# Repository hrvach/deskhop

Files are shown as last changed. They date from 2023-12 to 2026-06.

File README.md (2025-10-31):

# DeskHop - Fast Desktop Switching

Did you ever notice how, in the crazy world of tech, there's always that one quirky little project trying to solve a problem so niche that its only competitors might be a left-handed screwdriver and a self-hiding alarm clock?

I use two different computers in my daily workflow and share a single keyboard/mouse pair between them. Trying several USB switching boxes found on Amazon made me realize they all suffer from similar issues - it takes a while to switch, the process is quite clumsy when trying to find the button and frankly, it just doesn't get any better with time.

All I wanted was a way to use a keyboard shortcut to quickly switch outputs, paired with the ability to do the same by magically moving the mouse pointer between monitors. This project enables you to do both, even if your computers run different operating systems!

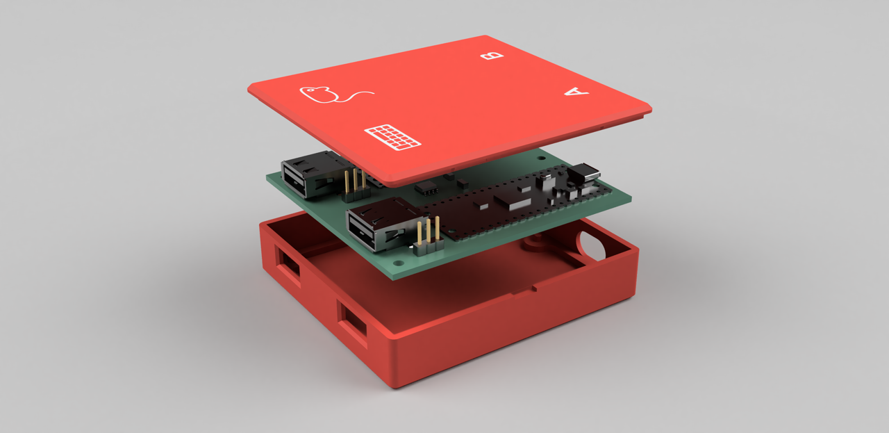
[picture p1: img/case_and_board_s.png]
DeskHop case and board


## Features

- Completely **[free and open source](https://certification.oshwa.org/de000149.html)**
- No noticeable delay when switching
- Simply drag the mouse pointer between computers
- No software installed
- Affordable and obtainable components (<15€)
- 3D printable snap-fit case
- Full Galvanic isolation between your outputs
- Works with Linux, macOS and Windows

[User Manual](misc/user-manual.pdf) is now available

Open Source Hardware Logo

------

## How it works

The device acts as an intermediary between your keyboard/mouse and the computer, establishing and maintaining connections with both computers at once. Then it chooses where to forward your mouse and keystrokes to, depending on your selection. Keyboard follows the mouse and vice versa, so just dragging the mouse to the other desktop will switch both.

## Mouse

To get the mouse cursor to magically jump across, the mouse hid report descriptor was changed to use absolute coordinates and then the mouse reports (that still come in relative movements) accumulate internally, keeping the accurate tally on the position.

When you try to leave the monitor area in the direction of the other monitor, it keeps the Y coordinate and swaps the maximum X for a minimum X, then flips the outputs. This ensures that the cursor seamlessly appears at the same height on the other monitor, enhancing the perception of a smooth transition.

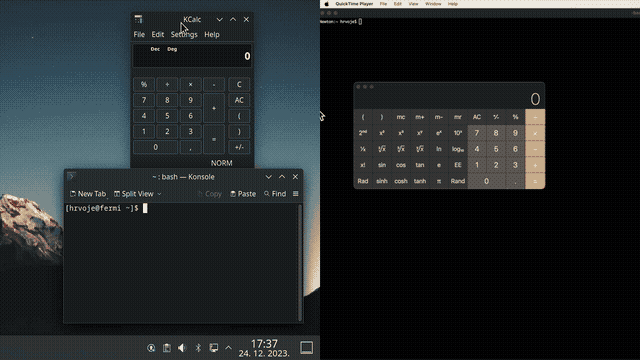
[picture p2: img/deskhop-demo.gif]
DeskHop Mouse Demo


<p align="center"> Dragging the mouse from Mac to Linux automatically switches outputs. </p>

------

The actual switch happens at the very moment when one arrow stops moving and the other one starts.

## Keyboard

Acting as a USB Host and querying your keyboard periodically, it looks for a preconfigured hotkey in the hid report (usually Ctrl + Caps Lock for me). When found, it will forward all subsequent characters to the other output.

To have a visual indication which output you are using at any given moment, you can repurpose keyboard LEDs and have them provide the necessary feedback.

It also remembers the LED state for each computer, so you can pick up exactly how you left it.

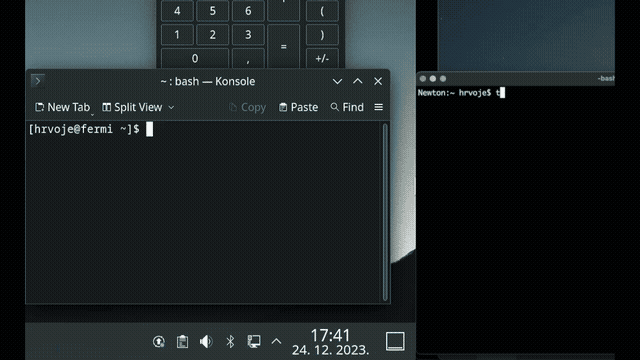
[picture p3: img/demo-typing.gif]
DeskHop Typing Demo


## How to build

To avoid version mismatch and reported path issues when building, as well as to save you from having to download a large SDK, the project now bundles minimal pico sdk and tinyusb.

On a Debian/Ubuntu systems, make sure to install these:

```shell
apt update
apt install \
    build-essential \
    cmake \
    gcc-arm-none-eabi \
    libnewlib-arm-none-eabi \
    python3
```

You should be able to build by running:

```shell
cmake -S . -B build
cmake --build build
```

additionally, to rebuild web UI check webconfig/ and execute ```./render.py```, you'll need jinja2 installed.

An alternative can be to use docker via 'docker compose' or 'docker-compose':
```
docker-compose -f misc/docker.yml run --rm build_container
```
This ensures reproducible builds.

To rebuild the disk, check disk/ folder and run ```./create.sh```, tweak to your system if needed. You'll need **dosfstools** (to provide mkdosfs),

## Using a pre-built image

Alternatively, you can use the [pre-built images](https://github.com/hrvach/deskhop/releases). Since version 0.6 there is only a single universal image. You need the .uf2 file which you simply copy to the device in one of the following ways:

## Upgrading firmware

**Option 1** - (firmware 0.6 and later) Put the device in "config mode" by simultaneously pressing **left ctrl + right shift + c + o**. Device your keyboard is plugged into will reboot and turn into a USB drive called "DESKHOP". All you need to do is copy the .uf2 file to it. Once image is verified, device will flash and reboot, then proceed to upgrade the other board. During this operation the led will blink. Once it's done, it will write flash and reboot, completing the operation.

_Note_ - This is not an actual generic USB drive, you can't use it to copy files to it.

**Option 2** - Using the ROM bootloader - hold the on-board button while connecting each Pico and copy the uf2 to the flash drive that appears. Images later than 0.6 support holding the button without having to fiddle around the power supply, but the "hold button while plugging" should always work, regardless of device state.

**Option 3** - CDC Flash Command (Debug builds only) - If the firmware was built with `DH_DEBUG_CDC_FLASH=ON`, you can trigger bootloader mode via CDC serial command:
```shell
echo -n 'flash' > /dev/tty.usbmodem11104
```
This immediately resets the device into bootloader mode where it appears as "RPI-RP2" drive. This feature is intended for development workflows.

## Misc features

### Mouse slowdown

Ever tried to move that YT video slider to a specific position but your mouse moves too jumpy and suddenly you are moving your hand super-carefully like you're 5 and playing "Operation" all over again?

**Press right CTRL + right ALT** to toggle a slow-mouse mode. The mouse pointer will slow down considerably, enabling you to get the finer precision work done and still have your mouse moving normally by quickly pressing the same keys again.

### Switch Lock

If you want to lock yourself to one screen, use ```RIGHT CTRL + K```.
This will make sure you won't accidentally leave your current screen. To turn off, press the same key combo again.

### Lock Both Screens

You can lock both computers at once by using ```RIGHT CTRL + L```.
To make use of this feature, first set up the OS for each output in config (since the shortcuts are different).

### Gaming Mode

If you're gaming, there is a chance your game might not work properly with absolute mouse mode. To address that issue, a **gaming mode** is introduced, toggled by ```LEFT CTRL + RIGHT SHIFT + G```. When in gaming mode, you are locked to the current screen and your mouse behaves like a standard relative mouse. This should also fix various virtual machine issues, currently unsupported operating systems etc.

### Screensaver

Supposedly built in to prevent computer from entering standby, but truth be told - it is just fun to watch. **Off by default**, will make your mouse pointer bounce around the screen like a Pong ball. When enabled, it activates after a period of inactivity defined in user config header and automatically switches off as soon as you send any output towards that screen.

Potential usage example - I have a buggy USB dock that won't resume video from standby, so not allowing it to sleep can be a handy workaround.

## Hardware

[The circuit](schematics/DeskHop_v1.1.pdf) is based on two Raspberry Pi Pico boards, chosen because they are cheap (4.10 € / pc), can be hand soldered and most suppliers have them in stock.

The Picos are connected using UART and separated by an Analog Devices ADuM1201 dual-channel digital isolator (~3€) or a much cheaper, faster and pin-compatible TI ISO7721DR (~1.5€) which is the preferred choice.

While they normally don't have support for dual USB, thanks to an [amazing project](https://github.com/sekigon-gonnoc/Pico-PIO-USB) where USB is implemented using the programmable IO wizardry found in RP2040, there is support for it to act both as an USB host and device.

## PCB [updated]

To keep things as simple as possible for DIY builds, the traces were kept on one side and the number of parts kept to a minimum.

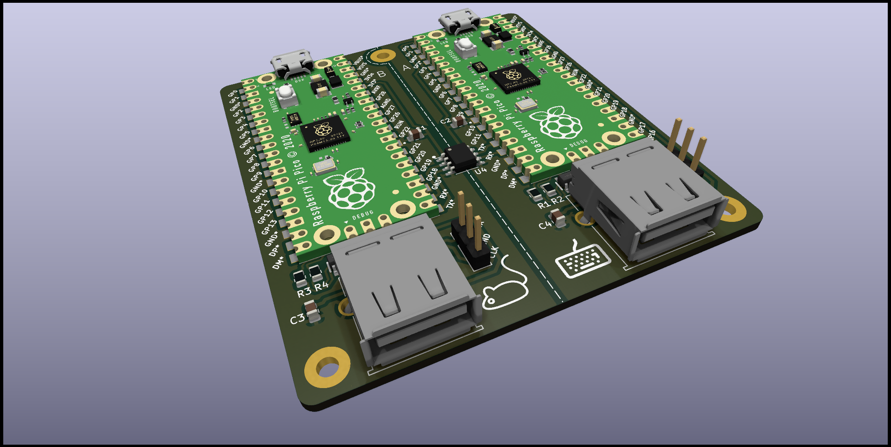
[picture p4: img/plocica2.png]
PCB Image


USB D+/D- differential lines should be identical in length, but they are slightly asymmetrical on purpose to counter the length difference on the corresponding GPIO traces PICO PCB itself, so the overall lengths should match.

Zd (differential impedance) is aimed as 90 ohm (managed to get ~107, close enough :)).

The thickness is designed to be 1.6 mm for snap-fit to work as expected.

There are 2 versions of the PCB (no major differences for the user). Original (v1.0) is easier to solder and assemble, while v1.1 offers some upgrades like:

- added ESD protection (TPD4E1U06DBVR)
- added VBUS capacitor for the keyboard/mouse connectors
- silkscreen orientation markings
- holes for clone boards with headers pre-soldered and easier alignment
- USB 27 ohm resistors

  This version is slightly more difficult to hand solder due to the small transient voltage suppressor IC and 0805 resistors, but it's totally doable. TVS can in theory be omitted (not advised) and it will still work.

Upcoming - board with bare rp2040s that doesn't need Picos, is smaller and more convenient.

## Case

Since I'm not very good with 3d, the case is [simple and basic](case/) but does the job. It should be easy to print, uses ~33g of filament and takes a couple of hours.

Horizontal PCB movements are countered by pegs sliding through holes and vertical movements by snap-fit lugs on the sides - no screws required. The case was given a slight redesign to feature the logo and two additional snap-fit lugs, so it provides a better seal.

Micro USB connectors on both boards are offset from the side of the case, so slightly larger holes should allow for cables to reach in.

The lid is of a snap-fit design, with a screwdriver slot for opening. The markings on top are recessed and can be finished with e.g. crayons to give better contrast (or simply left as-is).

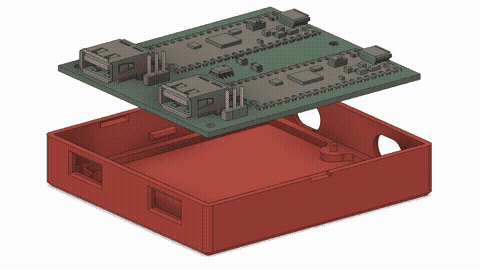
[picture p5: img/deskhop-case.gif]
DeskHop with 3D Printed Case


## Bill of materials

<details closed>
  <summary>Click here to view original PCB v1.0 BOM</summary>

| Component | Qty | Unit Price / € | Price / €|
|---|-----|---|---|
| Raspberry Pi Pico  | 2 | 4.10 | 8.20 |
| ADuM1201BRZ | 1 | 2.59 | 2.59 |
| Cap 1206 SMD 100nF | 2 | 0.09 | 0.18 |
| USB-A PCB conn. | 2 | 0.20 | 0.40 |
| Headers 2.54 1x03  | 2 | 0.08 | 0.16 |
| | | | |
| | | Total | 11.53 |

TI ISO7721DR can be used instead of the ADuM - it's pin-compatible, much cheaper and with better specs.

</details>

### PCB v1.1

| Component | Part | Qty | Unit Price / € | Price / €|
|---|---|-----|---|---|
| U1, U2 | Raspberry Pi Pico | 2 | 4.10 | 8.20 |
| J1, J4 | USB-A PCB conn. | 2 | 0.20 | 0.40 |
| U4 | TI ISO7721DR | 1 | 1.40 | 1.40 |
| | (**OR** ADuM1201BRZ)| | | |
| C1, C2 | Cap 0805 SMD 100nF  | 2 | 0.09 | 0.18 |
| R1, R2, R3, R4 | Res 0805 SMD 27ohm  | 4 | 0.03 | 0.12 |
| U3, U5 | TPD4E1U06DBVR | 2 | 0.31 | 0.62 |
| C3, C4 | Cap 4.7uF SMD 0805  | 2 | 0.07 | 0.14 |
| J2, J3 | Headers 2.54 1x03 | 2 | 0.08 | 0.16 |
| | | | | |
| | | | Total | 11.22 |

USB-A connector can be Molex MX-67643-0910 or a cheaper/budget one that shares the same dimensions.

Additional steps:

- making the PCB ([Gerber provided](pcb/), choose 1.6 mm thickness)
- 3d printing the case ([stl files provided](case/), ~33g filament)

## Assembly guide

If you have some experience with electronics, you don't need this. However, some of you might not, and in that case this video might help guide you through the process. Please note, after soldering you should clean the flux from the PCB to prevent corrosion.

The standard process to do that is using isopropyl alcohol and an old toothbrush. But guess what? I'm not putting my old toothbrush online, so you'll just have to improvise that part :)

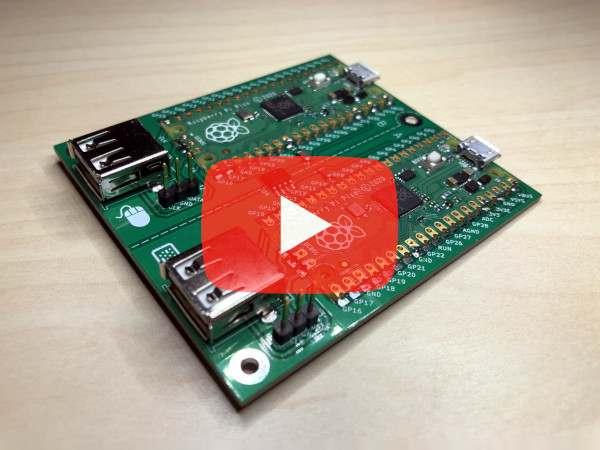
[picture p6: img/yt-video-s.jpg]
PCB Assembly Guide (https://www.youtube.com/watch?v=LxI9NYi_oOU)


[NOTE] The video assembly guide covers pcb v1.0. The revised version is very similar and the procedure is basically the same.

## Usage guide

### Keyboard shortcuts - (fw versions 0.68+)

_Config_:

- ~~```Left Shift```~~ ```Left Ctrl + Right Shift + C + O``` - enter config mode
- ```Right Shift + F12 + D``` - remove flash config
- ```Right Shift + F12 + Y``` - save screen switch offset

_Usage_:

- ```Right CTRL + Right ALT``` - Toggle slower mouse mode
- ```Right CTRL + K``` - Lock/Unlock mouse desktop switching
- ```Right CTRL + L``` - Lock both outputs at once (set output OS before, see shortcuts below)
- ~~```Left Shift```~~ ```Left CTRL + Right Shift + G``` - Toggle gaming mode (lock to screen, act as standard mouse)
- ```Left CTRL + Right Shift + S``` - Enable screensaver
- ```Left CTRL + Right Shift + X``` - Disable screensaver
- ```Left CTRL + Caps Lock``` - Switch between outputs

Note: some keyboards don't send both shifts at the same time properly, that's why the shortcut was changed - to work for everyone. Apologies for the confusion.

### Switch cursor height calibration

This step is not required, but it can be handy if your screens are not perfectly aligned or differ in size. The objective is to have the mouse pointer come out at exactly the same height.

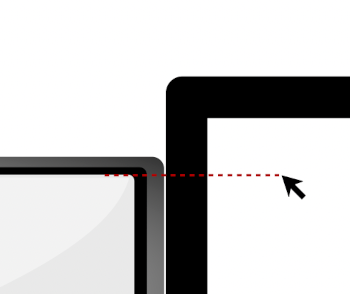
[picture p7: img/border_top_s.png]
Border height difference


Just park your mouse on the LARGER screen at the height of the smaller/lower screen (illustrated) and press ```Right Shift + F12 + Y```. Your LED (and caps lock) should flash in confirmation.

Repeat for the bottom border (if it's above the larger screen's border). This will get saved to flash and it should keep this calibration value from now on.

### Multiple screens per output

Windows and Mac have issues with multiple screens and absolute positioning, so workarounds are needed (still experimental). There is a better workaround under construction, but for now you have to set the operating system for each output and number of screens.

Your main screens need to be in the middle, and secondary screen(s) on the edges. To configure the actual options, open the web configuration page for your device.

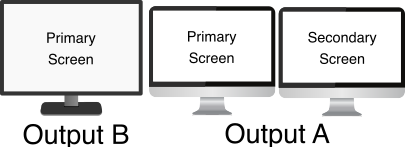
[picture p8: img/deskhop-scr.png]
Multiple screens per output


### Web configuration mode

Starting with fw 0.6, an improved configuration mode is introduced. To configure your device, follow these instructions:

1. Press Left Ctrl + Right Shift + C + O - your device will reboot and enter configuration mode (on the side your keyboard is plugged into). LED will keep blinking during the configuration session.

1. A new USB drive will appear named "DESKHOP" with a single file, config.htm

1. Open that file with Chromium / Chrome. Unfortunately FF is not supported right now, since they avoid implementing WebHID.

1. Click connect and allow deskhop device to pair.

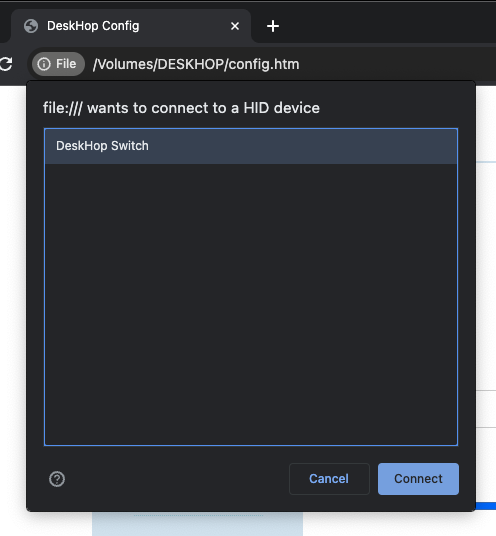
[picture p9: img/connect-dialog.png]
Web Browser with URL
   

1. Configure the options as you wish and click save to write to device.

1. Click "exit" in the menu to leave configuration mode for added safety.

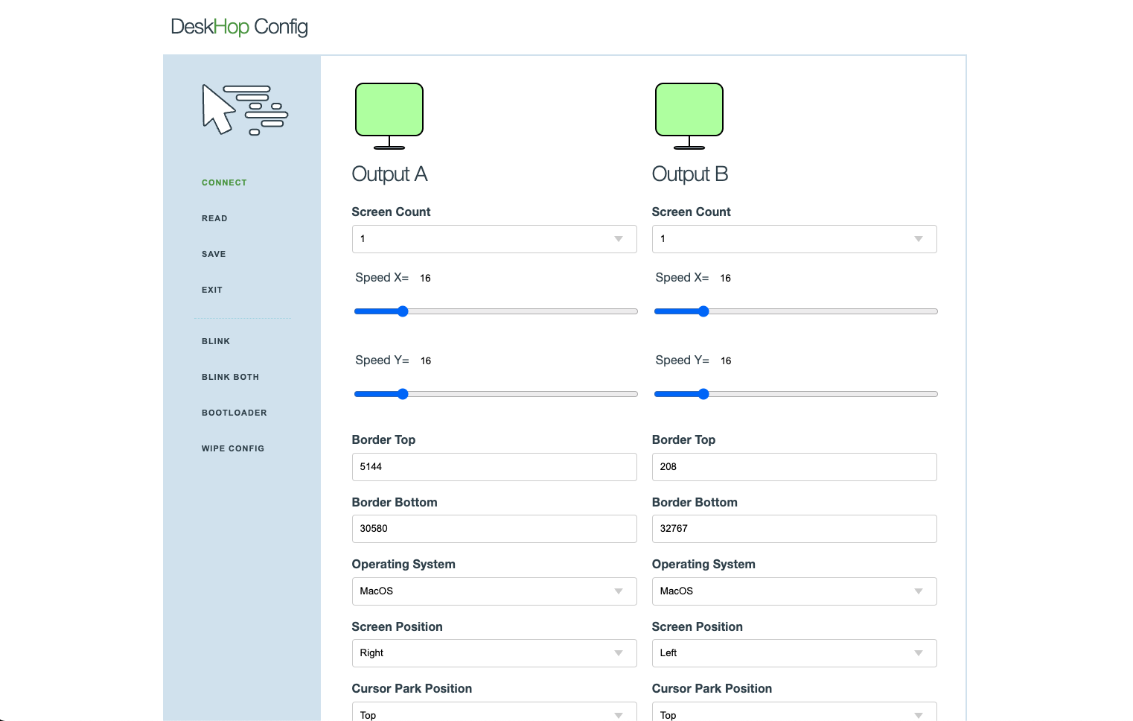
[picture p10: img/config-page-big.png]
Web Config
   

<details closed>
  <summary>Linux doesn't see device? Click here.</summary>

**Q**: Chromium on Linux doesn't work.

**A**: You probably need to tweak /dev permissions or create a corresponding udev rules file and make sure your user is in the right group, like so:

/etc/udev/rules.d/99-deskhop.rules

```plain
KERNEL=="hidraw*", SUBSYSTEM=="hidraw", ATTRS{idVendor}=="1209", ATTRS{idProduct}=="c000", GROUP="plugdev", MODE="0660"
```

</details><br />

**Q**: Why not simply create a nice online web page like Via instead of dealing with this weird USB drive thing?

**A**: Loading javascript from a random online location that interacts with your input devices is a potential security risk. The configuration web page is local only and nothing is ever loaded externally.

Please note the config web page is not "weird" because of deliberate obfuscation - it's self-decompressing due to very limited storage. Entire source is 100% open and a part of this repo. You are encouraged to rebuild everything yourself.

### Functional verification

When you connect a new USB peripheral, the board will flash the led twice, and instruct the other board to do the same. This way you can test if USB and outgoing communication works for each board.

Do this test by first plugging the keyboard on one side and then on the other. If everything is OK, leds will flash quickly back and forth in both cases.

## Security and Safety

Some features are missing on purpose, despite the fact it would make the device easier to use or simpler to configure. Here is a quick breakdown of these decisions:

- There is no copy-paste or _any_ information sharing between systems. This prevents information leakage.
- No webhid device management without explicit user consent. No inbound connectivity from the output computers, with the only exception of standard keyboard LED on/off messages and hard limited to 1 byte of data.
- No FW upgrade triggering from the outputs. Only explicit and deliberate user action through a special keyboard shortcut may do that.
- No plugged-in keyboard/mouse custom endpoints are exposed or information forwarded towards these devices. Their potential vulnerabilities are effectively firewalled from the computer.
- No input history is allowed to be retained.
- No device-initiated keystrokes, for any reason. Only thing that comes out is what you type/trigger.
- Outputs are physically separated and galvanically isolated with a minimal isolation voltage of 2kV.
- All packets exchanged between devices are of fixed length, config options transferred are limited to a short list. Most options are read-only. Cross-device firmware upgrades can be disabled.
- There is no bluetooth or wifi, networking, Internet access, etc.
- No connected computer is considered trusted under any circumstances.
- Configuration mode is automatically disabled after a period of inactivity.
- Entirety of the code is open source, without any binary blobs and thoroughly commented to explain its purpose. I encourage you to never trust anyone and always make sure you know what you are running by doing a manual audit.

This still doesn't guarantee anything, but I believe it makes a reasonable set of ground rules to keep you safe and protected.

## FAQ

1. I just have two Picos, can I do without a PCB and isolator?

   _Sure. Having an isolator is recommended but it should work without it._

1. What happens if I have two different resolutions on my monitors?

   _The mouse movement is done in abstract coordinate space and your computer figures out how that corresponds with the physical screen, so it should just work._

1. Where can I buy it?

   _I'm not selling anything, this is just a personal, non-commercial hobby project._

   _**UPDATE 1**: It seems you can order it in QTY of 1 (for either PCB, assembled PCB or a fully assembled device) from [Elecrow if you follow this link](https://www.elecrow.com/deskhop-fast-desktop-switching.html)_
   _As reported by users, your **board will arrive blank** and you have to write the firmware yourself._

   _**UPDATE 2**: I never asked Elecrow for anything, but a couple of days ago they offered to sponsor the project with a small budget that will be used for future board prototyping. Since my goal is to create a better board with more than 2 outputs etc, I believe prototyping services might be beneficial to the project._

1. When the active screen is changed via the mouse, does the keyboard follow (and vice versa)?

   _Yes, the idea was to make it behave like it was one single computer._

1. Will this work with keyboard/mouse combo dongles, like the Logitech Unifying receiver?

   _It should work. After a recent FW update, support for combo receivers should be much better._

1. Will this work with wireless mice and keyboards that have separate wireless receivers (one for the mouse, another for the keyboard)?

   _It should work - tried an Anker wireless mouse with a separate receiver and that worked just fine._

1. I have issues with build or compilation

   _Check out the [Troubleshooting Wiki](https://github.com/hrvach/deskhop/wiki/Troubleshooting) that might have some answers._

## Software Alternatives

There are several software alternatives you can use if that works in your particular situation.

1. [Barrier](https://github.com/debauchee/barrier) - Free, Open Source
1. [Input Leap](https://github.com/input-leap/input-leap) - Free, Open Source
1. [Synergy](https://symless.com/synergy) - Commercial
1. [Mouse Without Borders](https://www.microsoft.com/en-us/garage/wall-of-fame/mouse-without-borders/) - Free, Windows only
1. [Universal Control](https://support.apple.com/en-my/HT212757) - Free, Apple thing

## Shortcomings

- Windows 10 broke HID absolute coordinates behavior in KB5003637, so you can't use more than 1 screen on Windows (mouse will stay on the main screen). There is an experimental workaround with a better one on the way.
- Code needs cleanup, some refactoring etc.
- Not tested with a wide variety of devices, I don't know how it will work with your hardware. There is a reasonable chance things might not work out-of-the-box.
- Advanced keyboards (with knobs, extra buttons or sliders) will probably face issues where this additional hardware doesn't work.
- Super-modern mice with 300 buttons might see some buttons not work as expected.
- NOTE: **Both computers need to be connected and provide power to the USB for this to work** (as each board gets powered by the computer it plugs into). Many desktops and laptops will provide power even when shut down nowadays. If you need to run with one board fully disconnected, you should be able to use a USB hub to plug both keyboard and mouse to a single port.
- MacOS has issues with more than one screens, latest firmware offers an experimental workaround that fixes it.

## Progress

So, what's the deal with all the enthusiasm? I can't believe it - please allow me to thank you all! I've never expected this kind of interest in a simple personal project, so the initial features are pretty basic (just like my cooking skills) and mostly cover my own usecase. Stay tuned for firmware updates that should bring wider device compatibility, more features and less bugs. As this is a hobby project, I appreciate your understanding for being time-constrained and promise to do the best I can.

Planned features:

- Better workarounds for multiscreen windows and macos
- Transparent / Gaming mode
- Support for more than 2 outputs
- Improvements on the configuration UI
- ... and more!

Working on a _lite_ version which provides basic functionality with just a single Pico W board, lowering the cost even further and enabling you to try it out even with no added hardware or PCB.

Mouse polling should now work at 1000 Hz (the dips in the graph is my arm hurting from all the movement :-)):

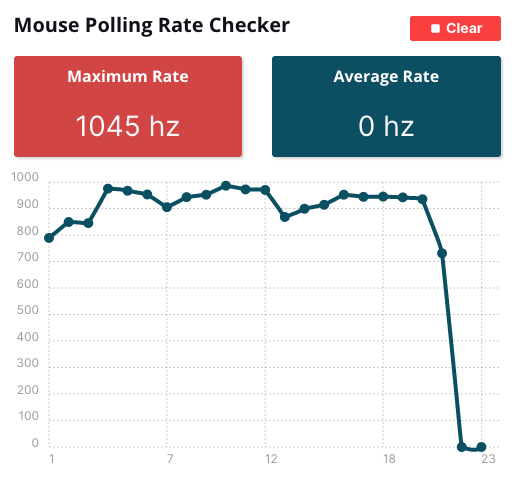
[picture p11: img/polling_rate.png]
Mouse polling rate


## Sponsor / donate

I'm NOT doing this for profit or any other reason except to try and help people by creating a better working environment for everyone.
If you want to support the project further, please consider making a small donation towards a charity like **Doctors Without Borders**.



Please allow me to thank everyone who helped or considering it!

## Disclaimer

I kindly request that anyone attempting to build this project understands and acknowledges that I am not liable for any injuries, damages, or other consequences. Your safety is important, and I encourage you to approach this project carefully, taking necessary precautions and assuming personal responsibility for your well-being throughout the process. Please don't get electrocuted, burned, stressed or angry. Have fun and enjoy!

Happy switchin'!

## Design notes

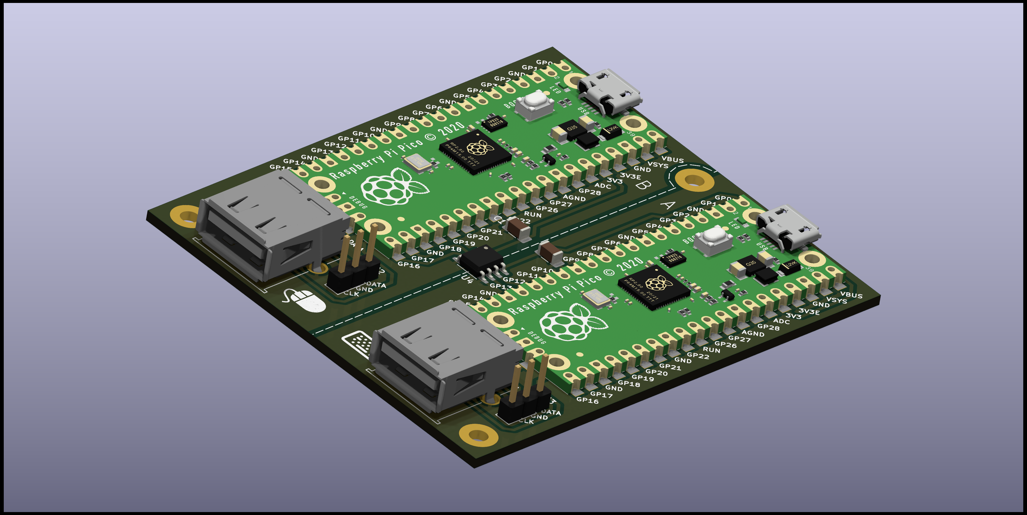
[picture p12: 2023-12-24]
img/pcb_render.png

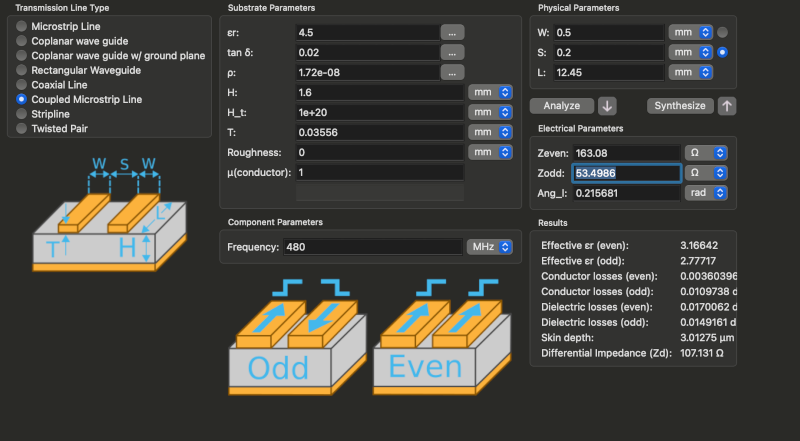
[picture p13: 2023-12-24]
img/impedance-calculation.png

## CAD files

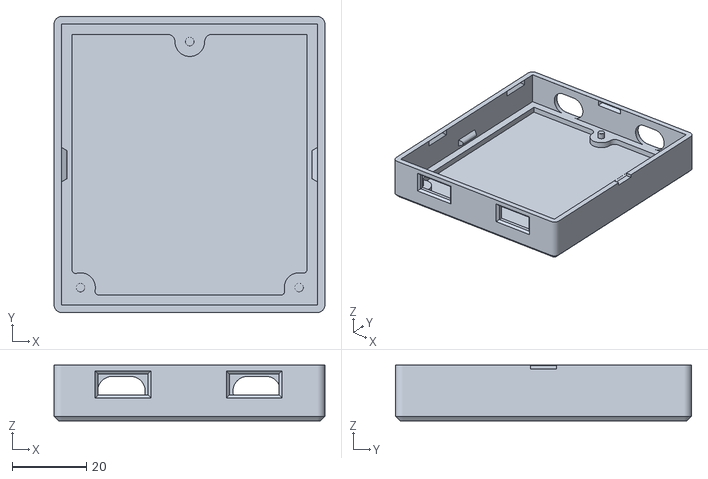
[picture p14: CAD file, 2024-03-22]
case/bottom.stl
73.0 x 79.8 x 15.0

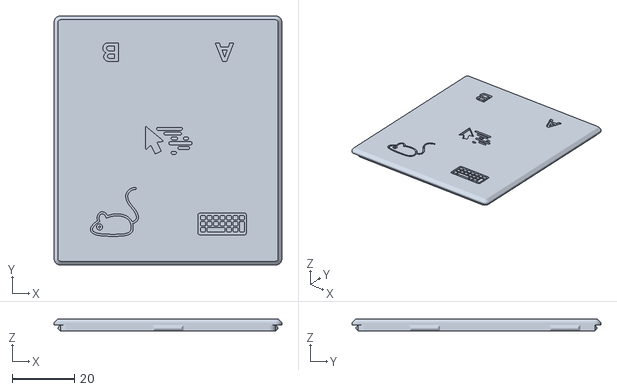
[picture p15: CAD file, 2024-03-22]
case/top.stl
73.0 x 79.8 x 4.00

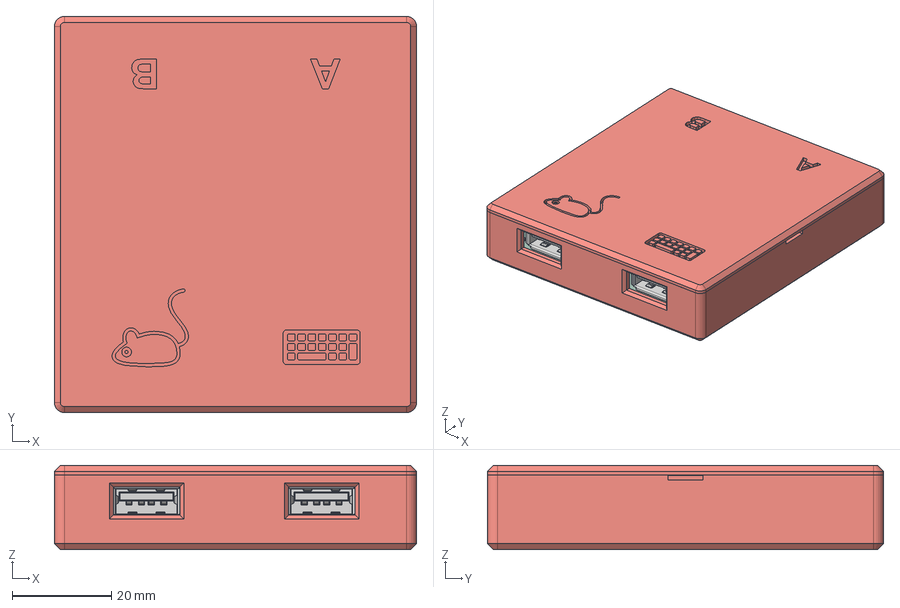
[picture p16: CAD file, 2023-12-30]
case/deskhop_case.step
73.0 x 79.8 x 17.0 mm
PCB
Box Top
Box Bottom

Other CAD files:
case/deskhop_case.f3d

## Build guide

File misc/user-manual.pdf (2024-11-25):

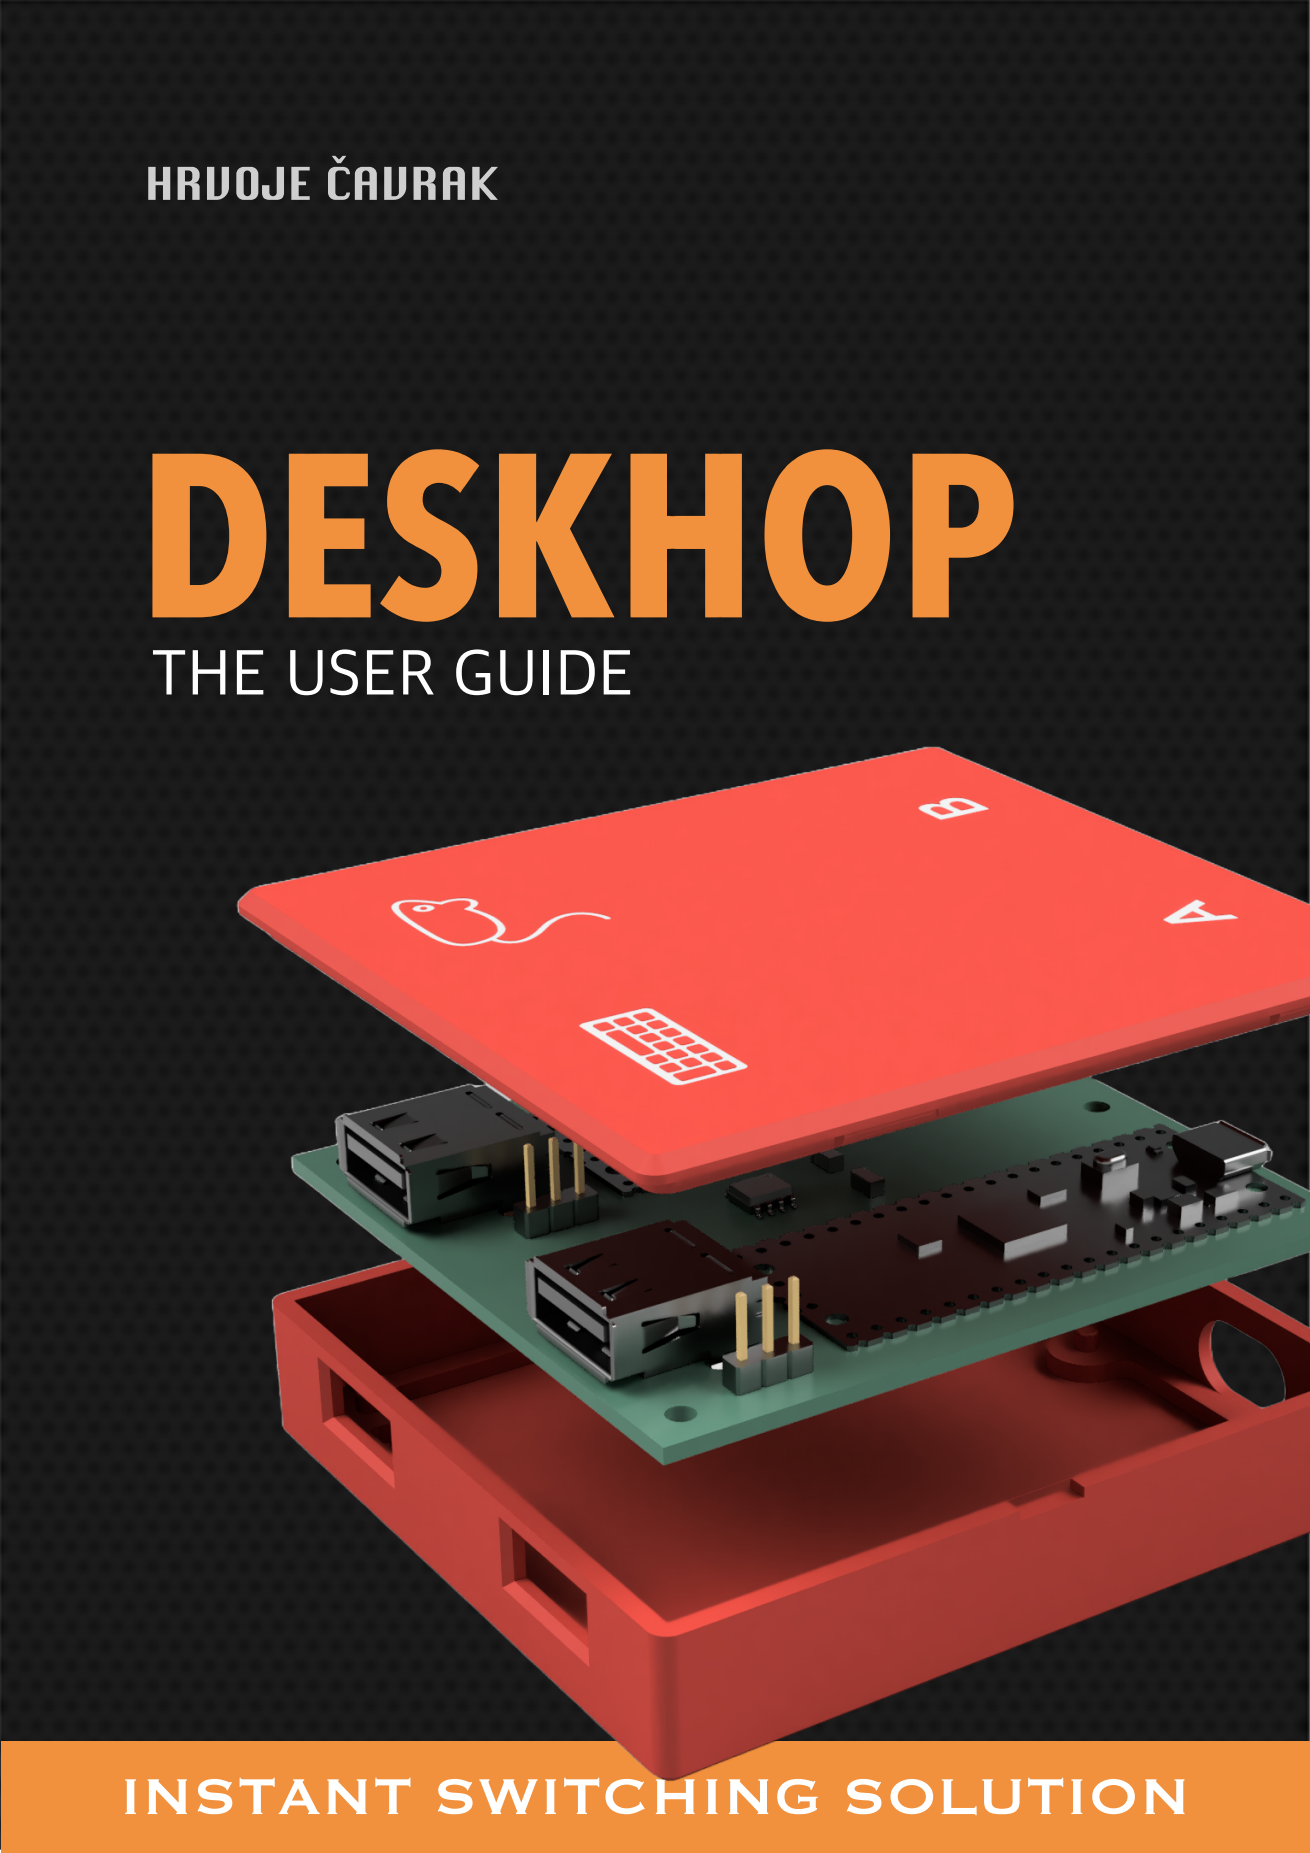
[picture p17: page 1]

DeskHop User Manual

## Contents

Foreword | 4
Chapter 1 - Installation | 5
Chapter 2 - Use | 6
Chapter 3 - Configuration | 7
Chapter 4 - Firmware Upgrade | 9
Chapter 5 - Assembly Guide | 10
Chapter 6 - Security and Safety | 14
Chapter 7 - Troubleshooting | 15
Appendix 1 - Schematics and Drawings | 16
Documentation Release History | 19
Hrvoje Čavrak | 2

DeskHop User Manual

DeskHop User Manual, First Edition by Hrvoje Čavrak, copyright (c) 2024

This manual covers DeskHop project (https://github.com/hrvach/deskhop) and is licensed under Creative Commons Attribution NoDerivatives (CC BY-ND 2.0). Project is certified by the Open Source Hardware Association as being fully open.

License Terms

You are free to copy and redistribute the material in any medium or format for any purpose, even commercially. The licensor cannot revoke these freedoms as long as you follow the license terms. You must give appropriate credit, provide a link to the license, and indicate if changes were made. You may do so in any reasonable manner, but not in any way that suggests the licensor endorses you or your use. If you remix, transform, or build upon the material, you may not distribute the modified material. You may not apply legal terms or technological measures that legally restrict others from doing anything the license permits.

Full license text can be found here: https://creativecommons.org/licenses/by-nd/2.0

Disclaimer Notice

This technical manual is provided as part of the DeskHop open source project. By utilizing, modifying, or distributing any part of this project or this manual, you agree to the following terms:

DeskHop - open source project, including all associated documentation and software, is distributed in the hope that it will be useful, but WITHOUT ANY WARRANTY; without even the implied warranty of MERCHANTABILITY or FITNESS FOR A PARTICULAR PURPOSE. In no event shall the contributors be liable for any claim, damages, or other liability, whether in an action of contract, tort, or otherwise, arising from, out of, or in connection with the software, blueprints, schematics or any other dealings.

You acknowledge that the use of the DeskHop software and the information contained in this manual is at your own risk. The authors and contributors do not assume any responsibility for errors, omissions, or damages resulting from the use of the device or this manual. By proceeding with the assembly, installation, use, or distribution of DeskHop, you signify your agreement to these terms and conditions. If you do not agree with these terms, please do not use the project or this manual.

Your safety is important, and I encourage you to approach this project carefully, taking necessary precautions and assuming personal responsibility for your well-being throughout the process. Please don’t get electrocuted, burned, stressed or angry. Have fun and enjoy!

Hrvoje Čavrak | 3

DeskHop User Manual

## Foreword

Many of us work across multiple computers on a daily basis - perhaps switching between a work laptop and a personal desktop, or managing multiple systems for development and testing. While this approach offers flexibility, it often makes us frustrated with using multiple keyboards or existing USB switches having poor performance.

This device was created as an intermediary between your keyboard/mouse and the computer, estab-lishing and maintaining connections with both computers at once. It then chooses where to forward your mouse and keystrokes to, depending on your selection. Keyboard follows the mouse and vice versa, so just dragging the mouse to the other desktop will instantly switch both.

In this manual, you’ll find some guidance covering everything from basic setup, firmware upgrade and advanced configuration options. I’ve structured the content primarily aimed at newcomers, as experienced users need little guidance. This being an open source project, you are encouraged to contribute – whether through sending patches, bug reports, or feature suggestions. Please allow me to thank you for considering to use this device and I hope it will help your daily work environment remain useful and serve you well in your future endeavours.

Special Thanks to:

- Jan Almeroth
- Mirko Šesto
- Łukasz Siudut
- Kevin P. Fleming
- Ellie Tomkins
- Alexey Korobko
- GitHub users OrpheeGT, chris-010, ak666666, chri2
- Everyone else who contributed in any way
Hrvoje Čavrak | 4

DeskHop User Manual

## Chapter 1 - Installation

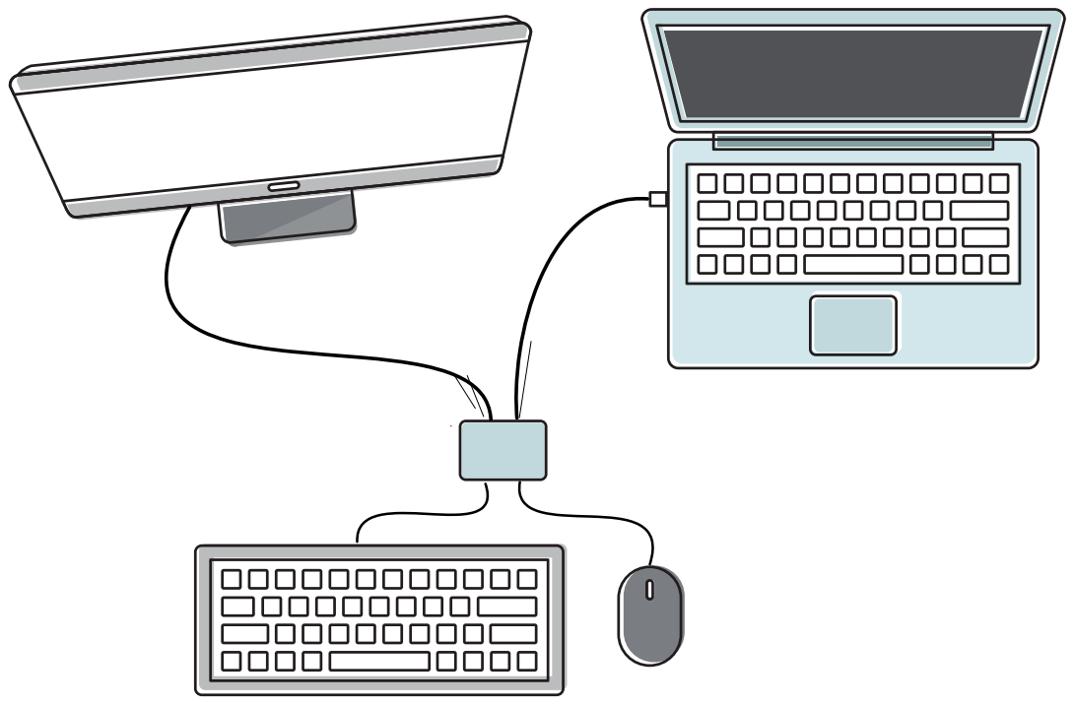
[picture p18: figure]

Figure 1: Connection Diagram

- If this is your first bring-up, flash firmware to each board (see chapter 4)
- Connect your mouse to the input USB port with a mouse icon
- Connect your keyboard to the input USB port with a keyboard icon
- Connect outputs to both computers with a micro-USB to USB cable
- Turn both computers on
ò

If everything is connected correctly, device LEDs will flash after you plug in your keyboard/mouse to indicate they are detected. Both computers need to be providing power to the device in order to properly function.

Hrvoje Čavrak | 5

DeskHop User Manual

## Chapter 2 - Use

Keyboard Shortcuts

During normal operation, these are the keyboard shortcuts you can use to trigger actions,

Action | Shortcut
Enter config mode | Left Ctrl + Right Shift + C + O
Enable screensaver | Left Ctrl + Right Shift + S
Disable screensaver | Left Ctrl + Right Shift + X
Gaming mode - lock to screen, act as standard mouse | Left Ctrl + Right Shift + G
Switch between outputs | Left Ctrl + Caps Lock
Wipe flash config | Right Shift + F12 + D
Save screen height offset | Right Shift + F12 + Y
Toggle slow mouse mode | Right Ctrl + Right Alt
Lock / Unlock mouse to current screen | Right Ctrl + K
Lock both computers at once (needs OS set in config) | Right Ctrl + L

Make sure you’re running the latest firmware, otherwise shortcuts might have changed or not imple-mented in your version.

Toggle slow mouse mode makes your mouse cursor move much slower, helping with precision work. Same shortcut turns the mode on and off again.

Gaming mode locks cursor to the current screen and converts the mouse to relative mode. This means it will work for games, virtual machines, multiple desktops etc. but you have to use the keyboard shortcut to switch.

Hrvoje Čavrak | 6

DeskHop User Manual

## Chapter 3 - Configuration

Set switching height offset

First thing to configure is the switching height offset. Unless you have two identical screens, chances are their heights don’t match. To make the mouse pointer come out at the same height on the other screen and improve user experience, it is necessary to tell the system what’s the height difference to

your screens.

To do this:

1. Leave your mouse cursor on the LARGER screen at the height of the smaller/lower screen (illustrated) and then press Right Shift + F12 +
Y. Your LED (and caps lock) should flash in confirmation.
2. Repeat for the bottom border (if needed). This will get saved to flash and it should keep this calibration value from now on.

Multi-monitor workarounds

Windows and Mac have issues with multiple screens and absolute positioning, so workarounds are needed (still experimental). There is a better workaround under construction, but for now you have to set the operating system for each output and number of screens.

Your main screens need to be in the middle, and secondary screen(s) on the edges. To configure the actual options, open the web configuration page for your device.

Starting config mode

Starting with fw 0.6, an improved configuration mode is introduced. To configure your device, follow these instructions:

1. Press Left Ctrl + Right Shift + C + O - your device will reboot and enter configuration mode (on the side your keyboard is plugged into). On-board LED and caps lock led will keep blinking during the configuration session.
2. A new USB drive will appear named “DESKHOP” with a single file, config.htm
3. Open that file with Chromium / Chrome. Unfortunately FF is not supported right now, since they avoid implementing WebHID.
4. Click connect and allow deskhop device to pair.
Hrvoje Čavrak | 7

DeskHop User Manual

The reason this is served locally instead of a more convenient webpage somewhere online and webhid always available is for security reasons.


Figure 2: If everything went well, you should be seeing this config page

Any changes you made should be signalled to the device immediately after e.g. moving the slider or losing focus on an input field. To finish configuration, click save and exit.

Explaining the options:

- Screen count means how many desktops you have connected.
- Speed X and Y allow you to tweak mouse speed on each output
- Border top and bottom are weird-looking numbers which represent switching height offsets. Recommendation is to configure this using the method described above for simplicity. Values go from 0 (top) to 32767 (bottom).
- Cursor park position defines where the cursor will be moved on the computer which is not currently active
- Screensaver prevents your computer from sleeping, you can choose pong (cursor bounces around), jitter (cursor moves 1 pixel) or none (off).
- Idle time is how soon screensaver kicks in and max time is how long is it allowed to run. Both values are in microseconds.
Hrvoje Čavrak | 8

DeskHop User Manual

- Force mouse boot mode initializes the mouse in a simple mode that might make it work in case you’re having issues.
- Enforce ports is another fix for misbehaving devices.
- Keyboard led as indicator allows using caps lock for signalling.
ò

Flashing caps lock LED is there to remind you that the device is in configuration mode. If there is no config activity for a while, your device will reboot back to normal mode for security reasons.

## Chapter 4 - Firmware Upgrade

If you just finished soldering your board or got it somewhere pre-assembled, it likely doesn’t have any software programmed yet. To make it operational, it is essential to first copy the software you either built yourself or got as the official binary released on GitHub.

Initial Firmware Deployment

1. Go to https://github.com/hrvach/deskhop/releases and pick the latest stable release
2. Download the deskhop.uf2 file
3. For EACH of the two Pico boards, hold the BOOTSEL button while plugging in the microusb cable (the other end needs to already be plugged into your computer).

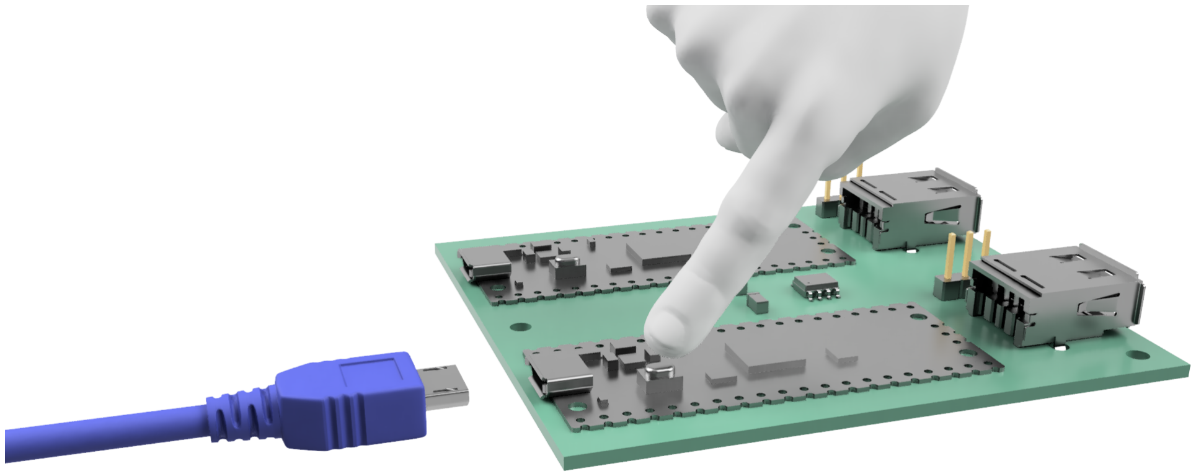
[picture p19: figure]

Figure 3: Hold the button while plugging the cable in

4. A new USB storage drive will appear, copy deskhop.uf2 there and unplug the cable
5. Repeat the procedure for the other Pico board
Hrvoje Čavrak | 9

DeskHop User Manual

This procedure is your means of recovery in case anything goes wrong at any point. Loader being in ROM, you can always use this procedure to recover from a bad flash or any other issue you might

encounter.

Existing Firmware Upgrade

If you’re running an existing deskhop firmware already and want to upgrade to a newer release, you need to:

1. Download the deskhop.uf2 file from https://github.com/hrvach/deskhop/releases
2. Press LEFT CTRL + RIGHT SHIFT + “c” + “o” to enter config mode
3. USB storage drive will appear (on the output where the keyboard is plugged in), copy deskhop.uf2 to it but don’t unplug.
4. First one board will flash, then another. Wait until nothing is flashing anymore and you’re done.

When upgrading, it’s sufficient to only do one side, the other side will upgrade automatically.

## Chapter 5 - Assembly Guide

Video guide

To make assembly easier, there is a video guide to lead you through the process:

https://www.youtube.com/watch?v=LxI9NYi_oOU

It is based on the older board revision v1.0 which is easier to hand-assemble but should provide enough guidance for the newer version as well.

The firmware has been unified in the meantime, so instead of board_A.uf2 and board_B.uf2 mentioned in the video, there is just one file now and the procedure is identical for both Picos.

Hrvoje Čavrak | 10

DeskHop User Manual

PCB v1.1 Step-by-Step Assembly

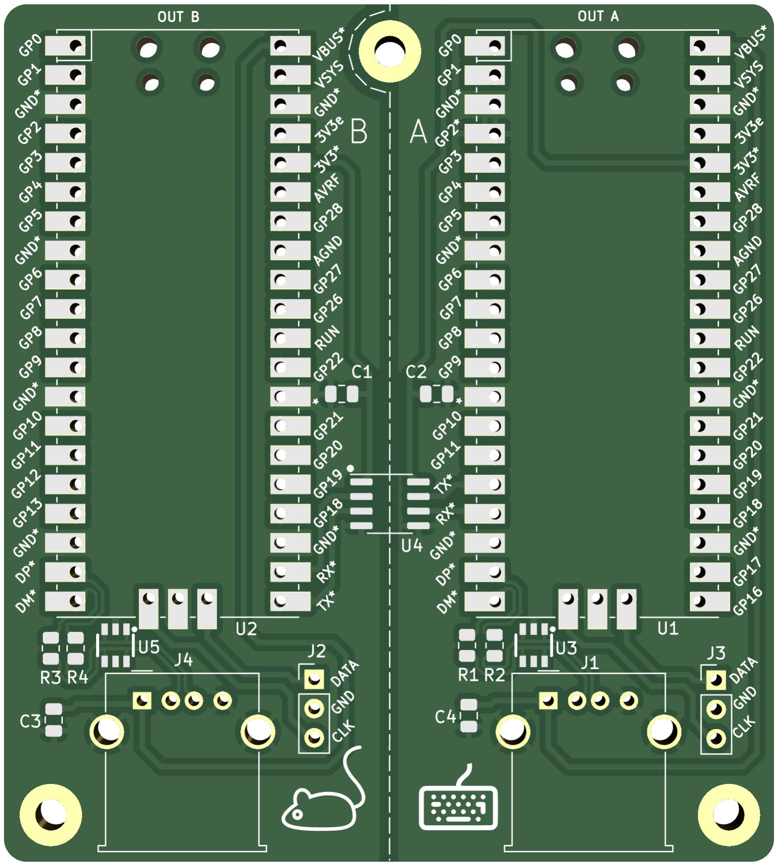
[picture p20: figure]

Figure 4: Start with a blank PCB

1. Solder the U3 and U5 ICs first. These are TPD4E1U06 TVS diode arrays here to protect against static electricity discharge that could ruin your board.

They are the hardest to do - the board would still work without them, but it is highly recommended to have them in there. Careful with positioning, solder bridges you’ll fix with some flux and solder wick.

Figure 5: Make sure the dots match (pin 1 is oriented towards the Pico boards)

2. Solder the U4 second, this is the TI ISO7721DR (or ADuM1201) Digital Isolator in SOIC-8, its role is to make sure your computers are isolated from each other.
Hrvoje Čavrak | 11

DeskHop User Manual

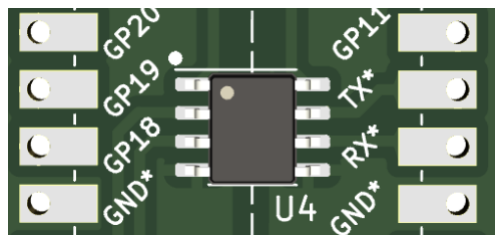
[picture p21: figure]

Figure 6: Make sure the dots match (pin 1 is oriented towards out B)

3. Now do R1 - R4, these are 27 ohm, 0805 resistors. Orientation doesn’t matter. While at it, also do C3 and C4 - these are 4.7uF capacitors in 0805 size.

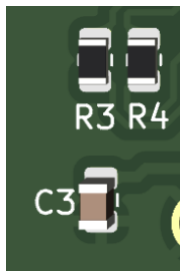
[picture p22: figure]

Figure 7: 27 ohm resistors, 4.7uF capacitor

4. Solder C1 and C2, these are 100nF capacitors in 0805, just above U4. Orientation doesn’t matter.

Figure 8: 100 nF Capacitors

5. Solder the USB connectors marked J1/J4 and SWD debugging header marked J2/J3, check the video for guidance. J2 and J3 can be omitted if you don’t plan to do any debugging.

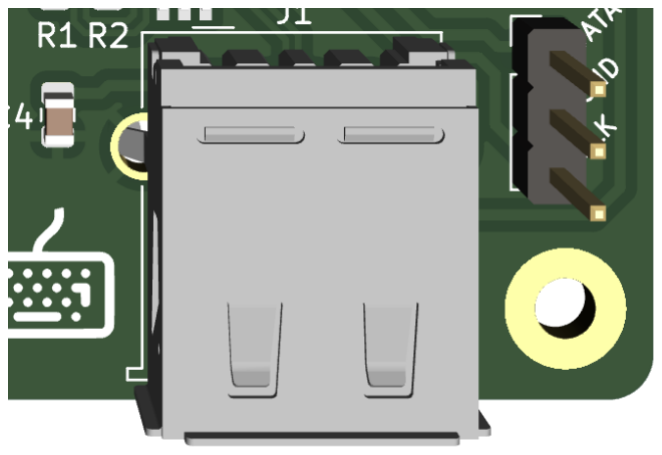
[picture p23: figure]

Figure 9: USB connector

Hrvoje Čavrak | 12

DeskHop User Manual

6. Solder the Picos. Only pins marked with a little asterisk are required but it’s ok to solder everything.

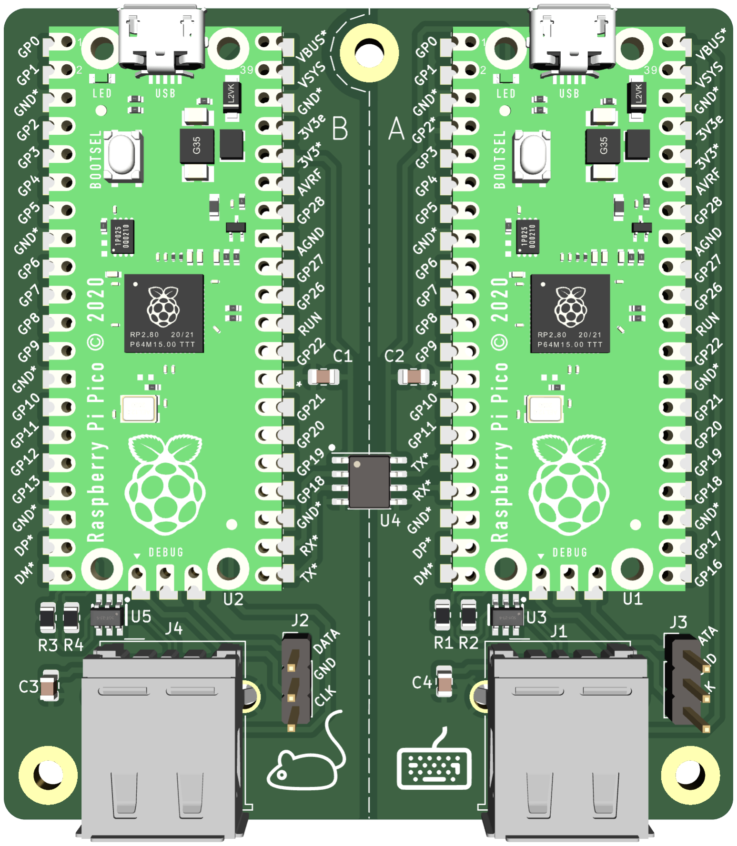
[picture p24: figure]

Figure 10: Finished board

First tack one end, make sure it’s centered perfectly. If not, reheat and retry. Never solder more than one pin until it is positioned exactly right. Check video for guidance.

Buying the Right Components

This is what you’ll need in order to complete the board.

Component | Part | Qty
U1, U2 | Raspberry Pi Pico | 2
J1, J4 | USB-A PCB conn. | 2
Hrvoje Čavrak | 13

DeskHop User Manual

Component | Part | Qty
U4 | TI ISO7721DR | 1
| (OR ADuM1201BRZ)
C1, C2 | Cap 0805 SMD 100nF | 2
R1, R2, R3, R4 | Res 0805 SMD 27ohm | 4
U3, U5 | TPD4E1U06DBVR | 2
C3, C4 | Cap 4.7uF SMD 0805 | 2
J2, J3 | Headers 2.54 1x03 | 2

None of these can be considered rare or hard to obtain, so most online stores (Mouser, DigiKey, Farnell, Reichelt) should have them in stock in sufficient quantities.

## Chapter 6 - Security and Safety

Some features are missing on purpose, despite the fact it would make the device easier to use or simpler to configure. Here is a quick breakdown of these decisions:

Data Security

- There is no copy-paste or any information sharing between systems. This prevents information leakage.
- No input history is allowed to be retained.
- No device-initiated keystrokes, for any reason. Only thing that comes out is what you type/trigger.

Hardware Security

- Outputs are physically separated and galvanically isolated with a minimal isolation voltage of 2kV.
- There is no bluetooth or wifi, networking, Internet access, etc.
Hrvoje Čavrak | 14

DeskHop User Manual

Access Control

- No webhid device management without explicit user consent. No inbound connectivity from the output computers, with the only exception of standard keyboard LED on/off messages and hard limited to 1 byte of data.
- All packets exchanged between devices are of fixed length, config options transferred are limited to a short list. Most options are read-only. Cross-device firmware upgrades can be disabled.

Device Protection

- No connected computer is considered trusted under any circumstances.
- Configuration mode is automatically disabled after a period of inactivity.
- No plugged-in keyboard/mouse custom endpoints are exposed or information forwarded towards these devices. Their potential vulnerabilities are effectively firewalled from the computer.
- No FW upgrade triggering from the outputs. Only explicit and deliberate user action through a special keyboard shortcut may do that.

Transparency

- Entirety of the code is open source, without any binary blobs and thoroughly commented to explain its purpose. I encourage you to never trust anyone and always make sure you know what you are running by doing a manual audit.

This still doesn’t guarantee anything, but I believe it makes a reasonable set of ground rules to keep you safe and protected.

## Chapter 7 - Troubleshooting

Hopefully, you’re just skipping this chapter. If not, here are some hints that might help you with diagnostics and debugging:

Connect both outputs, then plug in the keyboard to board A. LEDs should flash quickly back and forth. This means board A recognises the keyboard as USB device, and is able to talk to board B and vice-versa.

If both LEDs flash in both cases, all is good!

If only one LED blinks, the board talks to your USB device correctly but cannot send messages to the other board. Check #1 or #2 in Wiring and Assembly section depending on the board.

Hrvoje Čavrak | 15

DeskHop User Manual

If no LEDs flash after plugging in, this means board A can’t talk to your USB device. Check #4 in Wiring and Assembly section.

Wiring and Assembly

1. Pressing caps-lock toggles leds correctly but mouse only works on output B
- Check U4 pin 3 connected to pico B pin 21 (GPIO 16)
- Check U4 pin 6 connected to pico A pin 17 (GPIO 13)
2. Moving the mouse toggles leds correctly but keyboard only works on output A
- Check U4 pin 2 connected to pico B pin 22 (GPIO 17)
- Check U4 pin 7 connected to pico A pin 16 (GPIO 12)
3. Keyboard only works on A, mouse only works on B
- Check both 1 and 2
- If none of this worked, check the remaining pins on the U4 (3.3v, GND) on both sides.
4. Keyboard/mouse don’t work on one or both boards
- Make sure you have the latest release and plug in the keyboard to board A. If no LEDs flash:

– Check if Pico pads marked GP14, GP15, VBUS have been soldered.
– Check if all 4 USB-A pins are soldered correctly.
- Repeat for board B.

Mouse moves weirdly

Right Shift + F12 + D resets saved settings which might end in resolving your problem if it’s due to the wrong config being saved in flash.

If nothing else works

Try reporting your issue on GitHub, we’ll do our best to help you out.

## Appendix 1 - Schematics and Drawings

Hrvoje Čavrak | 16

# 1 GPIO7

# 1 GPIO7

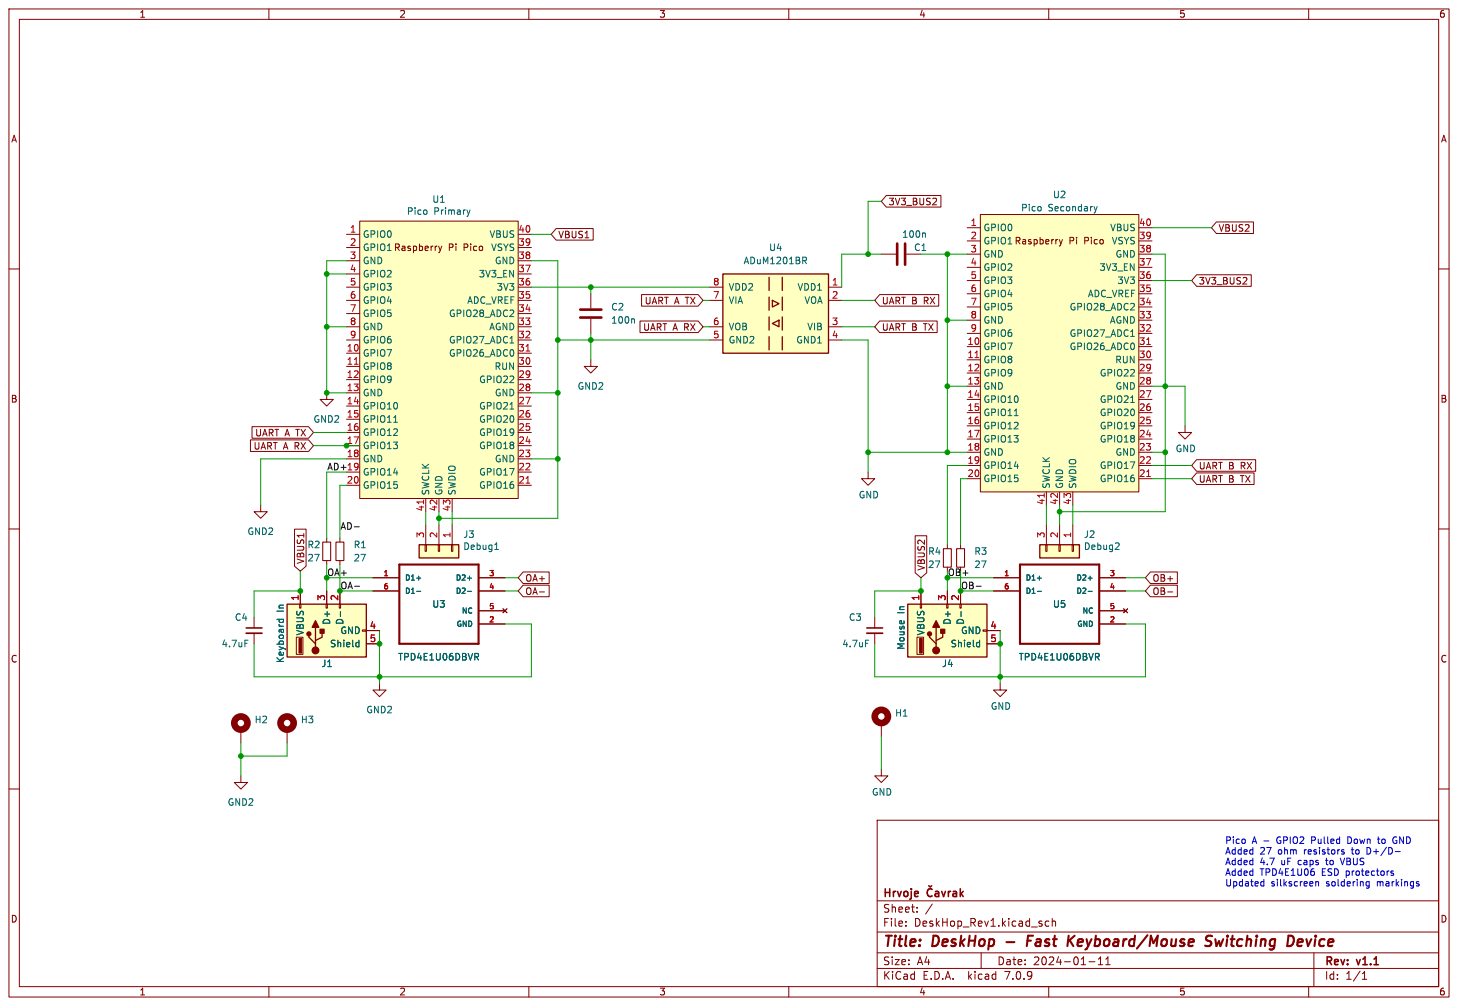
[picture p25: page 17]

1 VOA
2 VIB
File: DeskHop_Rev1.kicad_sch Sheet: / Hrvoje þÿavrak R3

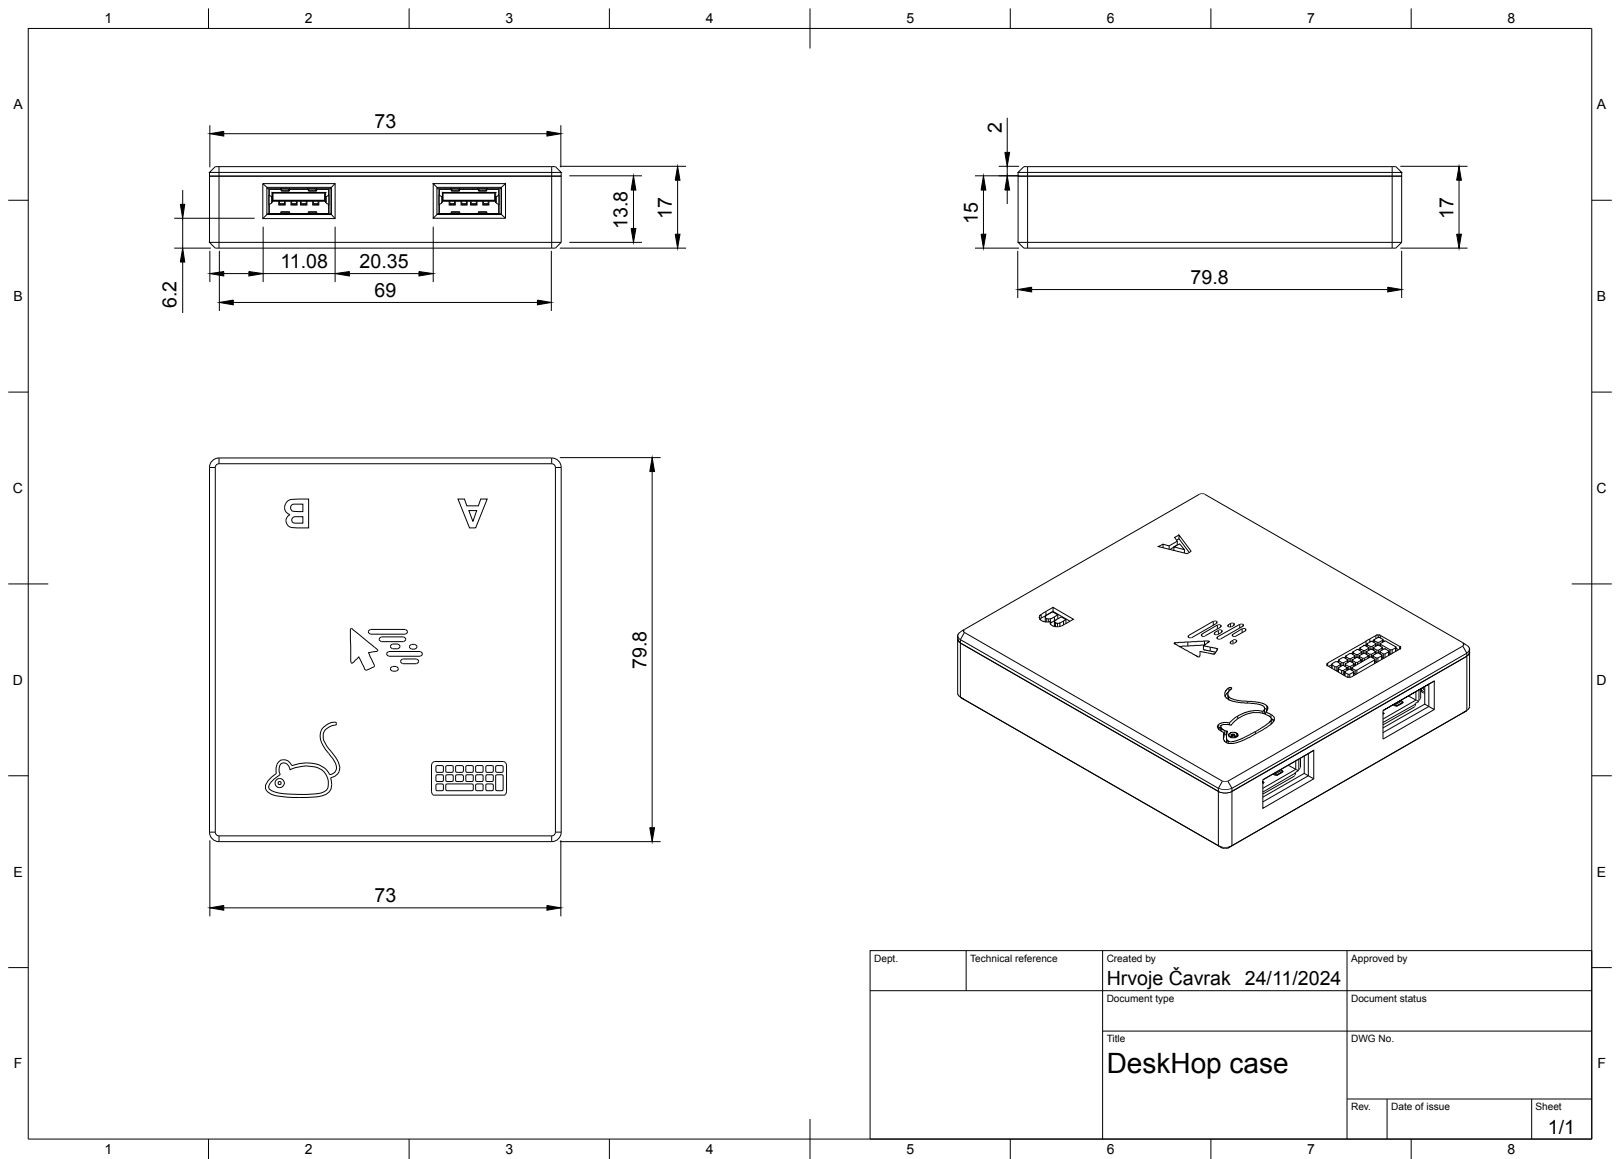
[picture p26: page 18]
Dept.; Technical reference; Created by; Approved by; Document type; Document status; Title; DWG No.; Rev.; Date of issue; Sheet; DeskHop case; Hrvoje Čavrak

DeskHop User Manual

## Documentation Release History

24 Nov 2024

- Initial release
Hrvoje Čavrak | 19

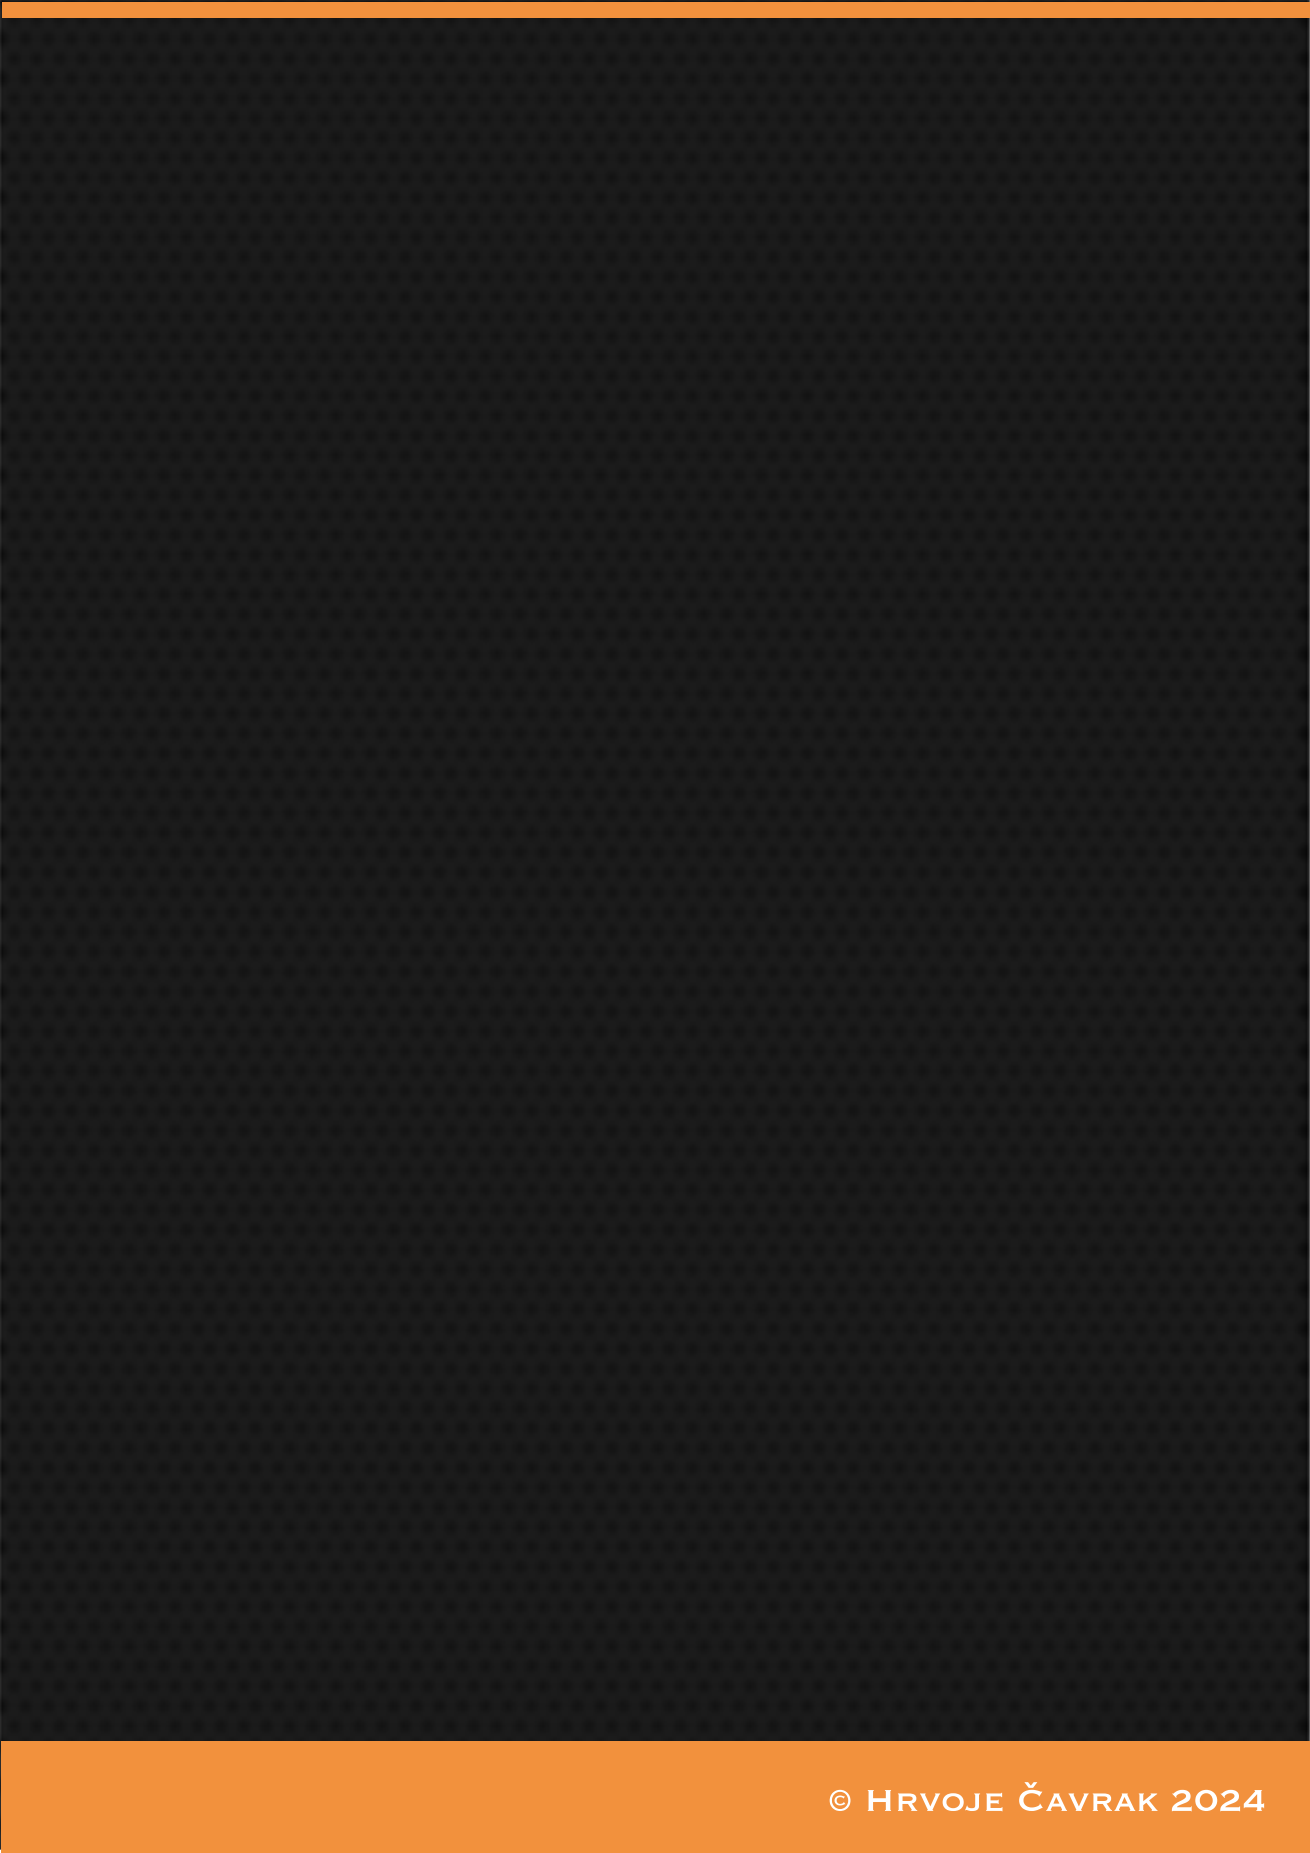
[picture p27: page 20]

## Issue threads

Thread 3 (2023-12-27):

Multiple monitors on each PC

shantur, 2023-12-27:
Hi,

Excellent idea and implementation.
As of now, does it support multiple monitors with different resolutions connected on each PC ?

Thanks

hrvach, 2023-12-27:
Resolutions should not be a problem, but I never tried it on a multi-monitor setup. I'll try and report back :)

fayfay78, 2024-01-08:
hi there, any news about multiple screens?

hrvach, 2024-01-08:
> hi there, any news about multiple screens?

I believe it should work, provided that the orientation/layout is correct, but I'm traveling and have no way to test yet.

My assumption is that if you have 2 machines with 2 FHD screens each, let's call them A and B, setting them up like:
```
-------------------------------
B left | B right | A left | A right |
-------------------------------
```
would be identical as having e.g. 3840 x 1080 screen on the left and a similar one on the right. However, there are 3 major OSes to try on, as well as mismatched resolution scenario (one "left" monitor UHD and "right" monitor FHD). Unless somebody beats me to it, I'll try to see what happens in a couple of days :)

jcassan, 2024-01-09:
Hi,
Thank you for providing such an amazing project.
I just tried what you mentionned :
---------------------------------------
| B left | B right | A left | A right |
---------------------------------------
My mouse is swapping well from B right to A left but other screens do not work.

I have a "logical barrier" at borders of the main screen on both pc. I also tried a setup with vertical stack resulting in the same behavior. If I use my trackpad to get out of the barrier and then re-use the mouse connected to the pico, cursor is being teleported to the main screen.

All screens are FHD and pcs are running windows 10.

My soldering skills are pretty bad so let me know if any bad solder could make the picos behave like this.
I also should mention the keyboard does not work on pc connected to board B but this might be a soldering issue somewhere.

hrvach, 2024-01-10:
I've tested the multiple screen scenario and it works for me with no issues [tm] (as suggested above).

I don't know what a logical barrier is in this context, please be so kind to explain (I have nothing similar configured, just a plain ubuntu with two monitor output on one side and the mouse just skips screens as expected).

if your mouse works on PC connected to A but keyboard doesn't work on board connected to B, check solder/contacts on pins 7 and 2 of the ADuM1201 chip. Also check if you soldered pin 16 on pico A (marked GP12 on solder mask) and pin 22 on pico B (marked GP17 on solder mask).

jcassan, 2024-01-10:
Sorry for not being precise on my explanation, I will try again.

From B right to A Left, everything works just fine.
When I try to move the mouse from B right to B left, the mouse is blocked at the left border of B right. I am not able to move the cursor to B left. (Same behavior for A device)

I am using two laptops for my tests. I can use my trackpad to move the mouse to my second screen (eg B right to B left). When I do so and use the mouse back, cursor is being teleported back to B right.

Anyway, I think solders are not clean enough to learn much from my tests. I will try to assemble a second unit this week end as I bought enough component to do so. I will let you know how it turns out.

hrvach, 2024-01-10:
Now I understand, sorry for being slow :) It seems Microsoft KB5003637 update to Win 10 [brok^H^H^H^H changed the HID system behavior](https://answers.microsoft.com/en-us/windows/forum/all/kb5003637-ms-usb-hid-driver-absolute-positioning/90be17fd-45f3-4de4-8e5b-cc1c465324b5). I have no idea if it's going to be reverted at some point. In theory this could be worked around with a horrible hack by having a relative mode mouse just for screen hopping, or perhaps easier - activate accessibility mode to control mouse with numpad and then patch the firmware to send a numpad right/left when you reach internal screen border.

Thank you for finding this and sharing,, I had no idea Windows behaved this way!

jcassan, 2024-01-11:
Wow, well spotted ! Let me know if you want to build a new custom firmware someday to correct this. I would be happy to test it if needed.

hrvach, 2024-01-11:
> Wow, well spotted ! Let me know if you want to build a new custom firmware someday to correct this. I would be happy to test it if needed.

I'm focusing on basic functionality first, to cover most users and most hardware. Then we tackle the edge cases, like specific OS multi-desktop handling. I think it should be doable :)

hrvach, 2024-01-13:
As of now, it works on Linux, Windows 10 might have issues after KB5003637 and so might macOS.

Added to the list of feature requests/ideas, as this requires some workarounds to support.

https://github.com/hrvach/deskhop/discussions/27

hrvach, 2024-01-18:
@Trekky12 this is a great find, thank you. There is very little actual info on this anywhere.

I have some ideas how to address that potentially, and avoiding any software would be great (because very often you can't install drivers, and for good reason).

This brings up the complexity, as you have to model multiple screens on multiple outputs, but it's doable. Definitely in the roadmap :)

Trekky12, 2024-01-19:
I totally agree with you that it's best done without needing to install any software (especially on work devices where this is often not possible).

Great to hear that this is on the roadmap 👍

forrestguest, 2024-01-23:
Would it be possible to have a mode where the mouse isn't used for hopping?  I am mostly interested in the fast switching and removing the need to restart an electrical connection with each USB device when switching desktops.  I don't really need the cursor based hopping.  Happy to open another issue if needed.

hrvach, 2024-01-23:
> Would it be possible to have a mode where the mouse isn't used for hopping? I am mostly interested in the fast switching and removing the need to restart an electrical connection with each USB device when switching desktops. I don't really need the cursor based hopping. Happy to open another issue if needed.

You can do this by hitting Right CTRL + L to "lock" the mouse to the current screen and not have it hop. Would this be something along the lines of what you're after?

forrestguest, 2024-01-24:
That may work, I meant more along the lines of suppressing the absolute positioning and just passing along the mouse inputs.  But thinking it through, you'd still have to be able to pass something through the pico, so I probably just need to be patient and wait for MS to roll back that KB

infosecconsultant, 2024-02-16:
I've got what's probably an odd setup with multiple monitors/displays.

Currently I've got | Windows-1 | MacOS-1 | Windows-2 |
And underneath MacOS-1 is | MacOS-2 |

Currently, I can't seem to 'reach' MacOS-2 (the inbuilt MacOS display) from MacOS-1 or any other display.

I use a custom mechanical keyboard and I don't actually have a Right CTRL key, I went to https://usevia.app/ to modify that, but the keyboard isn't detected (Which makes sense and I can plug it in and do that, but just thought I'd point that out as well)

Is there anything I can configure to allow this or is the solution gonna be Win1|Win2|Mac1|Mac2?

(Great project btw, and if anyone needs a spare board, I got a couple dozen made to gift to friends and I've still got spares)

infosecconsultant, 2024-02-17:
> I feel almost embarrassed how basic my two-monitor setup is compared to some of you folks! :) I'm sorry but I simply have to ask out of curiosity - can you can share a picture of your setup? :)))

Sure, I've kinda redacted a bit of stuff out of it though. The mount is custom built from aluminium extrusions for my 3x 27" monitors.

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

> work was super-busy lately and left zero energy to work on personal stuff.
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
hrvach, 2024-12-05:
I have a *highly experimental* Windows multi-monitor test, for now mouse wheel isn't supported but clicking and dragging should work. Can anyone help and test?

[deskhop-win-experiment.zip](https://github.com/user-attachments/files/18024328/deskhop-win-experiment.zip)

Instructions: Only one side should be upgraded manually (the output where windows has multiple monitors). Should be configured as OS = Windows and 1 screen only and mouse plugged directly into that board. Not ideal, but might be usable?

ak66666, 2024-12-05:
I tried this (as I understood the instructions):
Connected the side where the mouse is to a computer, left other side disconnected. Flashed this firmware to that one side only. Connected both sides to Windows computers: side A with 2 displays, side B with 3. Launched the configuration page, set side B as having 1 display.

It appears that the side to which mouse is connected to is always treated as single-display.  When mouse reaches the end of that screen, the pointer appears at the edge of the next one, but does not move farther.
When I swap mouse and keyboard - the side with the mouse works with a single monitor, and the side with keyboard - with all of them on that side computer.

Also on side A the cursor goes through the primary screen twice. I.e. I try to move cursor left to right, from side B to A, it switches to the first monitor on side A, when reaches right side of that display it jumps back to the eft side of it, and when still moved to the right, only then it goes to the second monitor's left edge, and could not be moved to the right side any further.

On the multi-monitor side the windows could be dragged between the monitors ok.

Other observations:
- mouse speed has changed, got faster.

hrvach, 2024-12-05:
Some of this behavior is still super-unfinished and needs to be patched around the code, the focus is merely on the multi-monitor and windows behavior, i.e. can you drag windows across desktops and can you use all mouse buttons ok.

This is the digitizer hybrid mode attempt which might even actually work for Windows...

jalmeroth, 2024-12-05:
This is just a minor thing (and I'm currently on a train so I can't verify this), but I noticed one thing:

```cpp
void update_mouse_position(device_t *state, mouse_values_t *values) {
	// snip…

  /* Calculate movement */
  int offset_x = accelerate(values->move_x) * (current->speed_x >> reduce_speed);
  int offset_y = accelerate(values->move_y) * (current->speed_y >> reduce_speed);

  /* Update movement */
  state->pointer_x = move_and_keep_on_screen(state->pointer_x, offset_x);
  state->pointer_y = move_and_keep_on_screen(state->pointer_y, offset_y);

	// snip…
}
```

In `update_mouse_position` we already set the new value for `state->pointer_x`.

```cpp
void check_screen_switch(const mouse_values_t *values, device_t *state) {
  int new_x        = state->pointer_x + values->move_x;
	// snip…
}
```

And then in `check_screen_switch` we add `values->move_x` to `state->pointer_x` again. Isn't `values->move_x` added twice now?

ak66666, 2024-12-05:
Forgot to mention - all mouse keys do work: left/center/right, plus I have two extra to navigate back and forward.

infosecconsultant, 2025-01-24:
I've got 5 plugged into my PC currently (using 4090gpus) and thats running 3x 4k and 2x 2k monitors. With a laptop in the middle or off to the side which I'd like to use with this. But the wide and stacked setup is definitely confusing deskhop.

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

hrvach, 2025-01-24:
> I've got 5 plugged into my PC currently (using 4090gpus) and thats running 3x 4k and 2x 2k monitors. With a laptop in the middle or off to the side which I'd like to use with this. But the wide and stacked setup is definitely confusing deskhop.

Vertical switching is something I'll probably start working on soon, if the work doesn't kill me first :) Just wanted to comment I'm impressed with your setup ... it's like you're air traffic control 👍

infosecconsultant, 2025-01-27:
Haha, thanks. Different devices for different bits of work/clients. 😅

kkourin, 2025-03-07:
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

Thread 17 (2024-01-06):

Slow mouse: Logitech G502

unxmaal, 2024-01-06:
On MacOS 14.2.1, Logitech G502. Very slow mouse.

Used https://github.com/todbot/mac-hid-dump to fetch the descriptors.

```
# note the Logitech reports 2 descriptors

046D C332: Logitech - Gaming Mouse G502
DESCRIPTOR:
  05  01  09  06  a1  01  85  01  05  07  19  e0  29  e7  15  00
  25  01  75  01  95  08  81  02  81  03  95  06  75  08  15  00
  26  a4  00  19  00  2a  a4  00  81  00  c0  05  0c  09  01  a1
  01  85  03  75  10  95  02  15  01  26  8c  02  19  01  2a  8c
  02  81  00  c0  05  01  09  80  a1  01  85  04  75  02  95  01
  15  01  25  03  09  82  09  81  09  83  81  60  75  06  81  03
  c0  06  00  ff  09  01  a1  01  85  10  75  08  95  06  15  00
  26  ff  00  09  01  81  00  09  01  91  00  c0  06  00  ff  09
  02  a1  01  85  11  75  08  95  13  15  00  26  ff  00  09  02
  81  00  09  02  91  00  c0
  (151 bytes)
046D C332: Logitech - Gaming Mouse G502
DESCRIPTOR:
  05  01  09  02  a1  01  09  01  a1  00  05  09  19  01  29  10
  15  00  25  01  95  10  75  01  81  02  05  01  16  01  80  26
  ff  7f  75  10  95  02  09  30  09  31  81  06  15  81  25  7f
  75  08  95  01  09  38  81  06  05  0c  0a  38  02  95  01  81
  06  c0  c0
  (67 bytes)
```

hrvach, 2024-01-06:
Thanks for the report! It suggests this might affect higher-end mice with 16-bit x/y. I'm going to get one of these to test properly. In the meantime, can you check if
[test_16bit.zip](https://github.com/hrvach/deskhop/files/13851548/test_16bit.zip) makes any difference and how much? Just a warning, this build is *completely* untested since I don't have anything to test on here.

hrvach, 2024-01-06:
Also, please try [test_boot.zip](https://github.com/hrvach/deskhop/files/13851565/test_boot.zip) and I'd appreciate some info if your mouse wheel scroll works. Thanks!

unxmaal, 2024-01-07:
test_16bit didn't work at all.

The Logitech mouse worked with test_boot, but it was a little laggy and slow. The mouse wheel worked fine. However, the keyboard didn't work.

If you want to push changes to a branch, I can build firmware locally.

hrvach, 2024-01-07:
Thank you for the feedback! Which keyboard model are you using? test_boot behaved the same keyboard-wise even after a hard power cycle?

It's hard to make changes in the blind, I'll try to recreate the issue when I'm back. Just out of curiosity, with the release fw that has the slow mouse symptom, does holding right alt make it even slower or has no effect? Thanks for your patience and understanding, it's not easy to make it work universally :)

chris17453, 2024-01-07:
I've done some debugging with my logitech mouse.

I could not get the SCALE by size to work at all. for example 8 or 12 or 16.

But this worked for me for my logitech MX. I just removed the switch and set it to a default.

Strangly enough, I can compile and load the project. But the kb does not work on my build. even with 0 changes in the repo.

```c
void extract_values_report_protocol(uint8_t* report,
                                    device_state_t* state,
                                    mouse_values_t* values) {
    /* If Report ID is used, the report is prefixed by the report ID so we have to move by 1 byte */
    if (state->mouse_dev.uses_report_id) {
        /* Move past the ID to parse the report */
        report++;
    }

    values->move_x = get_report_value(report, &state->mouse_dev.move_x);
    values->move_y = get_report_value(report, &state->mouse_dev.move_y);
    values->wheel = get_report_value(report, &state->mouse_dev.wheel);
    values->buttons = get_report_value(report, &state->mouse_dev.buttons);
    values->move_x <<= 4;
    values->move_y <<= 6;
}
```

hrvach, 2024-01-07:
> Debugged Logitech mouse issues.

Thanks for the help, it's awesome to see someone else poking around this!

> I am able to compile, load project, but keyboard fails work on build, despite no repo changes. Temporary fix: keep Board A with default image, modify Board B accordingly.

This is something totally unexpected I yet have to figure out when I get back from my trip. What versions are you using for gcc, pico-sdk? What is the exact keyboard model?

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

This is a very useful piece of information, thanks! So, your mouse being slow issue goes away if you shift LEFT by 4? That would mean it was likely flipped to HID report mode OK. When my Logitech mouse arrives I will knew more, but I assumed a 16 bit mouse would basically output a Q8.8 number, and 12-bit mouse Q8.4 ... maybe my assumption was wrong or some other step is missing.

Please share your mouse model and hid descriptor if possible.

> I'm trying to figure out how to get debugging to work, but one thing I noticed with the scale loop in this function, is it scales to the X size. The Y size might be different, it should have seperate scale switch's If thats the case.

You are right, the most proper thing would be to treat these independently, but I will be really surprised if there exists a mouse that has different resolutions for X and Y.

chris17453, 2024-01-08:
Bus 003 Device 011: ID 046d:c52b Logitech, Inc. Unifying Receiver
Bus 003 Device 013: ID 3434:0160 Keychron Keychron Q6

HID DESCRIPTORS for Logitech Unifying Receiver
003:011:002:DESCRIPTOR         1704713201.483199
 06 00 FF 09 01 A1 01 85 10 75 08 95 06 15 00 26
 FF 00 09 01 81 00 09 01 91 00 C0 06 00 FF 09 02
 A1 01 85 11 75 08 95 13 15 00 26 FF 00 09 02 81
 00 09 02 91 00 C0 06 00 FF 09 04 A1 01 85 20 75
 08 95 0E 15 00 26 FF 00 09 41 81 00 09 41 91 00
 85 21 95 1F 15 00 26 FF 00 09 42 81 00 09 42 91
 00 C0

003:011:001:DESCRIPTOR         1704713201.487198
 05 01 09 02 A1 01 85 02 09 01 A1 00 05 09 19 01
 29 10 15 00 25 01 95 10 75 01 81 02 05 01 16 01
 F8 26 FF 07 75 0C 95 02 09 30 09 31 81 06 15 81
 25 7F 75 08 95 01 09 38 81 06 05 0C 0A 38 02 95
 01 81 06 C0 C0 05 0C 09 01 A1 01 85 03 75 10 95
 02 15 01 26 FF 02 19 01 2A FF 02 81 00 C0 05 01
 09 80 A1 01 85 04 75 02 95 01 15 01 25 03 09 82
 09 81 09 83 81 60 75 06 81 03 C0 06 BC FF 09 88
 A1 01 85 08 19 01 29 FF 15 01 26 FF 00 75 08 95
 01 81 00 C0

003:011:000:DESCRIPTOR         1704713201.490202
 05 01 09 06 A1 01 05 07 19 E0 29 E7 15 00 25 01
 75 01 95 08 81 02 81 03 95 05 05 08 19 01 29 05
 91 02 95 01 75 03 91 01 95 06 75 08 15 00 26 A4
 00 05 07 19 00 2A A4 00 81 00 C0

HID DESCRIPTORS for KeyChron
003:013:002:DESCRIPTOR         1704713201.492201
 05 01 09 02 A1 01 85 02 09 01 A1 00 05 09 19 01
 29 08 15 00 25 01 95 08 75 01 81 02 05 01 09 30
 09 31 15 81 25 7F 95 02 75 08 81 06 09 38 15 81
 25 7F 95 01 75 08 81 06 05 0C 0A 38 02 15 81 25
 7F 95 01 75 08 81 06 C0 C0 05 01 09 80 A1 01 85
 03 19 01 2A B7 00 15 01 26 B7 00 95 01 75 10 81
 00 C0 05 0C 09 01 A1 01 85 04 19 01 2A A0 02 15
 01 26 A0 02 95 01 75 10 81 00 C0 05 01 09 06 A1
 01 85 06 05 07 19 E0 29 E7 15 00 25 01 95 08 75
 01 81 02 05 07 19 00 29 EF 15 00 25 01 95 F0 75
 01 81 02 05 08 19 01 29 05 95 05 75 01 91 02 95
 01 75 03 91 01 C0

003:013:001:DESCRIPTOR         1704713201.495197
 06 60 FF 09 61 A1 01 09 62 15 00 26 FF 00 95 20
 75 08 81 02 09 63 15 00 26 FF 00 95 20 75 08 91
 02 C0

003:013:000:DESCRIPTOR         1704713201.498204
 05 01 09 06 A1 01 05 07 19 E0 29 E7 15 00 25 01
 95 08 75 01 81 02 95 01 75 08 81 01 05 07 19 00
 29 FF 15 00 26 FF 00 95 06 75 08 81 00 05 08 19
 01 29 05 95 05 75 01 91 02 95 01 75 03 91 01 C0

Software Versions
```
annobin-plugin-gcc-12.28-1
arm-image-installer-3.8-1
arm-none-eabi-binutils-cs-2.41-1
arm-none-eabi-gcc-cs-13.2.0-1
arm-none-eabi-gcc-cs-c++-13.2.0-1
arm-none-eabi-newlib-4.1.0-6
gcc-12.3.1-1
gcc-gdb-plugin-12.3.1-1
gcc-plugin-annobin-12.3.1-1
gcc-c++-12.3.1-1
```

BUILD OUTPUT
```
[root@nd-box-watkinslabs-com deskhop]# make build
PICO_SDK_PATH is /home/nd/repos/github/pico-sdk
PICO platform is rp2040.
-- The C compiler identification is GNU 13.2.0
-- The CXX compiler identification is GNU 13.2.0
-- The ASM compiler identification is GNU
-- Found assembler: /usr/bin/arm-none-eabi-gcc
-- Detecting C compiler ABI info
-- Detecting C compiler ABI info - done
-- Check for working C compiler: /usr/bin/arm-none-eabi-gcc - skipped
-- Detecting C compile features
-- Detecting C compile features - done
-- Detecting CXX compiler ABI info
-- Detecting CXX compiler ABI info - done
-- Check for working CXX compiler: /usr/bin/arm-none-eabi-g++ - skipped
-- Detecting CXX compile features
-- Detecting CXX compile features - done
Build type is Debug
Using regular optimized debug build (set PICO_DEOPTIMIZED_DEBUG=1 to de-optimize)
PICO target board is pico.
Using board configuration from /home/nd/repos/github/pico-sdk/src/boards/include/boards/pico.h
TinyUSB available at /home/nd/repos/github/pico-sdk/lib/tinyusb/src/portable/raspberrypi/rp2040; enabling build support for USB.
Compiling TinyUSB with CFG_TUSB_DEBUG=1
BTstack available at /home/nd/repos/github/pico-sdk/lib/btstack
cyw43-driver available at /home/nd/repos/github/pico-sdk/lib/cyw43-driver
Pico W Bluetooth build support available.
lwIP available at /home/nd/repos/github/pico-sdk/lib/lwip
mbedtls available at /home/nd/repos/github/pico-sdk/lib/mbedtls
-- Configuring done (0.8s)
-- Generating done (0.0s)
-- Build files have been written to: /home/nd/repos/github/deskhop/build
[9/209] Performing configure step for 'PioasmBuild'
loading initial cache file /home/nd/repos/github/deskhop/build/pico-sdk/src/rp2_common/pico_cyw43_driver/pioasm/tmp/PioasmBuild-cache-Debug.cmake
CMake Deprecation Warning at CMakeLists.txt:1 (cmake_minimum_required):
  Compatibility with CMake < 3.5 will be removed from a future version of
  CMake.

  Update the VERSION argument <min> value or use a ...<max> suffix to tell
  CMake that the project does not need compatibility with older versions.
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
hrvach, 2024-01-10:
@chris17453 great idea to use the python code to get the mouse position, very cool!

These reports above seem Logitech-specific somehow, it's in vendor-defined page ff00, ones that start with 20 should be report id 32:

Collection (Application),
    Report ID (32),
    Report Size (8),
    Report Count (14),
    Logical Minimum (0),
    Logical Maximum (255),
    Usage (41h),
    Input,

... which matches the output - report id (20 hex) and 14 x 1 byte after, but I have no idea what's it supposed to be, need to check some Logitech drivers.

For mouse, I'd expect report ID 2, then 2 bytes for the buttons, 3 for the coords and 2 for wheel/pan.

Perhaps try usbhid-dump --entity=all --address  your:addr and aim for the one that has report ID 2 in the descriptor?

hrvach, 2024-01-11:
Finally got my hand on a Logitech mouse, can anyone please try [test_highres.zip](https://github.com/hrvach/deskhop/files/13905647/test_highres.zip)? I've also upped the polling rate for these modern mice.

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

chris17453, 2024-01-11:
I tried it.

On Computer A:
- A orange Pi 5 - Armbian
- The x and y are much faster, but still seem a bit slow
- x and y movement are smooth in their operation
- keyboard works

On Computer B:
- Threadrippper - Fedora 37
- X is much faster, y is significantly slower than it needs to be, possibly still @ 1x
- Keyboard works

hrvach, 2024-01-17:
Slow mouse issue should be fixed by now, individual speeds can be tweaked per users preference.

Closed 2024-01-17.

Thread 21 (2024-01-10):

Development/debug tips

mparrett, 2024-01-10:
Hello,

Thank you for sharing your project! I'm building a deskhop this week and I'm curious to see if it solves some of the pain I've been putting up with for years.

I'd love to support and have a handful of Logitech and other devices I can test with. Do you have any suggestions for development setup? Specifically any guidance around debugging would be greatly appreciated! So far I'm able to build and flash the devices but end up with flashing LEDs. I'm guessing this is due to some MacOS idiosyncrasy or the fact that it's all roughly cobbled together on a breadboard until Friday when the PCB arrives, but I am eager to debug. I have a FTDI device, and other pis I could use as serial debuggers... but somewhat uncharted territory at the moment.

Thanks again!

hrvach, 2024-01-10:
Try checking if you pico-sdk has a recent tinyusb in the lib folder.

For debugging, SWD works great (you can use another pico as ["picoprobe"](https://github.com/raspberrypi/picoprobe/releases/tag/picoprobe-cmsis-v1.0.3) and that works great!)

USB stdio is tricky when you already have tinyusb doing a device, but you can add a CDC with #define CFG_TUD_CDC 1 in tusb_config.h, you'd need to add a descriptor, something like:
```
    TUD_CDC_DESCRIPTOR(ITF_NUM_CDC,
                       STRID_CDC_INTERFACE,
                       EPNUM_CDC_NOTIF,
                       8,
                       EPNUM_CDC_OUT,
                       EPNUM_CDC_IN,
                       CFG_TUD_CDC_EP_BUFSIZE),
```
... check some of the CDC examples for tinyusb, then you can tud_cdc_n_write() to output strings and use a serial device created to receive them... of course, uart1 is available if that's the preferred route (and it's way easier than CDC).

Do binaries in the "release" section work on your breadboard? Don't worry, I'll try to help and we'll get it working for you somehow :)

mparrett, 2024-01-13:
Thanks for the quick and helpful response. I'll have some time this weekend to hopefully make progress.

> Do binaries in the "release" section work on your breadboard?

I can load the binaries and device A LED is illuminated. Device B LED is not illuminated.
When I flash with a .uf2 that I built myself, I get a flashing LED.

mparrett, 2024-01-13:
Update: Investigating a possible root cause with `gcc-arm-embedded` vs `gcc-arm-none-eabi` (had issues with the latter on macos initially and followed some instructions to use the -embedded package. But I see now that could be causing issues with my builds.

mparrett, 2024-01-13:
Progress - solid LEDs after flashing with my own build! Uninstalled all *eabi* packages in homebrew, and reinstalled arm toolchain with `brew install --cask gcc-arm-embedded`

hrvach, 2024-01-13:
Yep, for mac os it seems you need to take the gcc-arm-embedded route, also you need to git pull latest tinyusb in pico-sdk/lib/tinyusb). Fingers crossed! :)

mparrett, 2024-01-14:
I appear to have a viable debug setup using a pi zero! For a "hello world" program I'm able to connect to gdb and also read stdio using minicom. Next I'll see if I can do the same with Deskhop!

mparrett, 2024-01-15:
Happy to report I've got a foothold on debugging. Thanks for the help! Relevant snippets below:

Relevant snippets:

**build.sh**
```
cmake -DCMAKE_BUILD_TYPE=Debug
```

**CMakeLists.txt**
```
# debug setup: enable stdio via uart on board A
pico_enable_stdio_uart(board_A 1)
```

**main.h**
```
#define SERIAL_DEBUG_TX_PIN 4 // GPIO 4 -> pin 6
#define SERIAL_DEBUG_RX_PIN 5 // GPIO 5 -> pin 8
```

**setup.c**
```
stdio_uart_init_full(uart1, 115200, SERIAL_DEBUG_TX_PIN, SERIAL_DEBUG_RX_PIN);
printf("hello from pico\n");
```

jalmeroth, 2024-04-06:
Hi there :wave: ,

I tried to follow along your discussion. I see the CDC part has been somewhat implemented and is hidden behind an ifdef. I tried to set `#define DH_DEBUG 1` in `user_config.h`. Unfortunately, I can't build it with the latest version as it looks to me like e.g. this [whole block](https://github.com/hrvach/deskhop/blob/8df007ac135ef2f6b0c47d135d2fb8316a0d1c47/src/tusb_config.h#L90-L104) is ignored.

Errors I get:
```
[ 32%] Building C object CMakeFiles/board_A.dir/src/usb_descriptors.c.obj
In file included from /home/jan/workspace/deskhop/pico-sdk/lib/tinyusb/src/tusb.h:75,
                 from /home/jan/workspace/deskhop/src/main.h:29,
                 from /home/jan/workspace/deskhop/src/usb_descriptors.c:27:
/home/jan/workspace/deskhop/pico-sdk/lib/tinyusb/src/device/usbd.h:214:67: error: 'CDC_COMM_SUBCLASS_ABSTRACT_CONTROL_MODEL' undeclared here (not in a function)
  214 |   8, TUSB_DESC_INTERFACE_ASSOCIATION, _itfnum, 2, TUSB_CLASS_CDC, CDC_COMM_SUBCLASS_ABSTRACT_CONTROL_MODEL, CDC_COMM_PROTOCOL_NONE, 0,\
      |                                                                   ^~~~~~~~~~~~~~~~~~~~~~~~~~~~~~~~~~~~~~~~
/home/jan/workspace/deskhop/src/usb_descriptors.c:209:5: note: in expansion of macro 'TUD_CDC_DESCRIPTOR'
  209 |     TUD_CDC_DESCRIPTOR(
      |     ^~~~~~~~~~~~~~~~~~
/home/jan/workspace/deskhop/pico-sdk/lib/tinyusb/src/device/usbd.h:214:109: error: 'CDC_COMM_PROTOCOL_NONE' undeclared here (not in a function); did you mean 'HID_ITF_PROTOCOL_NONE'?
  214 |   8, TUSB_DESC_INTERFACE_ASSOCIATION, _itfnum, 2, TUSB_CLASS_CDC, CDC_COMM_SUBCLASS_ABSTRACT_CONTROL_MODEL, CDC_COMM_PROTOCOL_NONE, 0,\
      |                                                                                                             ^~~~~~~~~~~~~~~~~~~~~~
/home/jan/workspace/deskhop/src/usb_descriptors.c:209:5: note: in expansion of macro 'TUD_CDC_DESCRIPTOR'
  209 |     TUD_CDC_DESCRIPTOR(
      |     ^~~~~~~~~~~~~~~~~~
/home/jan/workspace/deskhop/pico-sdk/lib/tinyusb/src/device/usbd.h:218:30: error: 'CDC_FUNC_DESC_HEADER' undeclared here (not in a function)
  218 |   5, TUSB_DESC_CS_INTERFACE, CDC_FUNC_DESC_HEADER, U16_TO_U8S_LE(0x0120),\
      |                              ^~~~~~~~~~~~~~~~~~~~
/home/jan/workspace/deskhop/src/usb_descriptors.c:209:5: note: in expansion of macro 'TUD_CDC_DESCRIPTOR'
  209 |     TUD_CDC_DESCRIPTOR(
      |     ^~~~~~~~~~~~~~~~~~
/home/jan/workspace/deskhop/pico-sdk/lib/tinyusb/src/device/usbd.h:220:30: error: 'CDC_FUNC_DESC_CALL_MANAGEMENT' undeclared here (not in a function)
  220 |   5, TUSB_DESC_CS_INTERFACE, CDC_FUNC_DESC_CALL_MANAGEMENT, 0, (uint8_t)((_itfnum) + 1),\
      |                              ^~~~~~~~~~~~~~~~~~~~~~~~~~~~~
/home/jan/workspace/deskhop/src/usb_descriptors.c:209:5: note: in expansion of macro 'TUD_CDC_DESCRIPTOR'
  209 |     TUD_CDC_DESCRIPTOR(
      |     ^~~~~~~~~~~~~~~~~~
/home/jan/workspace/deskhop/pico-sdk/lib/tinyusb/src/device/usbd.h:222:30: error: 'CDC_FUNC_DESC_ABSTRACT_CONTROL_MANAGEMENT' undeclared here (not in a function)
  222 |   4, TUSB_DESC_CS_INTERFACE, CDC_FUNC_DESC_ABSTRACT_CONTROL_MANAGEMENT, 2,\
      |                              ^~~~~~~~~~~~~~~~~~~~~~~~~~~~~~~~~~~~~~~~~
/home/jan/workspace/deskhop/src/usb_descriptors.c:209:5: note: in expansion of macro 'TUD_CDC_DESCRIPTOR'
  209 |     TUD_CDC_DESCRIPTOR(
      |     ^~~~~~~~~~~~~~~~~~
/home/jan/workspace/deskhop/pico-sdk/lib/tinyusb/src/device/usbd.h:224:30: error: 'CDC_FUNC_DESC_UNION' undeclared here (not in a function)
  224 |   5, TUSB_DESC_CS_INTERFACE, CDC_FUNC_DESC_UNION, _itfnum, (uint8_t)((_itfnum) + 1),\
      |                              ^~~~~~~~~~~~~~~~~~~
/home/jan/workspace/deskhop/src/usb_descriptors.c:209:5: note: in expansion of macro 'TUD_CDC_DESCRIPTOR'
  209 |     TUD_CDC_DESCRIPTOR(
      |     ^~~~~~~~~~~~~~~~~~
In file included from /home/jan/workspace/deskhop/pico-sdk/lib/tinyusb/src/tusb.h:37:
/home/jan/workspace/deskhop/src/usb_descriptors.c:210:84: error: 'CFG_TUD_CDC_EP_BUFSIZE' undeclared here (not in a function); did you mean 'CFG_TUD_HID_EP_BUFSIZE'?
  210 |         ITF_NUM_CDC, STRID_DEBUG, EPNUM_CDC_NOTIF, 8, EPNUM_CDC_OUT, EPNUM_CDC_IN, CFG_TUD_CDC_EP_BUFSIZE),
      |                                                                                    ^~~~~~~~~~~~~~~~~~~~~~
/home/jan/workspace/deskhop/pico-sdk/lib/tinyusb/src/common/tusb_common.h:43:44: note: in definition of macro 'TU_U16_LOW'
   43 | #define TU_U16_LOW(_u16)      ((uint8_t) ((_u16)       & 0x00ff))
      |                                            ^~~~
/home/jan/workspace/deskhop/pico-sdk/lib/tinyusb/src/device/usbd.h:230:50: note: in expansion of macro 'U16_TO_U8S_LE'
  230 |   7, TUSB_DESC_ENDPOINT, _epout, TUSB_XFER_BULK, U16_TO_U8S_LE(_epsize), 0,\
      |                                                  ^~~~~~~~~~~~~
/home/jan/workspace/deskhop/src/usb_descriptors.c:209:5: note: in expansion of macro 'TUD_CDC_DESCRIPTOR'
  209 |     TUD_CDC_DESCRIPTOR(
      |     ^~~~~~~~~~~~~~~~~~
make[2]: *** [CMakeFiles/board_A.dir/build.make:76: CMakeFiles/board_A.dir/src/usb_descriptors.c.obj] Error 1
make[1]: *** [CMakeFiles/Makefile2:1588: CMakeFiles/board_A.dir/all] Error 2
make: *** [Makefile:91: all] Error 2
```

Am I holding it wrong? :upside_down_face:

What can I expect to see on the serial device? I would be interested to see the output of PIO-USB like in https://github.com/sekigon-gonnoc/Pico-PIO-USB/tree/main/examples/capture_hid_report Would that be feasible?

jalmeroth, 2024-11-19:
Can this be closed in favour of the [wiki](https://github.com/hrvach/deskhop/wiki/Build---Debug-hints)?

Closed 2024-11-19.

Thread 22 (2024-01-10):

Different screen dimensions and mouse switching

raldnor, 2024-01-10:
Wow, what a great project this is!

I have tried to use the deskhop on one system with three monitors attached where the monitor in the middle has different dimensions than the outer two, and the other system is a laptop with its own screen. This seems not to work so well. I don't know if it's a soldering mistake, windows (laptop) vs Linux (three monitor system) or the discrepancy between the monitor resolutions, but on the three monitor system the mouse does not move at all, and on the laptop (when switched to 'B') the mouse can only move horizontally at the top of the screen.

Would it be possible to change the firmware in such a way that the mouse just switches as is between two systems? I realise that the seamless experience won't work as well, but the ability to change  between the two methods might give more flexibility in complex scenarios.

Please keep up the good work :)

hrvach, 2024-01-10:
It might be actually due to the mouse sending something device can't parse properly or not moving to the report mode despite being told to. Which mouse? Can you try this firmware
[test_fw.zip](https://github.com/hrvach/deskhop/files/13894137/test_fw.zip)
 and let me know? Cheers!

raldnor, 2024-01-10:
That's a fast response! Thanks!

Your firmware seems to have fixed the not working y-movement on the laptop screen.

When I try to move the mouse cursor off-screen (to the right edge of the laptop) I expect the deskhop to switch and that the mouse appears on the 3-monitor system, but both events do not happen.

3-monitor system = A
Laptop = B

Mouse works only on B, the open edge on B seems to be on the right side of the monitor.
When moving beyond the right edge of B (on the laptop) the led of the B-pico turns off, but the led of the A-pico does not turn on. Only when using caps-lock the led of A turns on and then the keyboard works, but not the mouse.

Hope this makes sense.

raldnor, 2024-01-10:
Oh, the mouse is a Microsoft Compact Optical Mouse 500, a very tiny wired laptop mouse. I also tried a Logitech wireless MX master mouse and that results in the same behavior.

raldnor, 2024-01-10:
You're very welcome, I love what you made and it was to be expected that MS would once again be the culprit. Somehow it seems to be part of their business model to break beautiful working things /rant mode off.
Would it be possible to create a key combination to switch between  absolute and relative mouse mode?

hrvach, 2024-01-10:
> You're very welcome, I love what you made and it was to be expected that MS would once again be the culprit. Somehow it seems to be part of their business model to break beautiful working things /rant mode off. Would it be possible to create a key combination to switch between absolute and relative mouse mode?

@raldnor  I'm sorry, I have pasted my reply in the wrong thread because I'm a dumbass. Your issue seems different, and would suggest your devices are not communicating. You are aiming for "keep pressing caps lock to toggle between leds" behavior.

Check:

1. ADuM1201 chip has +3.3V on pin8 with respect to pin 5 and has +3.3V on pin 1 with respect to pin 4
2. -||- pin 5 is connected to Pico A GND, pin 4 is connected to Pico B GND
3. -||- Pin 7 is connected to pico A pin 16 and that's soldered down, pin 2 is connected to pico B pin 22, same thing
4. -||- Pin 6 is connected to Pico A pin 17, same thing, pin 3 is connected to pico B pin 21, same thing

Let me know how your debugging goes.

raldnor, 2024-01-10:
Ehrm, I don't follow :). The caps lock key works like a charm and the keyboard is switching. Also the leds switch between A and B when using the caps lock key.

hrvach, 2024-01-10:
> Mouse works only on B, the open edge on B seems to be on the right side of the monitor. When moving beyond the right edge of B (on the laptop) the led of the B-pico turns off, but the led of the A-pico does not turn on. Only when using caps-lock the led of A turns on and then the keyboard works, but not the mouse.

I was basing my recommendation on this but wrongly assumed your caps lock only turns off A and not B, thanks for clarifying!

So, my diagnosis would be - UART B->A not working correctly, based on: mouse only works on B, moving it away from screen turns off led B but doesn't light up led A, and keyboard can work on both.

That reduces the number of things to check to:

1. ADuM1201  pin 3 connected to pico B pin 21 (GPIO 16)
2. ADuM1201  pin 6 connected to pico A pin 17 (GPIO 13)

When it starts working correctly, moving the mouse will turn on the other LED too!

raldnor, 2024-01-11:
You were right! Re-soldering the 8-pin chip did the trick. It works like a charm now, thanks a lot!

Closed 2024-01-11.

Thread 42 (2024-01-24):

deskhop - active usb hub not working

GiT-BeDa, 2024-01-24:
First off all. Thanks for your great work! I followed your project for the last month. Because of your great documentary i got my deskhop board assembled and it is a pleasure to watch the software evolve.

My setup is a cherry G80-3000N RGB keyboard (0.79W) and a Corsair M65 RGB Ultra Gaming mouse (~0.54W). If i connect these periperals to my deskhop board it seems not one of these work out of the box. So i got the idea in my mind that the problem is the power consumption of these devices, i ordered a active powered USB-Hub (CSL - USB 3.0 Hub Aktiv - 10 GBit/s from Primewire) and connect my mouse and keyboard via these powered HUB but none of my periperals even light up nor do anything.

If i try it with a standard keyboard and mouse direct connected to Board A and B it works like charme. If i try to connect these working keyboard and mouse via the HUB it stops working. If i connect the HUB directly to the PC everything works. Is there a way to debug or solve these behavior for me? Do you have any suggestions, what i can do to make it work?

I have seen that it is possible to switch beetween desktops using a configurable key, are there any plans to make it possible to switch via lets say middle mouse double click? I would love to only switch beetween outputs on keypress or double middle mouse click, because of fullscreen applications and games.

hrvach, 2024-01-24:
Perhaps the easy way to test is to try connecting board A to a PC and wait for the LED to come on, then plug in the keyboard and check if the LED goes down (along with the port) and if your USB device disappears from your PC.

Hubs are tricky to support and I have just one that works; I have to get 2-3 more that have issues and try to debug.

Try checking what kind of power requirements your peripherals seem to report (Linux, Google around for other OS-es):

bash# lsusb -v | grep -E "^Bus|[0-9]+mA"

GiT-BeDa, 2024-01-24:
It seems all devices reporting 500mA:
> DeskHop direct connected: Bus 002 Device 004: ID 2e8a:107c Hrvoje Cavrak DeskHop Switch MaxPower 500mA
> Keyboard  direct connected: Bus 002 Device 003: ID 046a:00de Cherry GmbH G80-3000N FL RGB Keyboard MaxPower 500mA
> Mouse  direct connected: Bus 001 Device 002: ID 1b1c:1b9e Corsair CORSAIR M65 RGB ULTRA Gaming Mouse MaxPower 500mA

Ok, i tested a little bit around and removed the HUB from the setup:

I connected only board A to my PC. If i connect the keyboard it lights up and it works. I can turn off the LED via Caps, then i remove the keyboard and connect the mouse to board A. It also works and the LED on the pico turns off if i reach the left side of my screen.

Then i connect my second PC with board B, the keyboard on A works as it should. I can switch beetween the computers via Caps and use it as soon i connect my mouse with board B, the mouse doesn't light up and at the moment i try to swap to board B with Caps it seems like the pico B reboots (the LED on the pico B turns on at Caps an switches back to A).

Then i swaped mouse and keyboard (2 PC connected, mouse at A, keyboard at B) now the mouse works and i can switch with the mouse. The keyboard does not light up, as soon i switch to the other pc the pico B seems to reboot.

Is it possible that board B has a problem to provide enough power? As i said with a standard keyboard and mouse it works flawlessly.

It would a pleasure for me to spend a problematic HUB to you, to give a little bit support back to your project. If you would provide a address to me.

GiT-BeDa, 2024-11-14:
Again, thank you for your great work! I have successfully built a v2 board (with the capacitor in place), and it works like a charm!

Closed 2024-11-14.

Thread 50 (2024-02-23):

Dry Studio Black Diamond 75 keyboard not working

infosecconsultant, 2024-02-23:
I thought I'd try with a few other keyboard I have. Unfortunately the Dry Studio Black Diamond 75 keyboard does not register with the deskhop at all.
I'm _guessing_ it's got issues with the power draw but I'm not sure. I don't currently have a way to measure that but I've ordered a little inline USB power monitor/tester.
I turned off the LEDs etc but still no luck.
If there's any advice on debugging please let me know and I'll give it a shot.

hrvach, 2024-02-23:
Try dumping the usb hid report first, maybe it's also detected as a mouse ... I had to google this keyboard out of curiosity and must admit I have never seen anything like this :) it's pretty interesting...

infosecconsultant, 2024-02-26:
I'll try to do that when I'm back tomorrow.
This output?

```lsusb -v
usbhid-dump
```

The keyboard supports Bluetooth... Is there any chance the raspi could pair a bluetooth keyboard? Or have a bluetooth dongle attached to it?

hrvach, 2024-02-27:
Unless a BT dongle presents as a usb keyboard, I doubt that would work, but I was working on pico W BT support, mostly in the other direction (use BT as client so you need only one pico).

Trying to do support for non-boot keyboards as well, that should sort out most issues with a few stubborn keyboard models.

hrvach, 2024-04-01:
Any change with the latest fw?

infosecconsultant, 2024-04-02:
Hey hrvach, I've got some other firmware issues with that keyboard unfortunately. I'll have to try again once the RMA'd unit comes though in a couple of weeks. Sorry :(

infosecconsultant, 2024-04-19:
Hey @hrvach

Still no luck with the keyboard. Not registering any keypresses at all and I've updated to the most recent release of firmware.

The following output is from a linux machine plugged into the 'A' port of the deskhop.

usbdhid-dump

```
001:005:001:DESCRIPTOR         1713489329.878272
 05 01 09 02 A1 01 85 01 09 01 A1 00 05 09 19 01
 29 05 15 00 25 01 95 05 75 01 81 02 95 01 75 03
 81 01 05 01 09 30 09 31 15 81 25 7F 95 02 75 08
 81 06 09 38 15 81 25 7F 95 01 75 08 81 06 05 0C
 0A 38 02 15 81 25 7F 95 01 75 08 81 06 C0 C0

001:005:000:DESCRIPTOR         1713489329.879163
 05 01 09 06 A1 01 85 01 05 07 19 E0 29 E7 15 00
 25 01 95 08 75 01 81 02 95 01 75 08 81 01 05 08
 19 01 29 05 95 05 75 01 91 02 95 01 75 03 91 01
 05 07 19 00 2A FF 00 15 00 26 FF 00 95 06 75 08
 81 00 C0 05 01 09 02 A1 01 85 02 09 01 A1 00 05
 09 19 01 29 05 15 00 25 01 95 05 75 01 81 02 95
 01 75 03 81 01 05 01 09 30 09 31 15 00 26 FF 7F
 75 10 95 02 81 02 09 38 15 81 25 7F 95 01 75 08
 81 06 95 01 75 08 81 01 C0 C0
```

And lsusb -v output

```

Bus 001 Device 005: ID 2e8a:107c Hrvoje Cavrak DeskHop Switch
Device Descriptor:
  bLength                18
  bDescriptorType         1
  bcdUSB               2.00
  bDeviceClass            0 [unknown]
  bDeviceSubClass         0 [unknown]
  bDeviceProtocol         0
  bMaxPacketSize0        64
  idVendor           0x2e8a Hrvoje Cavrak
  idProduct          0x107c DeskHop Switch
  bcdDevice            1.00
  iManufacturer           1 Hrvoje Cavrak
  iProduct                2 DeskHop Switch
  iSerial                 3 0
  bNumConfigurations      1
  Configuration Descriptor:
    bLength                 9
    bDescriptorType         2
    wTotalLength       0x003b
    bNumInterfaces          2
    bConfigurationValue     1
    iConfiguration          0
    bmAttributes         0xa0
      (Bus Powered)
      Remote Wakeup
    MaxPower              500mA
    Interface Descriptor:
      bLength                 9
      bDescriptorType         4
      bInterfaceNumber        0
      bAlternateSetting       0
      bNumEndpoints           1
      bInterfaceClass         3 Human Interface Device
      bInterfaceSubClass      0 [unknown]
      bInterfaceProtocol      0
      iInterface              2 DeskHop Switch
        HID Device Descriptor:
          bLength                 9
          bDescriptorType        33
          bcdHID               1.11
          bCountryCode            0 Not supported
          bNumDescriptors         1
          bDescriptorType        34 Report
          wDescriptorLength     138
          Report Descriptors:
            ** UNAVAILABLE **
      Endpoint Descriptor:
        bLength                 7
        bDescriptorType         5
        bEndpointAddress     0x81  EP 1 IN
        bmAttributes            3
          Transfer Type            Interrupt
          Synch Type               None
          Usage Type               Data
        wMaxPacketSize     0x0020  1x 32 bytes
        bInterval               1
    Interface Descriptor:
      bLength                 9
      bDescriptorType         4
      bInterfaceNumber        1
      bAlternateSetting       0
      bNumEndpoints           1
      bInterfaceClass         3 Human Interface Device
      bInterfaceSubClass      0 [unknown]
      bInterfaceProtocol      0
      iInterface              4 MouseHelper
        HID Device Descriptor:
          bLength                 9
          bDescriptorType        33
          bcdHID               1.11
          bCountryCode            0 Not supported
          bNumDescriptors         1
          bDescriptorType        34 Report
          wDescriptorLength      79
          Report Descriptors:
            ** UNAVAILABLE **
      Endpoint Descriptor:
        bLength                 7
        bDescriptorType         5
        bEndpointAddress     0x82  EP 2 IN
        bmAttributes            3
          Transfer Type            Interrupt
          Synch Type               None
          Usage Type               Data
        wMaxPacketSize     0x0020  1x 32 bytes
        bInterval               1
Device Status:     0x0000
  (Bus Powered)
```

The following output is from a linux machine plugged into the black diamond keyboard directly:
usbdhid-dump
```
001:007:002:DESCRIPTOR         1713489935.694410
 06 00 FF 09 01 A1 01 09 01 15 00 26 FF 00 75 08
 95 40 81 02 09 02 15 00 26 FF 00 75 08 95 40 91
 02 C0

001:007:001:DESCRIPTOR         1713489935.695966
 05 0C 09 01 A1 01 85 02 15 00 25 01 75 01 95 01
 09 CD 81 06 09 E2 81 06 09 B5 81 06 09 B6 81 06
 09 E9 81 06 09 EA 81 06 09 6F 81 06 09 70 81 06
 C0 05 01 09 80 A1 01 85 03 19 81 29 B8 15 00 25
 01 75 01 95 38 81 02 C0

001:007:000:DESCRIPTOR         1713489935.696796
 05 01 09 06 A1 01 05 07 19 E0 29 E7 15 00 25 01
 75 01 95 08 81 02 95 01 75 08 81 03 95 05 75 01
 05 08 19 01 29 05 91 02 95 01 75 03 91 03 95 E0
 75 01 15 00 25 01 05 07 19 00 29 DF 81 02 C0

001:005:001:DESCRIPTOR         1713489935.697443
 05 01 09 02 A1 01 85 01 09 01 A1 00 05 09 19 01
 29 05 15 00 25 01 95 05 75 01 81 02 95 01 75 03
 81 01 05 01 09 30 09 31 15 81 25 7F 95 02 75 08
 81 06 09 38 15 81 25 7F 95 01 75 08 81 06 05 0C
 0A 38 02 15 81 25 7F 95 01 75 08 81 06 C0 C0

001:005:000:DESCRIPTOR         1713489935.698194
 05 01 09 06 A1 01 85 01 05 07 19 E0 29 E7 15 00
 25 01 95 08 75 01 81 02 95 01 75 08 81 01 05 08
 19 01 29 05 95 05 75 01 91 02 95 01 75 03 91 01
 05 07 19 00 2A FF 00 15 00 26 FF 00 95 06 75 08
 81 00 C0 05 01 09 02 A1 01 85 02 09 01 A1 00 05
 09 19 01 29 05 15 00 25 01 95 05 75 01 81 02 95
 01 75 03 81 01 05 01 09 30 09 31 15 00 26 FF 7F
 75 10 95 02 81 02 09 38 15 81 25 7F 95 01 75 08
 81 06 95 01 75 08 81 01 C0 C0

```

And lsusb -v
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
hrvach, 2024-04-21:
Output (Constant, Variable),
    Report Count (224),
    Report Size (1),

Your keyboard is NKRO, that's not supported yet.. it should work in boot mode though, but I suspect it's also a mouse. Can you try rebuilding with ENFORCE_PORTS set to 1 in user_config.h ?

hrvach, 2024-05-24:
@infosecconsultant is there a change with the latest experimental BETA (https://github.com/hrvach/deskhop/releases/tag/v0.60) ?

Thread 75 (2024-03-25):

使用键盘快捷键动态调整鼠标的移动速度

youxinweizhi, 2024-03-25:
鼠标的移动速度在编译固件前由下面的配置定义好的，但是并不能很好的满足需求，是否可以考虑使用键盘快捷键动态调整鼠标的移动速度？
#define MOUSE_SPEED_A_FACTOR_X 30
#define MOUSE_SPEED_A_FACTOR_Y 30

hrvach, 2024-03-25:
Please be so kind to write in English, my Chinese is not very good :-)

Closed 2024-03-25.

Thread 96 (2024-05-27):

PCB v1.1 - Board A pin 3 additional pad not through-hole

ddragic, 2024-05-27:
First of, awesome project, thanks for making it!

I noticed on PCB rev1 the additional pad for pin 3 (GND) for Board A Pico is not set to Through-hole.
I'm guessing it was just missed and left as SMD pad type?

hrvach, 2024-05-28:
It's amazing how many times you can look at something and still not see it! 😄 thank you for catching this. I'll try to fix as soon as possible.

collinjc, 2024-06-12:
I also missed this. Just had boards made. Will this impact functionality?

hrvach, 2024-06-13:
> I also missed this. Just had boards made. Will this impact functionality?

No, don't worry about it. Will fix soon

Closed 2024-09-14.

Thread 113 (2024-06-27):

Ubuntu  p22.04 : Build error

OrpheeGT, 2024-06-27:
Hello,

I'm not able to build from source on Ubuntu 22.04.

I first had the following error :

```
cmake -S . -B build
PICO_SDK_PATH is /home/orphee/Downloads/PCB/deskhop/pico-sdk
Defaulting PICO_PLATFORM to rp2040 since not specified.
Defaulting PICO platform compiler to pico_arm_gcc since not specified.
-- Defaulting build type to 'Release' since not specified.
PICO compiler is pico_arm_gcc
CMake Error at pico-sdk/cmake/preload/toolchains/find_compiler.cmake:28 (message):
  Compiler 'arm-none-eabi-gcc' not found, you can specify search path with
  "PICO_TOOLCHAIN_PATH".
Call Stack (most recent call first):
  pico-sdk/cmake/preload/toolchains/pico_arm_gcc.cmake:20 (pico_find_compiler)
  /usr/share/cmake-3.22/Modules/CMakeDetermineSystem.cmake:124 (include)
  CMakeLists.txt:12 (project)

CMake Error: CMake was unable to find a build program corresponding to "Unix Makefiles".  CMAKE_MAKE_PROGRAM is not set.  You probably need to select a different build tool.
CMake Error: CMAKE_C_COMPILER not set, after EnableLanguage
CMake Error: CMAKE_CXX_COMPILER not set, after EnableLanguage
CMake Error: CMAKE_ASM_COMPILER not set, after EnableLanguage
-- Configuring incomplete, errors occurred!
```

Fixed by installing `gcc-arm-none-eabi` package

But now i have the following error :

```
$ cmake -S . -B build
PICO_SDK_PATH is /home/orphee/Downloads/PCB/deskhop/pico-sdk
Defaulting PICO_PLATFORM to rp2040 since not specified.
Defaulting PICO platform compiler to pico_arm_gcc since not specified.
-- Defaulting build type to 'Release' since not specified.
PICO compiler is pico_arm_gcc
-- The C compiler identification is GNU 10.3.1
-- The CXX compiler identification is GNU 10.3.1
-- The ASM compiler identification is GNU
-- Found assembler: /usr/bin/arm-none-eabi-gcc
-- Detecting C compiler ABI info
-- Detecting C compiler ABI info - done
-- Check for working C compiler: /usr/bin/arm-none-eabi-gcc - skipped
-- Detecting C compile features
-- Detecting C compile features - done
-- Detecting CXX compiler ABI info
-- Detecting CXX compiler ABI info - done
-- Check for working CXX compiler: /usr/bin/arm-none-eabi-g++ - skipped
-- Detecting CXX compile features
-- Detecting CXX compile features - done
Build type is Release
Defaulting PICO target board to pico since not specified.
Using board configuration from /home/orphee/Downloads/PCB/deskhop/pico-sdk/src/boards/include/boards/pico.h
-- Found Python3: /usr/bin/python3.10 (found version "3.10.12") found components: Interpreter
TinyUSB available at /home/orphee/Downloads/PCB/deskhop/pico-sdk/lib/tinyusb/src/portable/raspberrypi/rp2040; enabling build support for USB.
-- Configuring done
-- Generating done
-- Build files have been written to: /home/orphee/Downloads/PCB/deskhop/build

$ cmake --build build
Scanning dependencies of target bs2_default
[  1%] Building ASM object pico-sdk/src/rp2_common/boot_stage2/CMakeFiles/bs2_default.dir/compile_time_choice.S.obj
[  1%] Linking ASM executable bs2_default.elf
[  1%] Built target bs2_default
[  2%] Generating bs2_default.bin
[  2%] Generating bs2_default_padded_checksummed.S
[  2%] Built target bs2_default_padded_checksummed_asm
[  3%] Creating directories for 'PioasmBuild'
[  4%] No download step for 'PioasmBuild'
[  5%] No update step for 'PioasmBuild'
[  5%] No patch step for 'PioasmBuild'
[  5%] Performing configure step for 'PioasmBuild'
loading initial cache file /home/orphee/Downloads/PCB/deskhop/build/pioasm/tmp/PioasmBuild-cache-Release.cmake
-- The CXX compiler identification is GNU 13.1.0
-- Detecting CXX compiler ABI info
-- Detecting CXX compiler ABI info - done
-- Check for working CXX compiler: /usr/bin/c++ - skipped
-- Detecting CXX compile features
-- Detecting CXX compile features - done
-- Configuring done
-- Generating done
-- Build files have been written to: /home/orphee/Downloads/PCB/deskhop/build/pioasm
[  5%] Performing build step for 'PioasmBuild'
[ 10%] Building CXX object CMakeFiles/pioasm.dir/main.cpp.o
[ 20%] Building CXX object CMakeFiles/pioasm.dir/pio_assembler.cpp.o
[ 30%] Building CXX object CMakeFiles/pioasm.dir/pio_disassembler.cpp.o
[ 40%] Building CXX object CMakeFiles/pioasm.dir/gen/lexer.cpp.o
[ 50%] Building CXX object CMakeFiles/pioasm.dir/gen/parser.cpp.o
[ 60%] Building CXX object CMakeFiles/pioasm.dir/c_sdk_output.cpp.o
[ 70%] Building CXX object CMakeFiles/pioasm.dir/python_output.cpp.o
[ 80%] Building CXX object CMakeFiles/pioasm.dir/hex_output.cpp.o
[ 90%] Building CXX object CMakeFiles/pioasm.dir/ada_output.cpp.o
[100%] Linking CXX executable pioasm
[100%] Built target pioasm
[  5%] No install step for 'PioasmBuild'
[  6%] Completed 'PioasmBuild'
[  6%] Built target PioasmBuild
[  6%] Generating usb_tx.pio.h
[  6%] Built target Pico-PIO-USB_usb_tx_pio_h
[  7%] Generating usb_rx.pio.h
[  7%] Built target Pico-PIO-USB_usb_rx_pio_h
Scanning dependencies of target Pico-PIO-USB
[  7%] Building C object CMakeFiles/Pico-PIO-USB.dir/Pico-PIO-USB/src/pio_usb.c.obj
[  8%] Building C object CMakeFiles/Pico-PIO-USB.dir/Pico-PIO-USB/src/pio_usb_host.c.obj
[  8%] Building C object CMakeFiles/Pico-PIO-USB.dir/Pico-PIO-USB/src/usb_crc.c.obj
[  9%] Building C object CMakeFiles/Pico-PIO-USB.dir/pico-sdk/src/rp2_common/pico_stdlib/stdlib.c.obj
[  9%] Building C object CMakeFiles/Pico-PIO-USB.dir/pico-sdk/src/rp2_common/hardware_gpio/gpio.c.obj
[ 10%] Building C object CMakeFiles/Pico-PIO-USB.dir/pico-sdk/src/rp2_common/pico_platform/platform.c.obj
[ 10%] Building C object CMakeFiles/Pico-PIO-USB.dir/pico-sdk/src/rp2_common/hardware_claim/claim.c.obj
[ 10%] Building C object CMakeFiles/Pico-PIO-USB.dir/pico-sdk/src/rp2_common/hardware_sync/sync.c.obj
[ 11%] Building C object CMakeFiles/Pico-PIO-USB.dir/pico-sdk/src/rp2_common/hardware_irq/irq.c.obj
[ 11%] Building ASM object CMakeFiles/Pico-PIO-USB.dir/pico-sdk/src/rp2_common/hardware_irq/irq_handler_chain.S.obj
[ 12%] Building C object CMakeFiles/Pico-PIO-USB.dir/pico-sdk/src/common/pico_sync/sem.c.obj
[ 12%] Building C object CMakeFiles/Pico-PIO-USB.dir/pico-sdk/src/common/pico_sync/lock_core.c.obj
[ 13%] Building C object CMakeFiles/Pico-PIO-USB.dir/pico-sdk/src/common/pico_sync/mutex.c.obj
[ 13%] Building C object CMakeFiles/Pico-PIO-USB.dir/pico-sdk/src/common/pico_sync/critical_section.c.obj
[ 13%] Building C object CMakeFiles/Pico-PIO-USB.dir/pico-sdk/src/common/pico_time/time.c.obj
[ 14%] Building C object CMakeFiles/Pico-PIO-USB.dir/pico-sdk/src/common/pico_time/timeout_helper.c.obj
[ 14%] Building C object CMakeFiles/Pico-PIO-USB.dir/pico-sdk/src/rp2_common/hardware_timer/timer.c.obj
[ 15%] Building C object CMakeFiles/Pico-PIO-USB.dir/pico-sdk/src/common/pico_util/datetime.c.obj
[ 15%] Building C object CMakeFiles/Pico-PIO-USB.dir/pico-sdk/src/common/pico_util/pheap.c.obj
[ 16%] Building C object CMakeFiles/Pico-PIO-USB.dir/pico-sdk/src/common/pico_util/queue.c.obj
[ 16%] Building C object CMakeFiles/Pico-PIO-USB.dir/pico-sdk/src/rp2_common/hardware_uart/uart.c.obj
[ 16%] Building C object CMakeFiles/Pico-PIO-USB.dir/pico-sdk/src/rp2_common/hardware_clocks/clocks.c.obj
[ 17%] Building C object CMakeFiles/Pico-PIO-USB.dir/pico-sdk/src/rp2_common/hardware_pll/pll.c.obj
[ 17%] Building C object CMakeFiles/Pico-PIO-USB.dir/pico-sdk/src/rp2_common/hardware_vreg/vreg.c.obj
[ 18%] Building C object CMakeFiles/Pico-PIO-USB.dir/pico-sdk/src/rp2_common/hardware_watchdog/watchdog.c.obj
[ 18%] Building C object CMakeFiles/Pico-PIO-USB.dir/pico-sdk/src/rp2_common/hardware_xosc/xosc.c.obj
[ 19%] Building ASM object CMakeFiles/Pico-PIO-USB.dir/pico-sdk/src/rp2_common/hardware_divider/divider.S.obj
[ 19%] Building C object CMakeFiles/Pico-PIO-USB.dir/pico-sdk/src/rp2_common/pico_runtime/runtime.c.obj
[ 19%] Building C object CMakeFiles/Pico-PIO-USB.dir/pico-sdk/src/rp2_common/pico_printf/printf.c.obj
[ 20%] Building ASM object CMakeFiles/Pico-PIO-USB.dir/pico-sdk/src/rp2_common/pico_bit_ops/bit_ops_aeabi.S.obj
[ 20%] Building C object CMakeFiles/Pico-PIO-USB.dir/pico-sdk/src/rp2_common/pico_bootrom/bootrom.c.obj
[ 21%] Building ASM object CMakeFiles/Pico-PIO-USB.dir/pico-sdk/src/rp2_common/pico_divider/divider.S.obj
[ 21%] Building ASM object CMakeFiles/Pico-PIO-USB.dir/pico-sdk/src/rp2_common/pico_double/double_aeabi.S.obj
[ 22%] Building C object CMakeFiles/Pico-PIO-USB.dir/pico-sdk/src/rp2_common/pico_double/double_init_rom.c.obj
[ 22%] Building C object CMakeFiles/Pico-PIO-USB.dir/pico-sdk/src/rp2_common/pico_double/double_math.c.obj
[ 22%] Building ASM object CMakeFiles/Pico-PIO-USB.dir/pico-sdk/src/rp2_common/pico_double/double_v1_rom_shim.S.obj
[ 23%] Building ASM object CMakeFiles/Pico-PIO-USB.dir/pico-sdk/src/rp2_common/pico_int64_ops/pico_int64_ops_aeabi.S.obj
[ 23%] Building ASM object CMakeFiles/Pico-PIO-USB.dir/pico-sdk/src/rp2_common/pico_float/float_aeabi.S.obj
[ 24%] Building C object CMakeFiles/Pico-PIO-USB.dir/pico-sdk/src/rp2_common/pico_float/float_init_rom.c.obj
[ 24%] Building C object CMakeFiles/Pico-PIO-USB.dir/pico-sdk/src/rp2_common/pico_float/float_math.c.obj
[ 25%] Building ASM object CMakeFiles/Pico-PIO-USB.dir/pico-sdk/src/rp2_common/pico_float/float_v1_rom_shim.S.obj
[ 25%] Building C object CMakeFiles/Pico-PIO-USB.dir/pico-sdk/src/rp2_common/pico_malloc/pico_malloc.c.obj
[ 25%] Building ASM object CMakeFiles/Pico-PIO-USB.dir/pico-sdk/src/rp2_common/pico_mem_ops/mem_ops_aeabi.S.obj
[ 26%] Building ASM object CMakeFiles/Pico-PIO-USB.dir/pico-sdk/src/rp2_common/pico_standard_link/crt0.S.obj
[ 26%] Building CXX object CMakeFiles/Pico-PIO-USB.dir/pico-sdk/src/rp2_common/pico_standard_link/new_delete.cpp.obj
[ 27%] Building C object CMakeFiles/Pico-PIO-USB.dir/pico-sdk/src/rp2_common/pico_standard_link/binary_info.c.obj
[ 27%] Building C object CMakeFiles/Pico-PIO-USB.dir/pico-sdk/src/rp2_common/pico_stdio/stdio.c.obj
[ 28%] Building C object CMakeFiles/Pico-PIO-USB.dir/pico-sdk/src/rp2_common/pico_stdio_uart/stdio_uart.c.obj
[ 28%] Building C object CMakeFiles/Pico-PIO-USB.dir/pico-sdk/src/rp2_common/pico_multicore/multicore.c.obj
[ 28%] Building C object CMakeFiles/Pico-PIO-USB.dir/pico-sdk/src/rp2_common/hardware_pio/pio.c.obj
[ 29%] Building C object CMakeFiles/Pico-PIO-USB.dir/pico-sdk/src/rp2_common/hardware_dma/dma.c.obj
[ 29%] Linking CXX static library libPico-PIO-USB.a
[ 29%] Built target Pico-PIO-USB
[ 29%] Creating directories for 'ELF2UF2Build'
[ 29%] No download step for 'ELF2UF2Build'
[ 29%] No update step for 'ELF2UF2Build'
[ 30%] No patch step for 'ELF2UF2Build'
[ 31%] Performing configure step for 'ELF2UF2Build'
-- The C compiler identification is GNU 13.1.0
-- The CXX compiler identification is GNU 13.1.0
-- Detecting C compiler ABI info
-- Detecting C compiler ABI info - done
-- Check for working C compiler: /usr/bin/cc - skipped
-- Detecting C compile features
-- Detecting C compile features - done
-- Detecting CXX compiler ABI info
-- Detecting CXX compiler ABI info - done
-- Check for working CXX compiler: /usr/bin/c++ - skipped
-- Detecting CXX compile features
-- Detecting CXX compile features - done
-- Configuring done
-- Generating done
-- Build files have been written to: /home/orphee/Downloads/PCB/deskhop/build/elf2uf2
[ 31%] Performing build step for 'ELF2UF2Build'
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
hrvach, 2024-06-27:
Try git pulling again and rebuilding, moved that variable out of the case block... it's funny, doesn't complain for me.

OrpheeGT, 2024-06-27:
Thanks I will try just now.

another question :
https://github.com/hrvach/deskhop/blob/main/src/user_config.h#L35

How to set combined key ? like SHIFT + CAPS ?

hrvach, 2024-06-27:
Check keyboard.c, there is a hotkey_combo_t struct at the beginning. It's hopefully well documented.

OrpheeGT, 2024-06-27:
Ok,

Replacing https://github.com/hrvach/deskhop/blob/main/src/keyboard.c#L26

by `    {.modifier       = KEYBOARD_MODIFIER_LEFTSHIFT,`

Should do the job if I understood the other combos correctly :)

OrpheeGT, 2024-06-27:
Thanks, it works now ;)

Closed 2024-06-27.

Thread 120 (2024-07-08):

v1 PCB from elecrow

jnichols35, 2024-07-08:
I ordered the PCB from elecrow and didn't see an option to select which version of the PCB and assumed it was the v1.1 based on the pictures. I ordered the BOM for v1.1, so now I'm not sure what to do.

Has this happened to anyone else?

hrvach, 2024-07-08:
Don't worry - I believe they don't even do v1.0. You should be fine! If you get stuck during assembly, let me know and I'll try helping out.

jnichols35, 2024-07-08:
Sorry, I already received the PCB, and it's for v1.
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

hrvach, 2024-07-08:
Oh man, I had no idea ... I'll try asking them why the pcb 1.0 is even sold - this should not be the case. 0805 caps will be a bit smaller but I've fit them into 1206 many times when I didn't have 1206 (and vice versa, but that's embarassing to admit)

OrpheeGT, 2024-07-09:
Does it means even if you order the whole package, it comes disassembled ? I expected it to be all soldered / ready to use... ?

hrvach, 2024-07-09:
I believe it comes assembled if you order the whole package, or just the assembled board. The only way you'd need to solder if you order just the bare PCB (that's my understanding). I asked Elecrow and they agreed to switch to v1.1, my assumption is after they clear out existing stock.

jnichols35, 2024-07-09:
@hrvach Thanks for looking into this, I also emailed Elecrow about it. I think having the option to choose which version of the board would be enough. Was confusing since their pictures were pretty much all for the updated PCB.

Regardless, I'm good here, going to see about getting the BOM for v1 and just make both versions for fun.

hrvach, 2024-07-09:
> @hrvach Thanks for looking into this, I also emailed Elecrow about it. I think having the option to choose which version of the board would be enough. Was confusing since their pictures were pretty much all for the updated PCB.
>
> Regardless, I'm good here, going to see about getting the BOM for v1 and just make both versions for fun.

I'm really sorry about the confusion, some things get lost in translation and it's very hard to know what's actually shipped when you have no insight into it...

Best of luck with assembling it and hope it works on the first try! :)

Closed 2024-07-09.

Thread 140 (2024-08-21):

no power?

Omgmydogisdead, 2024-08-21:
when the keyboard and mouse were plugged in, their LEDs flashed on for a second before going away again. I have already flashed the code onto the Raspberry Pi and everything should be correctly placed on the PCB(Look image below, currently powered off). I have plugged the device into a MacBook Pro (2018) and a framework 13.
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

Omgmydogisdead, 2024-08-22:
nevermind, the capacitor was soldered opposite but there is another issue

Closed 2024-08-22.

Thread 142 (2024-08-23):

TMK keyboard not relaying input to the connected computers

dsemi, 2024-08-23:
I have a Leopold FC660C running [TMK](https://github.com/tmk/tmk_keyboard) that doesn't appear to be working with the deskhop.
When plugging in I see the LED flash twice, but no keyboard output ever appears to reach the host computer. Hotkeys for opening up configuration, etc. don't appear to work either.

I can verify that the deskhop itself is working; a different keyboard I tried is working as expected. I also tried compiling the firmware with ENFORCE_PORTS, that didn't make a difference.

I'm assuming the issue is related to the keyboard firmware, would it be possible to add support? Please let me know if there's information I can dump from the board, usb events, etc. that would be helpful in diagnosing the issue.
Somewhat related, is there a more detailed guide on debugging? I'm not familiar with how one would attach a debugger, see log messages, etc. for the pico firmware. If that's easy enough to do then I could be more active in diagnosing why the keyboard isn't functional.

hrvach, 2024-08-23:
Sure, can you please dump the descriptor using usbhid-dump -e descriptor  on Linux? I'm interested in extending support for various keyboards and learning what case I'm not handling properly is essential to that effort. Thanks!

dsemi, 2024-08-23:
Sure, here you go:

```
$ sudo usbhid-dump -e descriptor
001:012:004:DESCRIPTOR         1724451626.060660
 05 01 09 06 A1 01 05 07 19 E0 29 E7 15 00 25 01
 95 08 75 01 81 02 05 08 19 01 29 05 95 05 75 01
 91 02 95 01 75 03 91 01 05 07 19 00 29 F7 15 00
 25 01 95 F8 75 01 81 02 C0

001:012:003:DESCRIPTOR         1724451626.068659
 06 31 FF 09 74 A1 01 09 75 15 00 26 FF 00 95 20
 75 08 81 02 09 76 15 00 26 FF 00 95 20 75 08 91
 02 C0

001:012:002:DESCRIPTOR         1724451626.078663
 05 01 09 80 A1 01 85 02 16 01 00 26 37 00 1A 81
 00 2A B7 00 75 10 95 01 81 00 C0 05 0C 09 01 A1
 01 85 03 16 01 00 26 9C 02 1A 01 00 2A 9C 02 75
 10 95 01 81 00 C0

001:012:001:DESCRIPTOR         1724451626.091655
 05 01 09 02 A1 01 09 01 A1 00 05 09 19 01 29 05
 15 00 25 01 95 05 75 01 81 02 95 01 75 03 81 01
 05 01 09 30 09 31 15 81 25 7F 95 02 75 08 81 06
 09 38 15 81 25 7F 95 01 75 08 81 06 05 0C 0A 38
 02 15 81 25 7F 95 01 75 08 81 06 C0 C0

001:012:000:DESCRIPTOR         1724451626.102658
 05 01 09 06 A1 01 05 07 19 E0 29 E7 15 00 25 01
 95 08 75 01 81 02 95 01 75 08 81 01 05 08 19 01
 29 05 95 05 75 01 91 02 95 01 75 03 91 01 05 07
 19 00 29 FF 15 00 26 FF 00 95 06 75 08 81 00 C0

```

hrvach, 2024-08-23:
I think I know what it is, there was another report with the same root cause - NKRO with no report ID. That is an unsupported case I need to fix, somehow strangely assumed NKRO would always come with report ID.

The fix shouldn't be super complicated, maybe removing:

```
     if (report_id > 0
        && report_id == iface->keyboard.nkro.report_id
```
and leaving just if (iface->keyboard.is_nkro) in hid_report.c might work here.

dsemi, 2024-08-23:
Unfortunately that doesn't seem to have helped.

Should there be that many descriptors in the output? I unplugged everything except the keyboard before running `usbhid-dump` and there were still 5 descriptors.
Could it be something like what you mentioned [here](https://github.com/hrvach/deskhop/issues/71#issuecomment-2016583247)?

hrvach, 2024-08-24:
You could try checking how to disable nkro on tmk but I would prefer to actually fix it, give me a bit to look into the code and try a few things first

hrvach, 2024-08-24:
Any chance you might be able to try [this one](https://github.com/user-attachments/files/16737175/deskhop.zip) for me? Don't have a similar keyboard so it's hard for me to recreate, so I'm just guessing what's happening but curious if this would fix the issue you're experiencing. Thanks!

dsemi, 2024-08-24:
That works! I had a couple times where I started typing and after a few keys it seemed to get stuck again, but unplugging and re-plugging the keyboard seems to have at least fixed it for now; I can't reproduce anymore.

Thanks! What was the change that did it?

hrvach, 2024-08-24:
Hopefully no keyboard replugging should be needed, please test a bit more and let me know. The case with no report ID and ITF protocol NONE was not covered for some reason, I'll be releasing a fix soon...

dsemi, 2024-08-24:
Yeah, something is still a bit off. It was working well for a bit connected only to one computer, but once I connected the other and added the mouse, I could consistently get to a state where the keyboard input stops working.

I noticed that when I stopped moving the mouse, the deskhop would regularly trigger the LEDs back and forth between A and B, like it wasn't sure which computer to output to? It didn't seem to affect the behavior of the mouse, but it lags keyboard input to B during that alternation. And eventually it would hit a state where the keyboard stops working altogether and I have to reset. Haven't found a consistent repro for that fully non-working state, but I'll play around with it some more.

A couple other things I noticed:
- The shortcut for opening the web configuration is not working (left shift + right shift + c + o). Not sure if that's an issue with the firmware or if the keyboard just doesn't like sending both shifts. I'd try remapping it, but I'm not sure what changes you made, so I can't try recompiling with a different shortcut, and I can't get the web config to open to remap it
- Other keyboard shortcuts appear to be working. I tried right ctrl + k and the mouse locks to the current screen as expected. Is it intentional for the keyboard shortcuts to pass through keys to the computer? When I press ctrl + k it locks to output, but still sends a 'k' that I can see if I have a text field focused when I do it. Not sure if this is specific to this keyboard or just a general bug

hrvach, 2024-08-24:
With latest rev 0.63 it was changed to left ctrl + right shift + c + o because a few people complained their keyboards can't send both shifts - that was a bad choice to begin with.

Passthrough for shortcuts can be explicitly specified, for ctrl + K it should be disabled, I'll check. If your LEDs regularly go back and forth, device is probably rebooting. Maybe excessive current, or hitting some weird bug. Does it happen with a different keyboard as well?

dsemi, 2024-08-24:
> With latest rev 0.63 it was changed to left ctrl + right shift + c + o because a few people complained their keyboards can't send both shifts - that was a bad choice to begin with.

Ah, I missed that. Ok can confirm that is working fine then.

>  If your LEDs regularly go back and forth, device is probably rebooting. Maybe excessive current, or hitting some weird bug. Does it happen with a different keyboard as well?

Yes it does happen with a different keyboard. I don't think it's excessive current, it actually only happens when the mouse is plugged in. Even if no keyboard is connected and just the mouse it's doing that. This is also present in 0.63, so maybe a separate issue with my mouse.

hrvach, 2024-08-24:
Changing shortcuts is super bad, I apologise for the confusion, all my keyboards can send both shifts so only later I realised some can't. Pre-release 0.64 is published with a few fixes, thank you for reporting this kbd issue, I somehow missed covering this case.

dsemi, 2024-08-24:
Thanks for the quick fixes! I'll mark this as fixed and file a separate issue for the mouse as that seems to be unrelated to the keyboard.

Closed 2024-08-24.

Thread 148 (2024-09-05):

Mouse movement duplicated on second monitor

github-k8n, 2024-09-05:
With my current settings (see below) it seems that sometimes my mouse movement on the right monitor (Linux, Output A) is duplicated on the left one (Windows, 2 monitors, one builtin and one connected, the connected monitor is exactly the same as the one from the Linux system.
Only mouse movement is duplicated not any clicks or keyboard entries. I can fix it by moving the mouse all way to the left (over the connected monitor of the Windows system and on to the builtin monitor) and then back again to the Linux system then everything is ok again for a while.
I have a suspicion that it could be related to either the Cursor park position or the Screensaver mode.

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

hrvach, 2024-09-07:
Thank you for a good problem description! If you reconfigure the cursor park position to something else, does that seem to change the behaviour?

github-k8n, 2024-09-07:
Cursor park position does not affect it (set to Top), it still mirrors the movement. However when I set the Screensaver mode from Jitter to Pong, it does no longer cause the same "mirrored mouse" behavior (obviously the mouse will now move in the "pong" zigzag movement on the left (B, Windows) screen which is expected.

=====

I also noticed another behavior, maybe I should open another case for that (let me know and I'll copy/paste it) but wanted to mention it here as well.
(Again, the physical screen layout from left to right:   (B: Builtin Windows, B: External Windows, A: External Linux)

When moving the mouse cursor to the left until it reaches the Builtin Windows screen, it seems the acceleration is suddenly no longer working. Cursor becomes slow (non-accelerated) even when back on the External Windows screen. It only goes back to normal once it reaches the A: External Linux screen. As long as I keep the mouse on the External screens (B: External Windows, A: External Linux) the mouse acceleration will work fine. (maybe some issue with the dual screen stuff on Windows)?

github-k8n, 2024-09-07:
Oh and just because I didn't mention it earlier: it seems to start (the mirrored mouse movement) reproducibly after the screensaver timeout (when using "Jitter").

hrvach, 2024-09-10:
I am struggling to reproduce this, but I'm convinced you get sort of a "split brain" scenario. Next release should have a fix for that, but I'm still unsure of the scenario how it might happen.

github-k8n, 2024-11-19:
Issue still persists with latest release. While luckily only the movement is duplicated, not the clicks, it is highly distracting to have that movement on the other screen, possibly causing confusion as to which screen is actually being controlled.
Again, this only happens with "jitter" screensaver mode, "pong" is not affected.

I'd be happy to test any test firmware you can provide me with, i also have the debug pins populated.
If you tell me what exactly is being outputted (protocol etc) maybe I can get some output there.
I have an FTDI232 usb to TTL adapter, an rs485 to ttl adapter and a bunch of ESPs, or let me know what exactly I would need... (not really sure how to connect to the GND/DATA/CLK connector)

github-k8n, 2024-11-20:
I think there might be some issue with the code?  (the || seems to be part of something else that was cut off... )
Did you maybe mean the following?

```
    case JITTER:

            if (report.x + jitter < MIN_SCREEN_COORD) {
                report.x ++;
            } else if ( report.x + jitter > MAX_SCREEN_COORD) {
                report.x --;
            }

            report.x += jitter;
            jitter = -jitter;
            break;
```

github-k8n, 2024-11-20:
Is jitter always  +1 or -1 ?
Otherwise maybe you can just return report.x instead of first reducing it and adding jitter agin.
```
report.x = (report.x + jitter < MIN_SCREEN_COORD) ? report.x : report.x + jitter;
report.x = (report.x + jitter > MAX_SCREEN_COORD) ? report.x : report.x + jitter;
jitter = -jitter;
break;
```

github-k8n, 2024-11-20:
And the issue still happens ... :(

hrvach, 2024-11-27:
Can you remove all code in the jitter section, just leave the break. Still happens? I'm struggling to recreate. Both boxes think they are masters, but not sure how that would happen using a screensaver.

eltariel, 2024-11-29:
I'm also seeing this behaviour today. Not sure if I've seen it before.

I'm running the same physical layout but both hosts are on MacOS. I'm not sure what the screen saver mode is on this particular device but will look into it some more when I'm done at $work for the day.

hrvach, 2024-12-03:
Any new findings @eltariel ? I have never noticed this yet, but would really like to squash that bug if possible because it seems quite annoying for the user.

eltariel, 2024-12-04:
Haven't had a chance to dig any deeper, but some additional details:

- turning jitter off made the issue stop
- doesn't happen in pong screensaver mode but that's too distracting for me to use
- mouse movements when B is active never get duplicated on A
- unplugging A when B is duplicating breaks it even more: it still follows mouse movements but it won't switch screen and the buttons do nothing. I only tried this once 🤣

eltariel, 2024-12-04:
Think I've figured it out...

When a mouse report is received, we update `state->position_x/y` from the report values. This goes into global state *on the receiving device* - in most cases that's B - before it gets output either directly to a report or via the UART. [link](https://github.com/hrvach/deskhop/blob/cbb98e4a88e8123004405bc3f0fc6b5be7f2cc3b/src/mouse.c#L79)

The jitter screensaver works by alternately adding or subtracting 1 from `state->position_x/y` - *which is set on every incoming mouse report!*

I was going to suggest we might want to just swap the jitter implementation for a relative report instead of the absolute one, but now I'm pretty sure it'll fix it. I'll take a stab at it tonight if I find a moment.

hrvach, 2024-12-04:
@github-k8n I finally managed to recreate it, it's clear what's happening now. And yes - I can see how super annoying it is. :)

@eltariel tough one, but you figured it out! Even while being an inactive output, pointer_x keeps getting updated locally if the output is idle and screensaver active resulting in a sort of bias to base position the jitter moves around, and the bias value is derived form current mouse position. Fun :)

Relative indeed fixes it but now I've spotted another issue - mouse seems to have a non-zero net movement (to the left in my case), slowly progressing towards the other side. It also wiggles a lot, let me pull in your pr and provide some additional tweaks. Once again, thank you!

Closed 2024-12-04.

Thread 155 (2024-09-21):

El Capitan mouse wont work

tgrrr, 2024-09-21:
Hi,

Big fan, love the project.

It works great with a wired mouse and keyboard. Everything works as expected.

When I try with El Capitan, the mouse wont move between monitors. It gets stuck on the non-El Capitan monitor.
- Keyboard works
- Mouse doesn't. It disappears from the first device as expected. It just doesn't appear on the second device

I've tested:

- Two devices with El Capitan installed (combined with a Mac or Windows machine)
- Multiple Mice, keyboards, etc.
- Everything in the FAQ
- The mouse works great when connected directly to the computer (without the deskhop)
- El Capitan can see the DeskHop Switch as a USB device

Both devices load El Capitan via SSD, is the only thing that's unique about the setup, and in common between the two devices both running El Capitan

El Capitan (10.11.6)
Deskhop (0.65)

Other devices include:
- Mac M1
- Windows 10

hrvach, 2024-09-21:
If you move the mouse towards the El Capitan box, other board led lights up and nothing happens? Can you try entering the "gaming mode" when the pico led is on on the El Capitan output to see if you can get mouse to work at all?

tgrrr, 2024-09-22:
> If you move the mouse towards the El Capitan box, other board led lights up and nothing happens?

Yes, that's spot on.

> Can you try entering the "gaming mode" when the pico led is on on the El Capitan output to see if you can get mouse to work at all?

Gaming mode fixes the problem, thanks. Happy to close this as resolved.

Out of interest:

One strange side-effect is _sometimes_ the mouse stops 3/4 of the way across the M1, when I connect to an external (wide) monitor. This only seems to happen while in gaming mode where the other computer is the El Capitan machine.

Wide monitor:
LG 34WL500
2560 x 1080 resolution

Unplugging the computer's USB connections and plugging them in again generally resolves the problem.

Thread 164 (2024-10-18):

There is a better idea, Implementing HID KM with ESP32C3 BLE.

qq8322302, 2024-10-18:
Hello,hrvach:
    I am an electronics enthusiast from China and came across your project by chance. It is a fantastic project that can solve many operational problems with multiple hosts.
    I have an idea now, to use ESP32C3 BLE to simulate keyboard, mouse, and communication with multiple devices, and to add lithium batteries to get rid of wiring harnesses.

My thoughts:
    ESP32C3 serves as the main controller, and after turning on BLE, it broadcasts four names: KM1, KM2, KM3, and KM4. Four PCs are connected to each of these four BLE names.
    The IO of ESP32C3 can use software to simulate USB-HOST mode for connecting keyboards and mice.
(ESP32C3's ble_hid_device_demo: esp-idf-v5.2.1/examples/bluetooth/bluedroid/ble/ble_hid_device_demo)
(ESP32C3 software simulation USB-HOST: https://github.com/sdima1357/esp32_usb_soft_host )
    ESP32C3-FH4， In China, it only costs RMB 5 yuan, and materials such as batteries and casings are also very cheap. I can design and produce PCB hardware, but my software level is not very good. I wonder if you are interested in researching together?We look forward to your reply.

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

chri2, 2024-10-20:
Sounds nice - I couldn't use it.

It will be a different device for end users without security needs.

My use case includes that I'm forbidden by rules at my work to use any keyboard that is connected wireless.

Making your project secure includes having a secure bluetooth stack which until now proved many times to be a wrong assumption.

Another point for me would be the needless use of batteries. That is not sustainable. There is no reason I can see that your idea couldn't work with one computer being connected through usb providing the power needed to drive your board (or just use an external usb power adaptor which in on most desks anyway.

I'd build or buy one for testing if it would work without a battery just for the fun of it and maybe to give it to my son to switch between his mobile and his desktop. On my desktop I couldn't use it for security reasons.

qq8322302, 2024-10-21:
@chri2    If for absolute safety, then wireless and lithium batteries are indeed not a good idea. Both will have certain security risks.
If it's for convenience and a clean desktop, then wireless and lithium batteries will definitely be more convenient.
This involves different usage scenarios.

tegger2000, 2024-10-23:
Maybe this project could be a base for your idea: https://github.com/Noskcaj19/hardware-kvm

hrvach, 2024-10-23:
This is a cool idea - I've investigated ESP32 initially but it didn't have usb. My plan is to expand the nunmber of devices one can control, my initial thoughts were most people who would use this need 2, a small number might need 3 and very  few people need 4 or more. I agree this would be a desirable feature for sure, I occasionally needed a third output, maybe something happens later this year :)

Some of the technical limitations mentioned were actually chosen on purpose, like omitting Bluetooth - I simply don't believe there is a vendor who could implement this in a way that stands the test of time (https://github.com/engn33r/awesome-bluetooth-security for reference). Bluetooth stacks are often written by coders faced with unrealistic timelines and then never ever patched after vulnerabilities are discovered. The protocol itself is a bit too complicated for a secure implementation.

If you're still interested in helping out, I'd be curious how cheap this board could be made, i.e. what the ultimate price point is for small(er) batches. I'll be working on a new PCB variant when time permits...

qq8322302, 2024-10-26:
Firstly, let me share the desktop shop I created using RP2040 * 2. The PCB was redesigned and streamlined, matched with a metal casing, and the effect was very good.

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

----------------------------------------------------------

I found a similar project for ESP32C3 BLE: USB-HID-BLER, URL: https://github.com/dnstzzx/usb-hid-bler
This project is to convert wired keyboard and mouse to BLE. I built a simple circuit and tested it. The mouse can be used normally, but the keyboard cannot be used.

I have already drawn the PCB according to my idea, and it will take about a week to produce it. I will test it first when the time comes.
There are the following software issues that need to be addressed:
1. I don't know how ESP32C3 can emit KM1, KM2, KM3, KM4, multiple BLE names.
2. The compatibility of USB-HID-BLER is not perfect and needs to be addressed.
3. Need to merge the functions of deshop into it.

Regarding small batch costs:
PCB+materials+shell+production, about RMB 55 yuan.  ($8)

I don't know if you're interested in helping write software? I can provide you with hardware.

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

qq8322302, 2024-10-26:
Additionally, for users who prioritize safety and do not want to use BLE, we can use wired USB. I also have a better idea that can be extended to hardware solutions with 4 or even 8 hosts.
It can be expanded using RP2040 * 1+analog switch+CH9329 * N, and the price is also not expensive.
RP2040 is connected to a keyboard and mouse, and at the same time, it is connected to 4 analog switches through UART * 1. By selecting which CH9329 to communicate with through GPIO, it can easily communicate with 1 out of N PCs. The disadvantage is that it can only communicate with one CH9329 at a time and cannot communicate simultaneously.
If interested, I can also create this form of hardware, but I also need your software support.

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

hrvach, 2024-11-06:
I really like your board and box! Unfortunately I don't have the time resources to rework it with ESP32, but if you want to work towards redesigning some of the existing hardware please let me know :)

qq8322302, 2024-11-06:
I have done some research on the ESP32C3 and wanted to implement desktop functionality, but it turned out to be quite difficult and challenging. Additionally, the security of BLE is not very high, so I decided to abandon the ESP32C3-BLE.
I have redesigned a new board as described above, using 1*RP2040 + 4*CH9329, which can control up to 4 devices. The hardware is already in production and should be available around the 8th.
This hardware architecture can easily control 4 devices or even more, with theoretical support for up to 254 devices. Additionally, the software code modifications for desktop functionality are minimal; it only requires replacing the USB devices section with UART.
Currently, I am trying to modify your software, but it's somewhat challenging for me. Would it be possible to invite you to collaborate on the software development?

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
The circuit board is already in production and should arrive in my hands around November 8th.

teuchezh, 2024-11-08:
In general, seamless switching of a Bluetooth keyboard and mouse between devices sounds cool

qq8322302, 2024-11-11:
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
I am trying to modify the deskhop software, but it will take some time.
PCB size: 94mm * 49mm

hrvach, 2024-11-11:
That's pretty cool, I like the board! Maybe consider adding digital isolators to the outputs?

What's the availability of those WCH9329 and what's the chip next to the left USB-A connector?

qq8322302, 2024-11-12:
1、 The CH9329 is currently in mass production and can be easily purchased, with a price of about $0.3-0.4$ (RMB: 2-3).
2、 The chip next to the left USB-A connector is a USB-HUB chip, which is used to expand the USB-HOST port of the RP2040.
In the Pico-PIO-USB project, I was unable to make it support two USB-HOST ports, so I used a USB-HUB chip for expansion.
3、 The two USB-A ports do not require an additional ESD chip, as ESD protection is already integrated into the USB-HUB chip.
4、 4*CH9329 USB buses might require an additional ESD chip, but I don’t think this is very important.
5、 I do not plan to add digital isolators because, after adding them, the four CH9329 Type-C ports would no longer be able to power the RP2040, which would require an additional power supply for the device. Once the software for the RP2040 Type-C port is debugged, I intend to remove it and not use it for power.
  If digital isolators must be added, then four would be required to isolate all four CH9329 chips. Additionally, the RP2040’s Type-C port would need to be retained for power supply purposes.

frostworx, 2024-11-13:
I found this [bluetooth-usb-peripheral-relay project](https://github.com/bahaaador/bluetooth-usb-peripheral-relay) _(Bluetooth to USB HID relay using a Raspberry Pi Zero )_ earlier today on [ycombinator](https://news.ycombinator.com/item?id=42125863),

which reminded me that I recently wanted to check for a new deskhop firmware.

So here we are - maybe interesting for you :)

qq8322302, 2024-11-16:
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
Here’s the English translation:

I have modified some of the software functions on the original board, and now it is able to support the communication between 4 PCs. Due to issues with the USB hub chip and other factors, I redesigned the PCB, adding digital isolation chips to isolate the 4 PCs from the board. The board is powered via TYPE-C from the RP2040. The CH9329 has a maximum UART baud rate of 115200, so the theoretical maximum mouse report rate is around 400Hz. During testing, I found that when a 1kHz mouse was connected, the movement became sluggish. Optimization will be needed in the software for this in the future.The new PCB is expected to arrive in about 7 days, and I will conduct testing once it arrives.

hrvach, 2024-11-18:
Yeah 115200 is pretty sluggish, but I've ordered one sample chip to play around with it and test how feasible it would be. Interesting concept you've got here. I'm toying with the idea of putting a very low cost linux system-in-package like the f1c100s to handle all the incoming usb host work leveraging the linux kernel drivers for all the strange usb hardware out there and some super-cheap usb-capable microcontrollers for the outputs.

qq8322302, 2024-11-18:
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
ak66666, 2024-12-07:
> @ak66666 Thank you for your suggestion. I will carefully consider placing all cables on one side.

No, thank you, I am looking forward for getting your device when it becomes available.
Now I use Deskhop with two computers.
With 4 ports I should be able to reach to the third one (instead of RDPing into it and suffering from the slow connection), and also the phone.

hrvach, 2024-12-08:
@qq8322302 I am waiting on a sample of WCH IC - CH32V203 that one is supposed to be both cheap and widely available there, I'll see if I can get one working to do anything meaningful.

As far as STC8H2K08U goes, never heard of that one before. Can you point me out to e.g. Aliexpress page where a sample could be ordered? I'm open to trying out anything.

Regarding MMC/USB - as long as initial MMC boot works with USB devices still plugged in, it's fine. I have to test this situation locally, been busy with other bugfixes... My idea is to use the MMC only for a super fast initial boot, loading kernel + micro ramdisk with just a single tiny binary to RAM and execute from there.

qq8322302, 2024-12-08:
The price of CH32V203F6P6 is basically the same as that of STM32F070F6P6, and a 3.3V power supply still requires a 5V to 3.3V LDO.
CH32V203F6P6/STM32F070F6P6/STM32F042F6P6 are pin to pin compatible and can be replaced with each other.
Price: STC8H2K08U<CH32X033F8P6<CH32V203F6P6<STM32F070F6P6<STM32F042F6P6
If I use CH32V203F6P6/STM32F070F6P6/STM32F042F6P6, I think my PCB has already been designed and I can try to make one for testing.
STC8H2K08U and CH32X033F8P6 may be slightly cheaper, but they are not pin to pin compatible, so I don't think it's necessary to consider them.

qq8322302, 2024-12-08:
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
These are two different layouts of MCUs, with STC8H being simpler and
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

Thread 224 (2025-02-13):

Keyboard and Mouse Not Switching Seamlessly

apsessoms, 2025-02-13:
Hello and thank you for providing the community with such an amazing product. My co-worker told me about this and I ordered it immediately. I just need some finishing touches to make it work! :)

I recently purchased the DeskHop-Fast Desktop Switching-Single PCB V1.0 seamlessly switch between my desktop and laptop using a single keyboard and mouse. However, I’m running into an issue where the switching behavior isn't working as expected.

Here’s what I’m experiencing:

- My keyboard works on both my desktop and laptop, but I have to manually press the Computer 1/Computer 2 keys on my Logitech keyboard to switch between them.
- My mouse does not work on my desktop, but the keyboard does.
- My mouse works on my laptop, but the keyboard does not unless I manually toggle between systems using the Logitech keyboard keys.

It seems like DeskHop isn’t recognizing the automatic transition between systems as intended, possibly due to how the Logitech keyboard handles multi-device switching.

Do you have any suggestions on how to troubleshoot or configure DeskHop to resolve this issue? Let me know if you need any additional details!

I have tried to:

- deploy the initial firmware that was uploaded to this repo 4 days to both pico boards
- update the raspbery pico firmware
- read through alll the issues on this github

Thanks for any help!

I am using a Dell Preceision 3480 laptop running windows 10
Home PC running windows 11 pro
logitech wireless keyboard
newton wireless mouse

hrvach, 2025-02-25:
Apologies for the delayed response, work is a bit overwhelming lately. Can you try another "plain" wired keyboard and mouse for starters, to rule out hw is faulty? I'm not sure the logitech multi-device concept is compatible with this, you shouldn't be required to switch anything on the logitech but simply plug both computers as the output and the keyboard as the input.

apsessoms, 2025-03-11:
it was my cable. one was data. one was not. 🤣

hrvach, 2025-03-18:
Thanks for providing this data point and behavior description, I never thought to blame the cable. Might put this in the wiki as symptoms + possible reason. Glad to hear it's working for you!

Closed 2025-03-18.

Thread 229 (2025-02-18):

Power problem and Force KDB Boot Protocol option

e4zyphil, 2025-02-18:
Thanks a ton for this great device and software! :)

I have a few problems with my keyboard. (Wooting 60HE)
I think it might draw too much power, which forces me into "Force KDB Boot Protocol"-mode, which then introduces a couple of different bugs.
Also I can't access it's configuration web page. (https://wootility.io)

About the power:
Keystrokes are repeated, which got worse when I increased the brightness of the backlit keys.
However this keeps happening and makes typing unusable when I turn off the LEDs completely.
This also happened with a KVM switch I used previously of amazon (https://www.amazon.de/dp/B0CHY8L11W), until I attached a additional USB cable for power supply. I'm thinking about how I could achieve this for this project? Maybe with a USB splitter on either the input or output side?

About the "Force KDB Boot Protocol"-option:
Most of my FN keys completely stopped working (media keys, controlling volume and opening my calc).
Some others are extremely delayed and I have to spam them for the PC to pick up. (e.g. FN+P bound to F13)

Whatever the mode, I can't configure the keyboard on the config page for it, which makes it hard to test a few other features which I suspect might also stopped working. (Rapid trigger)

Kind of related to the power problem is, when I turn off my work pc, the USB-A hub on his side loses it's power and I can't use my mouse anymore. Just attaching a usb cable as a power cable from my monitor added a sporadic wild spinning of the mouse. So atm I just keep my work pc on all the time. :D

Would greatly appreciate your help!

hrvach, 2025-02-25:
Ok, so - being unable to access the keyboard config page is by design. For security reasons, only information from the computer to the keyboard is allowed and no proxying to the keyboard is done. This is a bit inconvenient, but provides a much safer environment when connecting different systems/computers together (please check readme for a more detailed explanation).

In boot kdb mode, this is expected - only basic keyboard functionality works in that one. For the power issues, a larger capacitor would likely help, but the standard limits the amount of capacity you are supposed to put in there, so it's a compromise. Perhaps try an old powered usb 1.1/2.0 hub, but don't invest a lot of money in it because hub support is a bit flaky. My hub works for example, but a lot of folks complained theirs don't.

I'm fairly certain you picked this very keyboard because you really love it, so I'm not going to suggest you use another keyboard - everyone is attached to their own gear :) I'd advise to first try getting a shorter/different cables and see if that results in any improvement.

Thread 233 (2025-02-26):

Failed to open device in Config Mode under Linux

dan-m8t, 2025-02-26:
Hi!

First let me thank you for this awesome project! I bought my deskhop from elecrow. I flashed the firmware as suggested and it worked out of the box. Then I wanted to configure monitor positions because output A is my Linux machine on the left, output B my windows work machine. Pressing left ctrl + right shift + c + o works fine under Linux, I can see the mounted drive with the config html file. I tried both Chromium and Chrome and get this error after pairing and clicking on "read":

```
Uncaught (in promise) NotAllowedError: Failed to open the device.
```
To configure it for my needs I just switched the outputs, so the USB drive gets mounted to my windows machine. This works like a charm, I was able to configure the deskhop as need but would like to configure it under my Linux machine.

Any hint?

OS: Arch
kernel: 6.13.4-zen1-1-zen

Google Chrome: Version 133.0.6943.141 (Official Build) (64-bit)

hrvach, 2025-02-27:
There is some guidance in the documentation to get the config to work:

A: You probably need to tweak /dev permissions or create a corresponding udev rules file and make sure your user is in the right group, like so:

/etc/udev/rules.d/99-deskhop.rules

KERNEL=="hidraw*", SUBSYSTEM=="hidraw", ATTRS{idVendor}=="1209", ATTRS{idProduct}=="c000", GROUP="plugdev", MODE="0660"

Let me know if it helps.

dan-m8t, 2025-02-27:
Thank you for the response. This didn't work for me sadly. Strange behaviour though: While in gaming mode and then hitting left ctrl + right shift + c + o for config mode the mouse just stopped working. Keyboard is fine, needed to exit gaming mode several times or replug usb  to get it to work again. I cannot see any message in dmesg or udevadm monitor that shows errors or something mh...besides that my Caps Lock LED isn't flashing nor working anymore while connected to DeskHop.

I use the 8bitdo Retro Keyboard with 2,4Ghz dongle attached to deskhop, probably this is the issue, but I don't have a usb c to a cable right now to test if this would solve this issue.

dan-m8t, 2025-03-01:
This fixed my issue! Thanks!

My mouse is still not working while in gaming mode and then entering config mode though, maybe this is a bug? Exiting gaming mode, then go back into config mode leaves the mouse working though. I will close this as fixed.

Closed 2025-03-01.

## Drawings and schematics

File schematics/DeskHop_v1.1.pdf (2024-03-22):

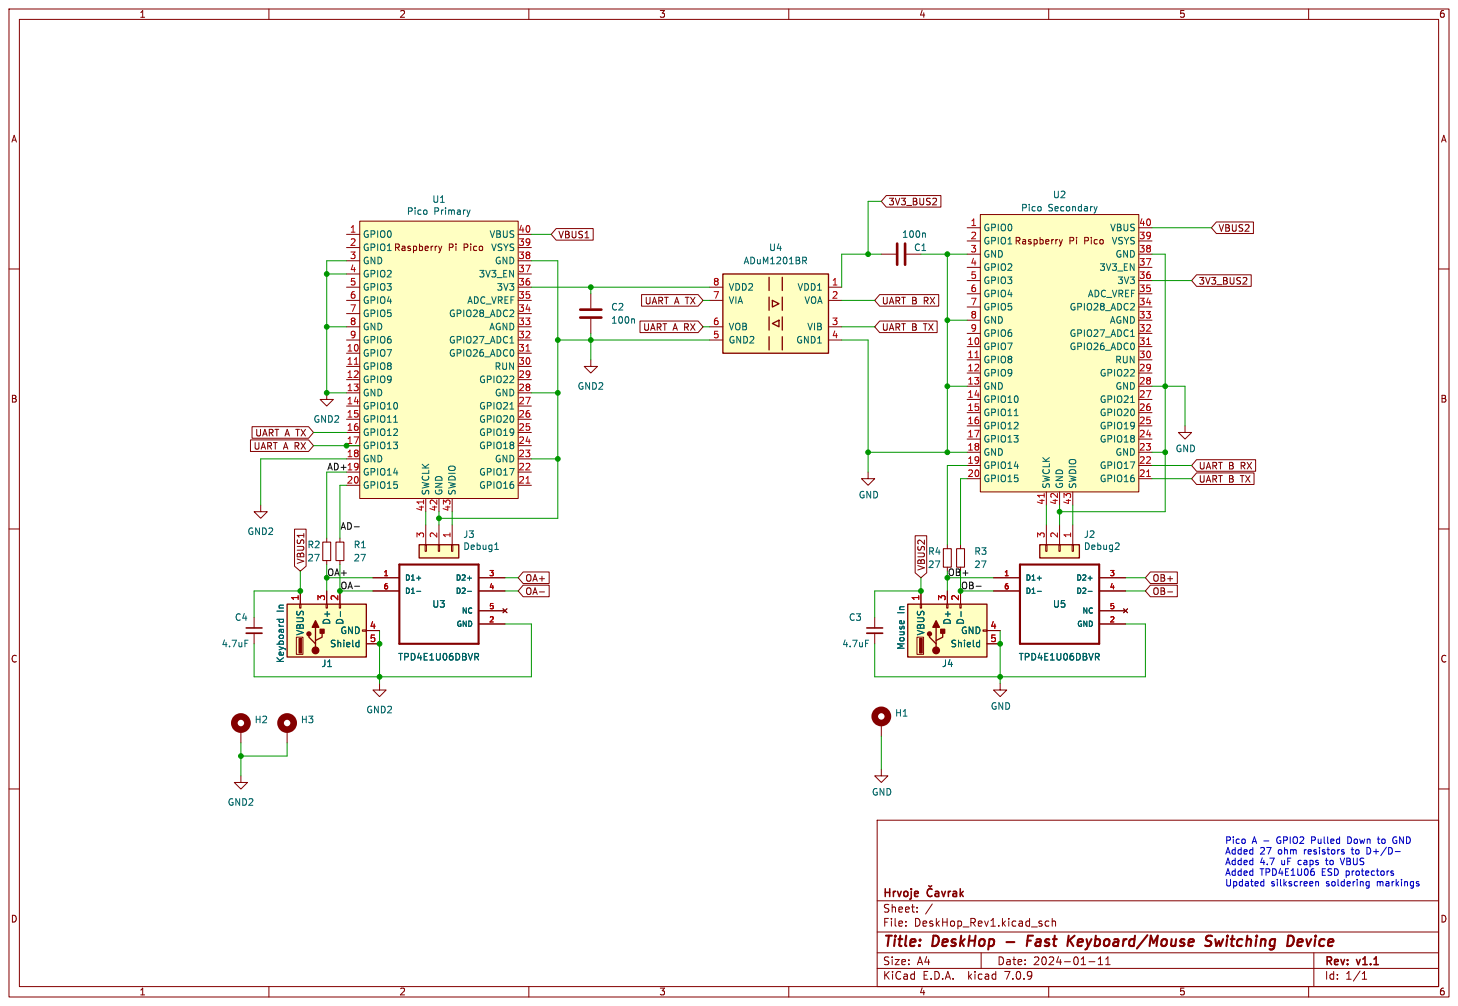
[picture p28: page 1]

File: DeskHop_Rev1.kicad_sch Sheet: / Hrvoje þÿavrak R3

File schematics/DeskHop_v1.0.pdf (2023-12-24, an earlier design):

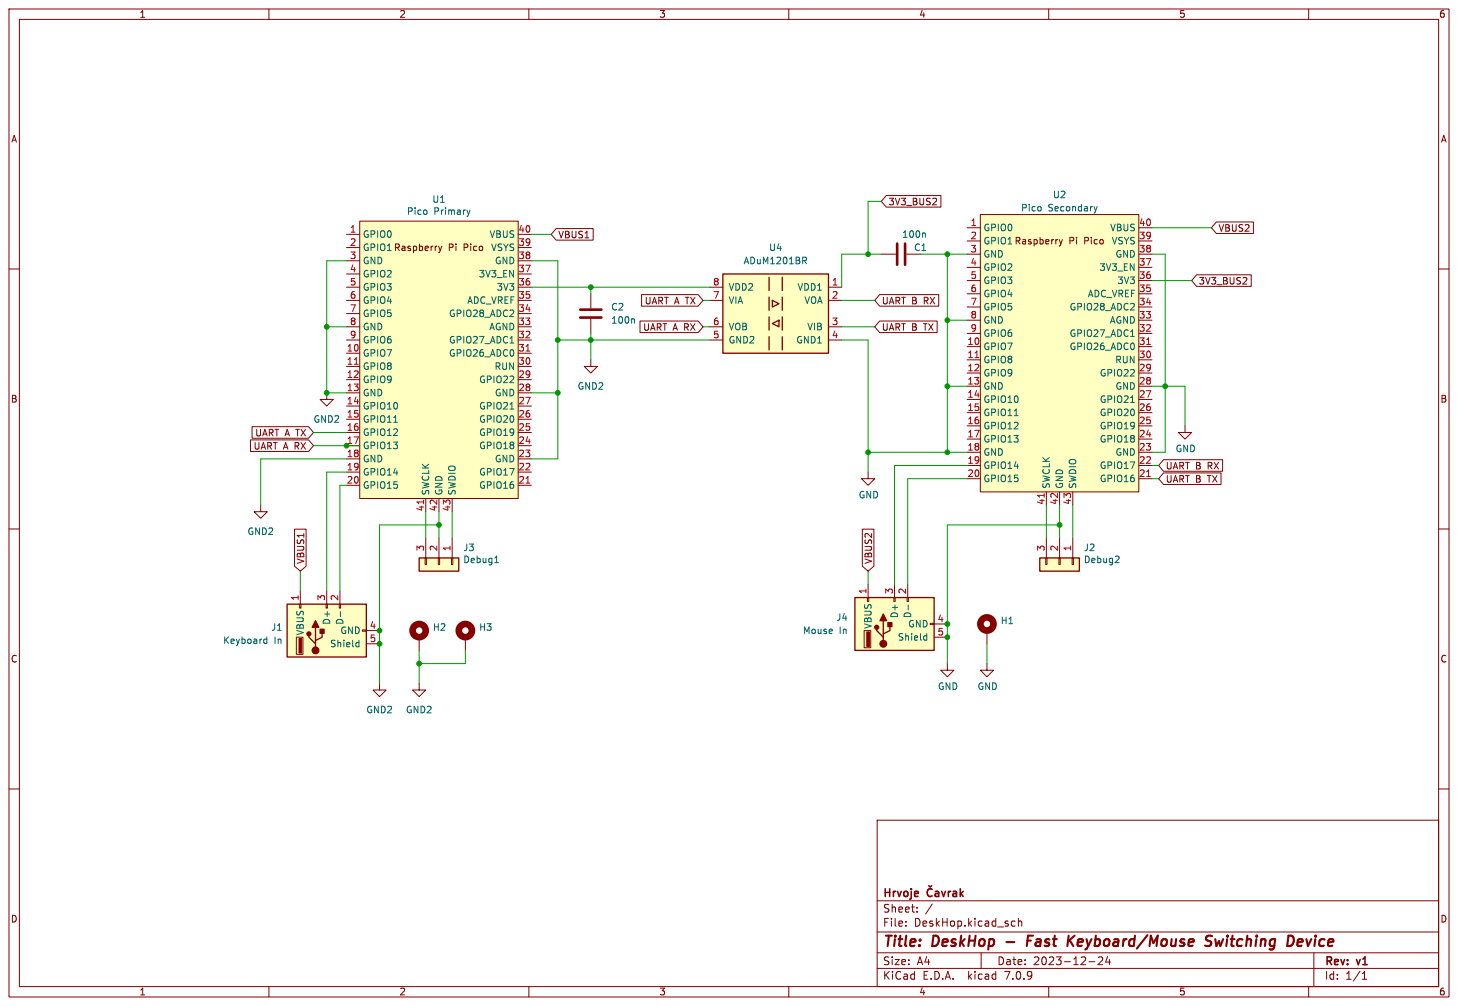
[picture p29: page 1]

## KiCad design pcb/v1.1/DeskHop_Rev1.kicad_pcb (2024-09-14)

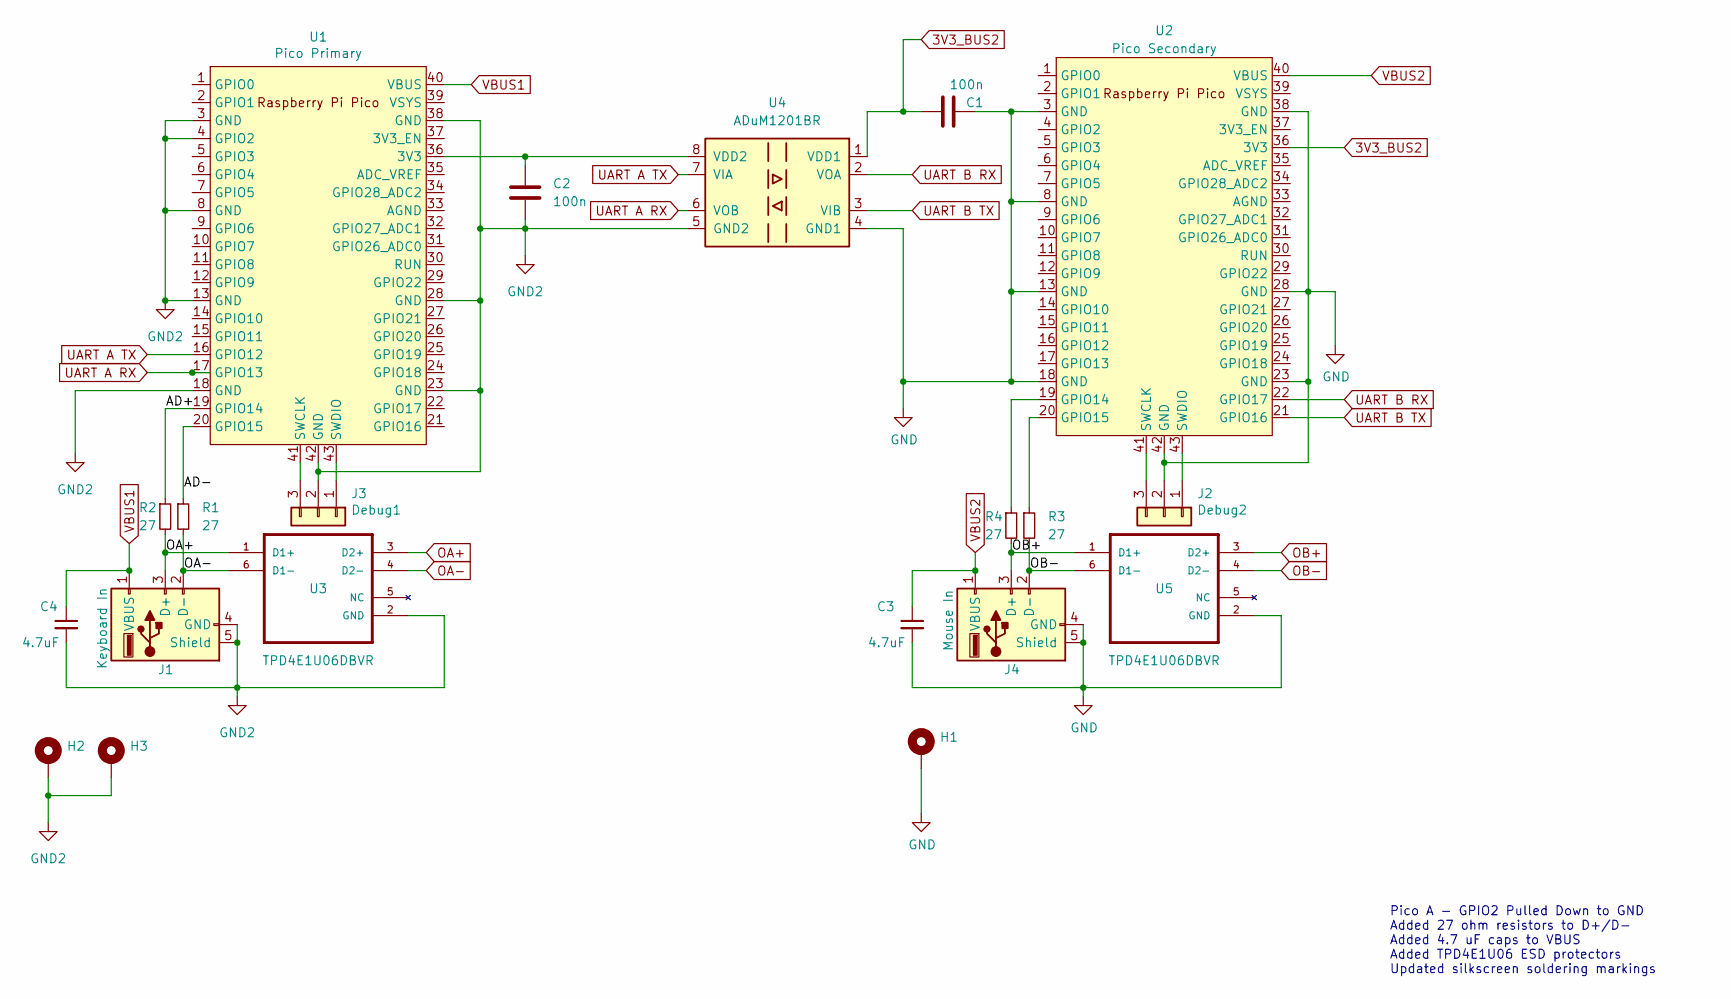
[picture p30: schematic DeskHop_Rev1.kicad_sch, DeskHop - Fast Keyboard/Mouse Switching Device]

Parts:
C1, C2: 100n; C_0805_2012Metric
C3, C4: 4.7uF; C_0805_2012Metric
H1, H2, H3: MountingHole_Pad; MountingHole_2.7mm_M2.5_Pad_TopBottom
J1: Keyboard In; USB_A_Molex_67643_Horizontal
J2: Debug2; PinHeader_1x03_P2.54mm_Vertical
J3: Debug1; PinHeader_1x03_P2.54mm_Vertical
J4: Mouse In; USB_A_Molex_67643_Horizontal
R1, R2, R3, R4: 27; R_0805_2012Metric
U1: Pico Primary; RPi_Pico_SMD_TH
U2: Pico Secondary; RPi_Pico_SMD_TH
U3, U5: TPD4E1U06DBVR
U4: ADuM1201BR; SOIC-8_3.9x4.9mm_P1.27mm

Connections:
3V3_BUS2: C1.1, U2.36 (3V3), U4.1 (VDD1)
/AD+: R2.1, U1.19 (GPIO14)
/AD-: R1.1, U1.20 (GPIO15)
GND: C1.2, C3.2, H1.1, J2.2, J4.4 (GND), J4.5 (Shield), U2.3 (GND), U2.8 (GND), U2.13 (GND), U2.18 (GND), U2.23 (GND), U2.28 (GND), U2.38 (GND), U2.42 (GND), U4.4 (GND1), U5.2 (GND)
GND2: C2.2, C4.2, H2.1, H3.1, J1.4 (GND), J1.5 (Shield), J3.2, U1.3 (GND), U1.4 (GPIO2), U1.8 (GND), U1.13 (GND), U1.18 (GND), U1.23 (GND), U1.28 (GND), U1.38 (GND), U1.42 (GND), U3.2 (GND), U4.5 (GND2)
unnamed: J2.1, U2.43 (SWDIO)
unnamed: J2.3, U2.41 (SWCLK)
unnamed: J3.1, U1.43 (SWDIO)
unnamed: J3.3, U1.41 (SWCLK)
unnamed: C2.1, U1.36 (3V3), U4.8 (VDD2)
unnamed: R4.1, U2.19 (GPIO14)
unnamed: R3.1, U2.20 (GPIO15)
OA+: J1.3 (D+), R2.2, U3.1 (D1+), U3.3 (D2+)
OA-: J1.2 (D-), R1.2, U3.4 (D2-), U3.6 (D1-)
OB+: J4.3 (D+), R4.2, U5.1 (D1+), U5.3 (D2+)
OB-: J4.2 (D-), R3.2, U5.4 (D2-), U5.6 (D1-)
UART A RX: U1.17 (GPIO13), U4.6 (VOB)
UART A TX: U1.16 (GPIO12), U4.7 (VIA)
UART B RX: U2.22 (GPIO17), U4.2 (VOA)
UART B TX: U2.21 (GPIO16), U4.3 (VIB)
VBUS1: C4.1, J1.1 (VBUS), U1.40 (VBUS)
VBUS2: C3.1, J4.1 (VBUS), U2.40 (VBUS)

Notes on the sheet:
Pico A - GPIO2 Pulled Down to GND Added 27 ohm resistors to D+/D- Added 4.7 uF caps to VBUS Added TPD4E1U06 ESD protectors Updated silkscreen soldering markings

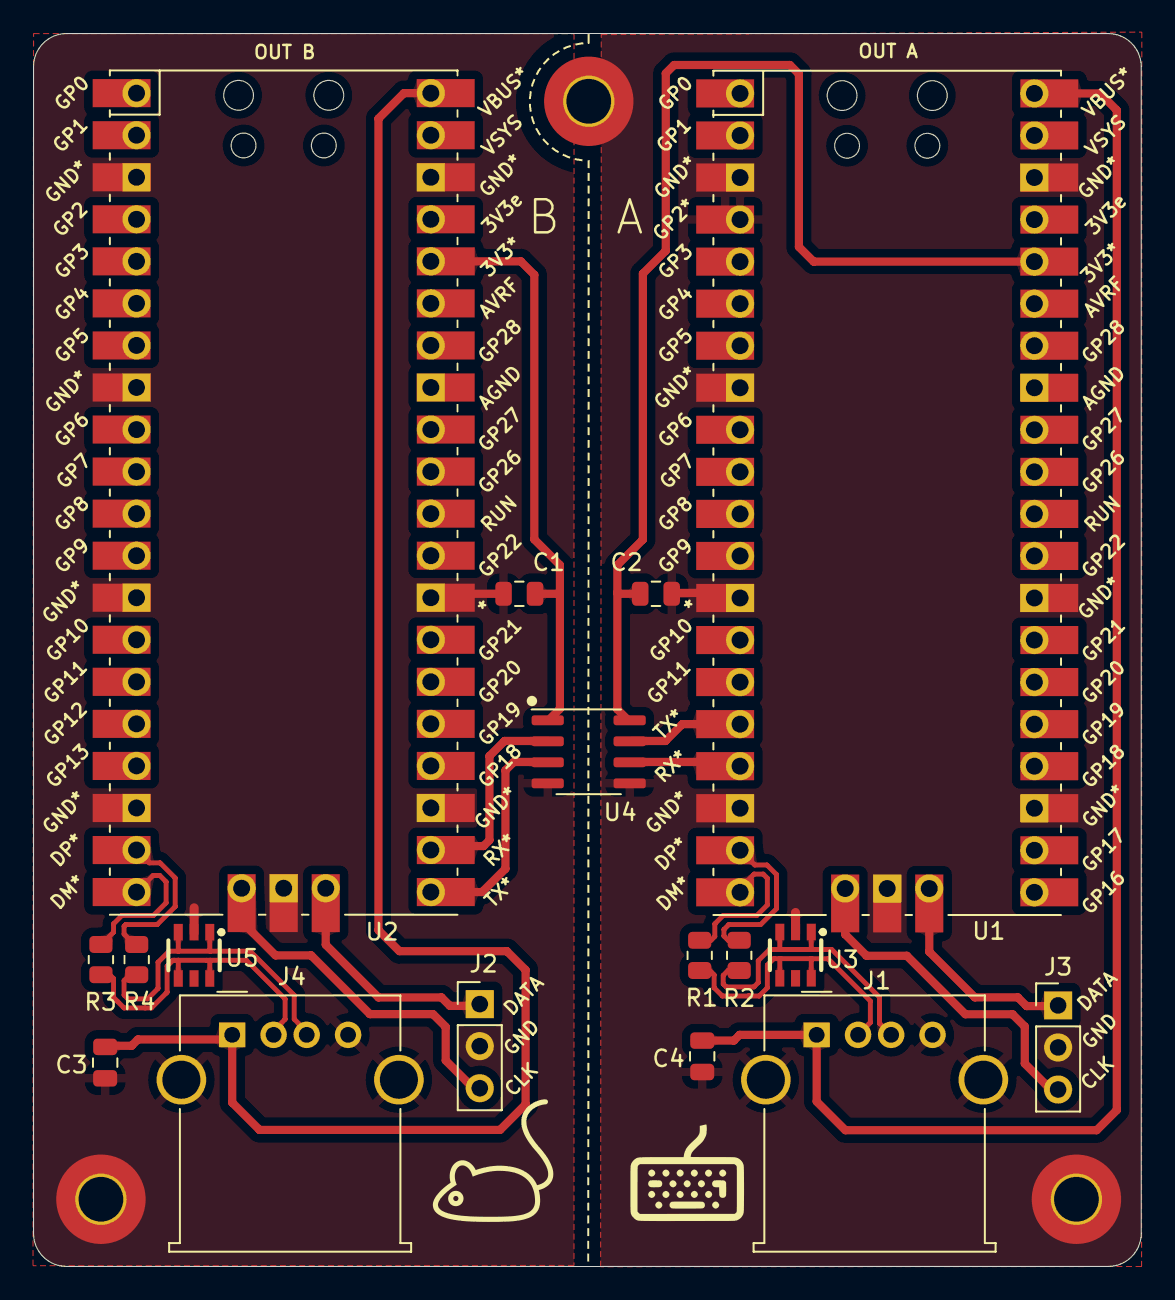
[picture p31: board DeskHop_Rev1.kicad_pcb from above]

Board: 2 copper layers, 66.9 x 74.5 mm, 20 parts (0 on the bottom side), 22 nets.

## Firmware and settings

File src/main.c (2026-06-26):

/*
 * This file is part of DeskHop (https://github.com/hrvach/deskhop).
 * Copyright (c) 2025 Hrvoje Cavrak
 *
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
 * See the file LICENSE for the full license text.
 */
#include "main.h"

/*********  Global Variables  **********/
device_t global_state     = {0};
device_t *device          = &global_state;

firmware_metadata_t _firmware_metadata __attribute__((section(".section_metadata"))) = {
    .version = 0x0001,
};

/* ================================================== *
 * ==============  Main Program Loops  ============== *
 * ================================================== */

int main(void) {
    static task_t tasks_core0[] = {
        [0] = {.exec = &usb_device_task,          .frequency = _TOP()},      // .-> USB device task, needs to run as often as possible
        [1] = {.exec = &kick_watchdog_task,       .frequency = _HZ(30)},     // | Verify core1 is still running and if so, reset watchdog timer
        [2] = {.exec = &process_kbd_queue_task,   .frequency = _HZ(2000)},   // | Check if there were any keypresses and send them
        [3] = {.exec = &process_mouse_queue_task, .frequency = _HZ(2000)},   // | Check if there were any mouse movements and send them
        [4] = {.exec = &process_hid_queue_task,   .frequency = _HZ(1000)},   // | Check if there are any packets to send over vendor link
        [5] = {.exec = &process_uart_tx_task,     .frequency = _TOP()},      // | Check if there are any packets to send over UART
    };                                                                       // `----- then go back and repeat forever
    const int NUM_TASKS = ARRAY_SIZE(tasks_core0);

    // Wait for the board to settle
    sleep_ms(10);

    // Initial board setup
    initial_setup(device);

    // Initial state, A is the default output
    set_active_output(device, OUTPUT_A);

    while (true) {
        for (int i = 0; i < NUM_TASKS; i++)
            task_scheduler(device, &tasks_core0[i]);
    }
}

void core1_main() {
    static task_t tasks_core1[] = {
        [0] = {.exec = &usb_host_task,           .frequency = _TOP()},       // .-> USB host task, needs to run as often as possible
        [1] = {.exec = &packet_receiver_task,    .frequency = _TOP()},       // | Receive data over serial from the other board
        [2] = {.exec = &led_blinking_task,       .frequency = _HZ(30)},      // | Check if LED needs blinking
        [3] = {.exec = &led_sync_task,           .frequency = _HZ(30)},      // | Sync LED state if needed
        [4] = {.exec = &screensaver_task,        .frequency = _HZ(120)},     // | Handle "screensaver" movements
        [5] = {.exec = &firmware_upgrade_task,   .frequency = _HZ(4000)},    // | Send firmware to the other board if needed
        [6] = {.exec = &heartbeat_output_task,   .frequency = _HZ(1)},       // | Output periodic heartbeats
    };                                                                       // `----- then go back and repeat forever
    const int NUM_TASKS = ARRAY_SIZE(tasks_core1);

    while (true) {
        // Update the timestamp, so core0 can figure out if we're dead
        device->core1_last_loop_pass = time_us_32();

        for (int i = 0; i < NUM_TASKS; i++)
            task_scheduler(device, &tasks_core1[i]);
    }
}
/* =======  End of Main Program Loops  ======= */

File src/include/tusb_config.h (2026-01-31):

/*
 * This file is part of DeskHop (https://github.com/hrvach/deskhop).
 * Copyright (c) 2025 Hrvoje Cavrak
 * Based on the example by Ha Thach
 *
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
 * See the file LICENSE for the full license text.
 */

#ifndef _TUSB_CONFIG_H_
#define _TUSB_CONFIG_H_

/*==============================================================================
 *  Common Configuration
 *  Settings applicable to both device and host modes.
 *==============================================================================*/

#define CFG_TUSB_OS OPT_OS_PICO

/*==============================================================================
 *  Device Mode Configuration
 *  Settings specific to USB device mode operation.
 *==============================================================================*/

// Enable the TinyUSB device stack.
#define CFG_TUD_ENABLED 1

// Root Hub port number used for the device (typically port 0).
#define BOARD_TUD_RHPORT 0

// Device mode configuration: sets the mode (device) and speed.
#define CFG_TUSB_RHPORT0_MODE (OPT_MODE_DEVICE | BOARD_DEVICE_RHPORT_SPEED)

// Root Hub port maximum operational speed (defaults to Full Speed).
#ifndef BOARD_DEVICE_RHPORT_SPEED
#define BOARD_DEVICE_RHPORT_SPEED OPT_MODE_FULL_SPEED
#endif

// Root Hub port number (defaults to 0).
#ifndef BOARD_DEVICE_RHPORT_NUM
#define BOARD_DEVICE_RHPORT_NUM 0
#endif

/*==============================================================================
 *  Host Mode Configuration
 *  Settings specific to USB host mode operation.
 *==============================================================================*/

// Enable the TinyUSB host stack (requires Pico-PIO-USB).
#define CFG_TUH_ENABLED     1
#define CFG_TUH_RPI_PIO_USB 1

// Root Hub port number used for the host (typically port 1).
#define BOARD_TUH_RHPORT 1
// Host mode configuration: sets the mode (host) and speed
#define CFG_TUSB_RHPORT1_MODE (OPT_MODE_HOST | BOARD_DEVICE_RHPORT_SPEED)

/*==============================================================================
 *  Memory Configuration
 *  Settings for USB memory sections and alignment.
 *==============================================================================*/

// Define a custom memory section for USB buffers (optional).
#ifndef CFG_TUSB_MEM_SECTION
#define CFG_TUSB_MEM_SECTION
#endif

// Define the memory alignment for USB buffers (typically 4-byte aligned).
#ifndef CFG_TUSB_MEM_ALIGN
#define CFG_TUSB_MEM_ALIGN __attribute__((aligned(4)))
#endif

/*==============================================================================
 *  Device: Endpoint 0 Size
 *  Configuration for the default control endpoint (Endpoint 0).
 *==============================================================================*/

// Size of the control endpoint (Endpoint 0) buffer.
#ifndef CFG_TUD_ENDPOINT0_SIZE
#define CFG_TUD_ENDPOINT0_SIZE 64
#endif

/*==============================================================================
 *  Device: CDC Class Configuration (Serial Communication)
 *  Settings for the CDC (Communication Device Class) for serial communication.
 *==============================================================================*/

#ifdef DH_DEBUG

// Enable CDC class for debugging over serial.
#define CFG_TUD_CDC           1

// Use a custom debug printf function.
#define CFG_TUSB_DEBUG_PRINTF dh_debug_printf
extern int dh_debug_printf(const char *__restrict __format, ...);

// Buffer sizes for CDC RX and TX.
#define CFG_TUD_CDC_RX_BUFSIZE 64
#define CFG_TUD_CDC_TX_BUFSIZE 64

// Line coding settings to use on CDC enumeration.
#define CFG_TUH_CDC_LINE_CODING_ON_ENUM \
    { 921600, CDC_LINE_CONDING_STOP_BITS_1, CDC_LINE_CONDING_PARITY_NONE, 8 }

#else
// Disable CDC class when not debugging.
#define CFG_TUD_CDC 0
#endif

/*==============================================================================
 *  Device: Class Configuration
 *  Enable/disable various USB device classes.
 *==============================================================================*/

// Enable HID (Human Interface Device) class (keyboard, mouse, etc.).
#define CFG_TUD_HID    3

// Enable MSC (Mass Storage Class) class.
#define CFG_TUD_MSC    1

/*==============================================================================
 *  Device: Endpoint Buffer Sizes
 *  Configuration for endpoint buffer sizes for different classes.
 *==============================================================================*/

// HID endpoint buffer size (must be large enough for report ID + data).
#define CFG_TUD_HID_EP_BUFSIZE 32

// MSC endpoint buffer size.
#define CFG_TUD_MSC_EP_BUFSIZE 512

/*==============================================================================
 *  Host: Enumeration Buffer Size
 *  Configuration for the buffer used during device enumeration.
 *==============================================================================*/

#define CFG_TUH_ENUMERATION_BUFSIZE 512
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

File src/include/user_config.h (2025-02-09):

/*
 * This file is part of DeskHop (https://github.com/hrvach/deskhop).
 * Copyright (c) 2025 Hrvoje Cavrak
 *
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
 * See the file LICENSE for the full license text.
 *
 **===================================================== *
 * ==========  Keyboard LED Output Indicator  ========== *
 * ===================================================== *
 *
 * If you are willing to give up on using the keyboard LEDs for their original purpose,
 * you can use them as a convenient way to indicate which output is selected.
 *
 * KBD_LED_AS_INDICATOR set to 0 will use the keyboard LEDs as normal.
 * KBD_LED_AS_INDICATOR set to 1 will use the Caps Lock LED as indicator.
 *
 * */

#define KBD_LED_AS_INDICATOR 0

/**===================================================== *
 * ===========  Hotkey for output switching  =========== *
 * ===================================================== *
 *
 * Everyone is different, I prefer to use caps lock because I HATE SHOUTING :)
 * You might prefer something else. Pick something from the list found at:
 *
 * https://github.com/hathach/tinyusb/blob/master/src/class/hid/hid.h
 *
 * defined as HID_KEY_<something>
 *
 * In addition, there is an optional modifier you can use for the hotkey
 * switching. Currently, it's set to LEFT CTRL, you can change it by
 * redefining HOTKEY_MODIFIER here from KEYBOARD_MODIFIER_LEFTCTRL to something
 * else (check file referenced below) or HID_KEY_NONE.
 *
 * If you do not want to use a key for switching outputs, you may be tempted
 * to select HID_KEY_NONE here as well; don't do that! That code appears in many
 * HID messages and the result will be a non-functional keyboard. Instead, choose
 * a key that is unlikely to ever appear on a keyboard that you will use.
 * HID_KEY_F24 is probably a good choice as keyboards with 24 function keys
 * are rare.
 *
 * */

#define HOTKEY_MODIFIER  KEYBOARD_MODIFIER_LEFTCTRL
#define HOTKEY_TOGGLE    HID_KEY_CAPS_LOCK

/**================================================== *
 * ==============  Mouse Speed Factor  ============== *
 * ================================================== *
 *
 * This affects how fast the mouse moves.
 *
 * MOUSE_SPEED_A_FACTOR_X: [1-128], mouse moves at this speed in X direction
 * MOUSE_SPEED_A_FACTOR_Y: [1-128], mouse moves at this speed in Y direction
 *
 * JUMP_THRESHOLD: [0-32768], sets the "force" you need to use to drag the
 * mouse to another screen, 0 meaning no force needed at all, and ~500 some force
 * needed, ~1000 no accidental jumps, you need to really mean it.
 *
 * This is now configurable per-screen.
 *
 * ENABLE_ACCELERATION: [0-1], disables or enables mouse acceleration.
 *
 * */

/* Output A values, default is for the most common ~ 16:9 ratio screen */
#define MOUSE_SPEED_A_FACTOR_X 16
#define MOUSE_SPEED_A_FACTOR_Y 28

/* Output B values, default is for the most common ~ 16:9 ratio screen */
#define MOUSE_SPEED_B_FACTOR_X 16
#define MOUSE_SPEED_B_FACTOR_Y 28

#define JUMP_THRESHOLD 0

/* Mouse acceleration */
#define ENABLE_ACCELERATION 1

/**================================================== *
 * ==============  Screensaver Config  ============== *
 * ================================================== *
 *
 * While this feature is called 'screensaver', it's not actually a
 * screensaver :) Really it's a way to ensure that some sort of mouse
 * activity will be sent to one (or both) outputs when the user has
 * not interacted with that output. This can be used to stop a
 * screensaver or screenlock from activating on the attached computer,
 * or to just watch the mouse pointer bouncing around!
 *
 * When the mode is active on an output, the pointer will jump around
 * the screen like a bouncing-ball in a Pong game (however no click
 * events will be generated, of course).
 *
 * This mode is activated by 'idle time' on a per-output basis; if the
 * mode is enabled for output B, and output B doesn't have any
 * activity for (at least) the specified idle time, then the mode will
 * be activated and will continue until the inactivity time reaches
 * the maximum (if one has been specified). This allows you to stop a
 * screensaver/screenlock from activating while you are still at your
 * desk (but just interacting with the other computer attached to
 * Deskhop), but let it activate if you leave your desk for an
 * extended period of time.
 *
 * Additionally, this mode can be automatically disabled if the output
 * is the currently-active output.
 *
 * If you only set the ENABLED options below, and leave the rest of
 * the defaults in place, then the screensaver mode will activate
 * after 4 minutes (240 seconds) of inactivity, will continue forever,
 * but will only activate on an output that is not currently
 * active.
 *
 * */

/**================================================== *
 *
 * SCREENSAVER_{A|B}_MODE: DISABLED
 *                         PONG
 *                         JITTER
 *
 * */

#define SCREENSAVER_A_MODE DISABLED
#define SCREENSAVER_B_MODE DISABLED
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

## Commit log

2023-12-27 Update README.md to describe power limitation
2023-12-30 Adding CAD files for the case design
    [deskhop_case.f3d, deskhop_case.step]
2024-01-02 Updated README with assembly guide video
2024-01-03 New features, bugfixes and optimizations
    Some of the features implemented in this release are:
    - TinyUSB used to handle HOST management as well
    - USB hub support (tried an ancient one and it worked)
    - Early and buggy support for mouse on the keyboard side
    but have no unified usb receivers to test
    - Rudimentary HID report descriptor parsing, support for
    mice that don't send wheel data unless in report protocol mode
    - Implemented queueing for keyboard/mouse messages with
    hid report send verification
    - Split firmware upgrade shortcut to two
    now it's left-shift + F12 + A + right shift to write board A
    left-shift + F12 + B + right shift to write board B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
    [handlers.c, led.c, main.c]
2024-01-05 Fixing a strange bug due to tusb_inited().
    Interesting things happen when TinyUSB is used both for host and device.
    bool tusb_inited(void)
    {
    bool ret = false;
    ret = ret || tud_inited();
    ret = ret || tuh_inited();
    return ret;
    }
    -> This is effectively tud_inited() || tuh_inited(), which is great
    but tuh_task() should check tuh_inited() not tusb_inited(). This way,
    tusb_inited() returns true when tinyusb device gets inited correctly
    and tuh_task gets stuck in an endless loop with watchdog rebooting the
    device.
    [main.c]
2024-01-11 Bugfixes and improvements: ==========================
    Added 1000 Hz polling.
    (Hopefully) fixed Logitech mouse issues
    Removed special treatment for 12 and 16-bit mice
    Increased mouse queue size
    Increased current allowance from 100mA to 500mA
    Allow mouse to wake up a suspended host
    Added memory usage print to build
    Updated README
    - Added link to troubleshooting wiki
    - Mouse polling rate chart
    - Updated known issues
    - Updates about possible PCB/assembly ordering
    [user_config.h]
2024-01-13 Update README.md
    Two additions to the silkscreen that are handy while soldering
2024-01-13 Added proper USB VID/PID
    Kindly assigned by the Raspberry Pi foundation, the project got its own
    VID/PID so removing the current "test" one and adding this one. No other
    changes.
2024-01-16 Features, bugfixes and configuration.
    - Support for storing config in flash
    - Support for keyboard and mouse in any port (hopefully)
    - Single-sided operation should work with a USB hub
    - Added mouse switch cursor height/offset simple calibration
    - Added per-screen settings support
    - Mouse speed is configurable per-screen and per-axis
    - Small fixes and cleanup
    - Added LED feedback
    - Updated documentation for usage guide
    [handlers.c, led.c, main.c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]
2024-01-21 Cleanup, Refactoring, Silkscreen update
    - Code refactor, still far from great but a bit less crappy
    - Unify behavior - Mouse Zoom feature was made toggle and
    moved from ALT to Right ALT + Right CTRL to avoid interfering
    with OS
    - Added optional screensaver "Pong" mode, prevents sleep and it's fun
    - Updated README
    - Added more visible pin1 marking on PCB for digital isolator
    - Marked pins to solder with a star *
    - Added checksum and version format support for flash config
    [DeskHop-B_Cu.gbr, DeskHop-B_Mask.gbr, DeskHop-B_Paste.gbr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]
2024-01-27 Minor updates and bugfixes
    - Mouse movements should be smoother on the other Pico
    - Reworked CMakeLists with foreach to avoid duplication
    - Increased WDT timeout
    [main.c, setup.c, uart.c]
2024-03-22 Features and fixes
    - Auto switch-lock when dragging or resizing windows.
    * This was super annoying for me, resizing a window and you
    get too close to the left border, making it shrink suddenly.
    Now if you drag while holding a mouse button pressed, it will
    not switch.
    - Added Mac OS multiple desktop workaround
    * you need to tweak defaults.c and set screen_count to e.g. 2 if
    you have 2 desktops on a single mac output, and set OUTPUT_A_OS
    (or OUTPUT_B_OS) to MACOS in user_config.h, then rebuild
    * This will be keyboard-configurable in the future without rebuilding
    * Support still experimental
    - HID report protocol default for port B
    - Adde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
    [handlers.c, setup.c]
2024-03-22 Updated README, pcb and case.
    [DeskHop-B_Cu.gbr, DeskHop-B_Mask.gbr, DeskHop-B_Paste.gbr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]
2024-03-24 - add windows workaround - add mouse acceleration (configurable in user_config.h) - add keyboard shortcuts for output configuration - after several reports, bundling pico-sdk and tinyusb to simplify 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
2024-03-31 Updates and fixes.
    - Implement fix for keyboards not switching to boot mode properly, until full report parsing gets done.
    This is expected to improve support for certain models that were reported problematic.
    - Implement fix for mouse acceleration omitting absolute mode
    - Provide pass_to_os = true to not capture shift+backspace from the OS, it's annoying when you hold shift
    and mistype something, then want to use backspace but couldn't.
    [user_config.h]
2024-04-02 fix: lets not assume remapped keys
    fixes https://github.com/hrvach/deskhop/issues/82
    [handlers.c]
2024-04-11 chore: fix screenlock
    Shortcut is always received local to the device the keyboard is
    connected to. Send command to all others.
    [handlers.c]
2024-05-13 Updates and bugfixes - Make MacOS multi-desktop workaround more reliable - Partial media keys support
    [handlers.c, uart.c]
2024-07-30 DeskHop v0.61 - Promoted RC to Stable
    - Single unified firmware binary
    - Improved support for NKRO keyboards
    - Report mode default for keyboard port
    - Improved consumer control parser for variable
    data types (media keys should be better supported)
    - System control forwarding
    - Improved HID parser
    - Web UI to configure instead of keyboard shortcuts
    - Firmware upgrade while the device remains functional
    - Only one end will need upgrade, the other will get it automatically
    - No need to recompile to set most settings
    - Improved UART routines to use DMA, more reliable link
    - Fixed a bunch of bugs and issues
    [handlers.c]
2024-08-03 DeskHop v0.62 (Minor Bugfixes) - Fixed screen lock regression bug - Cleaned up trailing spaces
    Due to MacOS having issues:
    - Moved screen lock shortcut to right control + L
    - Moved switch lock shortcut to right control + K
    [handlers.c, led.c, main.c]
2024-08-18 DeskHop 0.63 (Bugfixes, small features)
    - add gaming mode (use left shift + right shift + G to toggle)
    - rework HID queue, smoother operation of rotary dials (no packets lost)
    - fix dragging across multiple screens on the same output
    - improve read reliability for UI
    - move default keyboard hotkey for output switching to LCtrl + Caps Lock
    - change default X/Y speed to match 16:9 geometry
    [handlers.c, main.c]
2024-08-24 DeskHop v0.64 (Bugfixes)
    - Caps lock / Num lock didn't correctly remember output B state
    - Windows relative mouse was jumping from secondary to primary
    - Fixed NKRO keyboards without report ID
    - IMPORTANT: moved config shortcut to LEFT CTRL + RIGHT SHIFT + C + O
    because users had issues with keyboards unable to send both
    shifts. Sorry for changing this.
    [handlers.c]
2024-09-14 DeskHop v0.65 - Fixed bug with gaming mode
    [handlers.c, uart.c]
2024-09-14 Update PCB to fix the GND pad on board A pin 3.
    [DeskHop_Rev1-B_Cu.gbr, DeskHop_Rev1-B_Mask.gbr, DeskHop_Rev1-B_Silkscreen.gbr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]
2024-11-25 DeskHop v0.68 - Wrote a "proper" user manual - Added screensaver shortcuts - Modified descriptor from 5+3 buttons to 8 buttons - Added OSHW cert to docs - Bumped bootsel detection to debug version - 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
    [handlers.c, uart.c]
2024-11-27 Tweak macos screen switch helper
    - Increase relative mouse movement to over one screen pixel in most
    resolutions
    - Extract MacOS desktop switch helper to its own function
    - Clean up unused parameters in top-level desktop switch
2024-12-04 Use relative mouse reports for jitter screensaver mode
2024-12-04 Fix screensaver issue with rapid movement.
    [handlers.c]
2024-12-06 Fix #183 and address the change suggested by #184.
    Minor bugfix, properly determine when switching screens is needed.
2024-12-09 Allow buttons without pointer usage
2025-01-09 swap tabs for spaces
    [utils.c]
2025-01-27 Add support for device serial numbers. This should resolve #212
2025-02-09 Various bugfixes and improvements - Firmware version and checksum were incorrectly parsed. Welp, this is embarassing - struct defined u32, but struct.pack in Python helper packed it as 16-bit. ->> Mi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
    [user_config.h]
2025-02-14 keep button state when report does not contain buttons.
2025-05-11 Enables support for multiple keyboard devices
    Adds support for combining keyboard input from multiple USB HID devices and a remote UART device.
    This ensures all key presses are captured and sent, regardless of the input source. It also resolves potential issues when switching between keyboards. This is achieved by storing the keyboard state for each device and merging these states into a combined report before sending.
    [handlers.c, setup.c]
2025-08-12 Add keyboard shortcut to enable the Jitter screensaver
    Add keyboard shortcut for Jitter screensaver
    [handlers.c]
2025-08-17 Swap descriptors, make the pid.codes one standard. Requested by a few users.
2025-10-10 Track HID report offsets per report ID per USB spec
    Per USB HID spec section 6.2.2.7, each report ID defines an independent
    report structure with its own bit offset tracking. Previously, offsets
    were reset when encountering a new report ID or at collection boundaries,
    causing incorrect parsing of descriptors with multiple reports.
    Changes:
    - Add report_offset_map_t to map report IDs to their offsets
    - Track offsets separately for each report ID in parser state
    - Remove incorrect offset resets on report ID change and collection end
    - Add helper functions for offset lookup and creation
    Local items still reset after Main items and Global items persist,
    matching spec requirements.
2025-12-30 Fix incorrect HID keyboard report parsing when Report IDs are used
    The parser was incorrectly assuming that any 8-byte or 9-byte report was a
    standard Boot Protocol report (Modifier, Reserved, 6 Keys). This caused
    issues for devices like the Microsoft Ergonomic Keyboard that use Report IDs,
    as the 1-byte Report ID was being misinterpreted as the Modifier byte.
    Modified extract_kbd_data to only apply the Boot Protocol heuristic if the
    interface is confirmed not to use Report IDs.
2026-01-29 Add device_t.mouse_connected field.
2026-01-29 update interface numbers so that they dont collide in config mode; fixes desktop transitions on macos when in config mode.
    [tusb_config.h]
2026-05-11 hid_report: fall back to boot extractor when NKRO extraction fails
    Some wireless dongles (e.g. Lemokey Link, VID 0x362d PID 0xd030) advertise
    an NKRO collection in their HID descriptor but actually transmit standard
    boot-style keyboard reports: a 1-byte report ID followed by 8 bytes of
    [modifier, reserved, 6 keycodes]. The descriptor's NKRO bitmap dimensions
    do not match the actual report layout, so _extract_kbd_nkro() returns -1.
    Previously, extract_kbd_data() did not check the return value and the
    caller proceeded with a zeroed report — so the keyboard appeared to be
    working at the USB level but no keys were ever forwarded.
    This change makes extract_kbd_data() fall through to the boot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
2026-05-11 usb_descriptors: fix CDC interface numbers and total count in debug build
    When built with DH_DEBUG=ON, the configuration descriptor declared CDC at
    interface number 4 with a total interface count of 3 (normal mode) or 5
    (config mode). Both values were inconsistent with the actual descriptor
    contents:
    - Normal mode: HID(0) + HID_REL_M(1) + CDC(4, 5) - 4 interfaces, declared 3
    - Config mode: HID(0) + HID_REL_M(1) + HID_VENDOR(2) + MSC(3) + CDC(4, 5) -
    6 interfaces, declared 5
    The non-consecutive interface numbers in normal mode (0, 1, 4, 5) caused
    Windows to reject the device with CM_PROB_FAILED_START (code 10). Linux
    and macOS were more permissive and worked despite the mismatch.
    Fix by: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
2026-05-20 Fix mouse movement threshold and stuck drag during virtual desktop switches
2026-06-26 Refactor the screen switch fix
2026-06-26 - Bugfixes, range checks. - Backporting some PIO fixes for stability. - Add LED sync task and desired/actual register. Should be more reliable.
    [handlers.c, led.c, main.c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]
2026-06-27 Fix ramdisk mount bug.
2026-09-13 Give each keyboard collection on an interface its own keyboard_t
    get_keyboard() short-circuited before it could reach any slot but the first:
    if (iface->num_keyboards == 1 || !iface->uses_report_id)
    return &iface->keyboards[PRIMARY_KEYBOARD];
    num_keyboards reaches 1 on the first collection, and the allocation path below was
    never taken, so it could never exceed 1 on an interface using report IDs and
    MAX_KEYBOARDS was dead code. Every later collection was handed keyboards[0] and
    wrote over the first one.
    Some keyboards declare a plain 6KRO collection for BIOS and boot menus beside one
    or more NKRO ones, and what the collapse costs depends on which lands second. Both
    shapes turn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
2026-09-13 Trim the comments to what the code needs
    The history and the device names belong in the commit messages, where they already are.
2026-09-14 Retry a failed USB host transaction three times before failing the transfer
    The vendored Pico-PIO-USB snapshot fails a whole transfer on the first bad
    handshake, CRC or timeout. TinyUSB then retries the transfer three times
    100 ms apart and gives up, which leaves a half-enumerated device (address
    assigned, never configured) and a dead keyboard until the receiver is
    replugged. The USB spec expects the host to retry at the transaction
    level; upstream Pico-PIO-USB added that in Feb 2025.
    This backports those three commits (sekigon-gonnoc/Pico-PIO-USB 9c8df30,
    92ea116, ace22e0): a per-transfer failed_count, a limit of three
    consecutive failures, and the SETUP fix that puts data_id back so a
    ret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
    [pio_usb.c]
2026-09-21 Route boot-protocol reports by the interface, not by report[0]
    Routing chose its branch on iface->uses_report_id, which is fixed from
    the descriptor at enumeration, and never looked at iface->protocol. Once
    a force flag switched a device to boot protocol it stopped sending a
    report ID, but report[0] was still read as one. In a boot report that
    byte is the modifiers on a keyboard and the buttons on a mouse, so
    keystrokes went to report_handler[modifier], usually nowhere and on some
    receivers to the consumer or system handler, and a boot-mode mouse on a
    report-ID interface only moved while the left button was held.
    The decode side already checks HID_PROTOCOL_BOOT before consulting
    uses_report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
2026-09-21 fix: use offsetof for config checksum CRC range (#329)
    Use offsetof(config_t, checksum) to compute the exact CRC range.
    [utils.c]

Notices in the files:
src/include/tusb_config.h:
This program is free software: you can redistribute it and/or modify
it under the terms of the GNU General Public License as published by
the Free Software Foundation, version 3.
